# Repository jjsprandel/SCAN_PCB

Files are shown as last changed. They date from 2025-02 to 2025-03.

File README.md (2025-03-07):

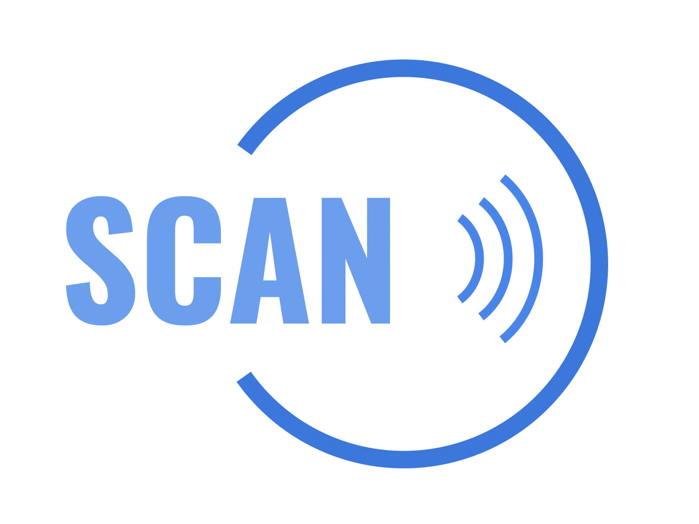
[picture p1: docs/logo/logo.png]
Project Logo
# 

Welcome to the **SCAN** repository! Below, you will find all the necessary information, from hardware design to software documentation.

---

## GitHub Workflows Status 🔧

Here are the current statuses of our GitHub workflows:

| Workflow Name | Status |
| --- | --- |
| **CI - Build** |  |
| **Docker - Test Build** |  |

- **CI - Build**: Ensures the project builds successfully.
- **CI - Tests**: Runs all unit and integration tests to ensure everything is working as expected.
- **Docker - Test Build**: Attempts Docker Build upon changes to the Dockerfile.

---

## Table of Contents 📚
- [💡 Overview](#overview)
- [🔧 Hardware Design](#hardware-design)
- [💻 Software](#software)
- [🔨 Build Instructions](#build-instructions)
- [📑 Documentation](#documentation)
- [⚙️ License](#license)

---

## 💡 Overview
 **SCAN** is a low-cost, IoT-driven kiosk system designed to provide real-time analytics based on check-in and check-out information. By integrating NFC-based authentication, real-time data processing, and a user-friendly interface, SCAN provides users with a near-effortless check-in experience and provides facilities with actionable insights for improving operations. SCAN is able to track attendance and provide detailed analytics on occupancy trends, peak usage hours, and visit durations. These insights are accessible to administrator and facility managers via SCAN’s web application, which can provide them with the necessary statistics to allocate resources efficiently, optimize staffing, and improve user experiences.

---

## 🔧 Hardware Design
<details>
  <summary><strong>📡 Schematic</strong></summary>

  Below is the schematic of the hardware design:

  Schematic
  
  **Key Features**:
  - Feature 1
  - Feature 2
  - Feature 3

  Additional hardware files can be found in the [hardware directory](hardware_design).

</details>

<details>
  <summary><strong>🔌 PCB Design</strong></summary>

  Here's the PCB design layout:

  PCB

  **Important Notes**:
  - Note about the PCB.
  - Power considerations.
  - Any important design choices.

</details>

---

## 💻 Software
<details>
  <summary><strong>💾 Firmware Overview</strong></summary>

  The firmware is designed to work with the hardware for controlling the device. You can find the code [here](path/to/firmware).

  **Key Libraries Used**:
  - Library 1
  - Library 2

</details>

<details>
  <summary><strong>📦 Installation Guide</strong></summary>

  Follow these steps to install the firmware:
  
  1. Step 1
  2. Step 2
  3. Step 3

  Detailed instructions are available in the [installation guide](link_to_guide).

</details>

---

## 🔨 Build Instructions

<details>
  <summary><strong>🛠️ Build Setup</strong></summary>

  To build the project, follow these steps:

  1. Clone the repository:
     ```bash
     git clone https://github.com/jjsprandel/SCAN.git
     ```
  2. Connect your ESP32 to your computer using USB-C. The Docker container is designed to automatically recognize the device and use port 4000 to communicate to the ESP32 for flashing.
  3. Reopen Visual Studio Code in Container. This step requires having the Docker VS Code extension installed on your host machine. 
  4. Within the container, on first run, configure the ESP-IDF extension from the list of commands that come with the ESP-IDF extension.
     4a. Select "Use existing setup."
     4b. The extension should automatically find the right tool paths and folders. Select the configuration option with the auto-filled paths.
  5. Compile the firmware:
     ```bash
     idf.py build
     ```  
      5a. Alternatively, click the wrench button at the bottom of VS Code to build.
  6. Flash the firmware:
     ```bash
     idf.py --port 'rfc2217://host.docker.internal:4000?ign_set_control' flash
     ```
      6a. Alternatively, click the lightning button at the bottom of VS Code to flash.

  **Tips**:
  - Ensure your system meets the requirements listed in the [build prerequisites](link_to_prerequisites).
  - If you encounter issues, check the [troubleshooting guide](link_to_troubleshooting).

</details>

---

## 📑 Documentation
<details>
  <summary><strong>📝 API Documentation</strong></summary>

  - **[API Reference](link_to_api_reference)**: Detailed API usage and function descriptions.
  - **[Hardware Docs](link_to_hardware_docs)**: Documentation on hardware design.

</details>

<details>
  <summary><strong>📚 Additional Resources</strong></summary>

  - **[Project Wiki](link_to_wiki)**: Explore the project wiki for more in-depth articles.
  - **[User Manual](link_to_user_manual)**: Comprehensive user guide for operation.

</details>

---

## 🔌 Dependencies

This project has the following dependencies that need to be installed:

### **Hardware Dependencies:**
- **KiCad Version**: 8.0.6 (required for schematic and PCB design)
  - Download from [KiCad official website](https://kicad.org/download/).
  
### **Software Dependencies:**
- **USB Drivers**: For proper communication with the hardware, ensure that the appropriate USB drivers are installed.
  - For Windows, you can download and install the **[CP210x USB to UART Bridge VCP drivers](https://www.silabs.com/developer-tools/usb-to-uart-bridge-vcp-drivers?tab=downloads)**.
  - For Linux, you should have the necessary drivers already built into the kernel, but check the [driver documentation](https://www.silabs.com/community/interface/usb-bridges) for troubleshooting.

- **Docker Desktop**: Required to run the ESP-IDF containerized environment.
  - Download from **[Docker Desktop website](https://www.docker.com/products/docker-desktop)**.
  - Follow the installation instructions for your operating system.
  
### **Development Tools:**
- **[Visual Studio Code](https://code.visualstudio.com/)**: Recommended IDE for editing the firmware code.

- **[Git](https://git-scm.com/)**: Version control system.

---

## ⚙️ License
SCAN © 2025 is licensed under Creative Commons Attribution-NonCommercial-NoDerivatives 4.0 International. To view a copy of this license, visit https://creativecommons.org/licenses/by-nc-nd/4.0/ or see the [LICENSE](LICENSE) file.

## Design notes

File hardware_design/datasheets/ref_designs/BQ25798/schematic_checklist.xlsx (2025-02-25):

 | BQ25790/2/8 and BQ25672 Schematic Review
 |  |  |  |  |  |  |  |  |  | BQ25792/BQ25798/BQ25672
 |  |  |  |  |  |  |  |  |  | BQ25790
 |  |  |  |  |  |  |  |  | NOTE: BQ25672 requires only 3x10uF
NOTE: All capacitors are assumed to be ceramic with voltage voltage rating = at least 2 x the pin's max expected voltage
Pin | QFN | WCSP | Opt/Rec/Req | Component | Min | Typ | Max | EXPLANATION | COMMENTS | LAYOUT GUIDANCE
VAC1 | 9 | H1 | Optional | CVAC1 |  | 100n F |  | VAC1 sense line filter capcacitor | Connect to VBUS if ACDRV1 not used.
VAC2 | 8 | G1 | Optional | CVAC2 |  | 100 nF |  | VAC2 sense line filter capcacitor | Connect to VBUS if ACDRV2 not used.
ACDRV1 | 11 | H2 | Optional | QACDRV1 |  | 30 V Nch |  | NFETs for input source MUX | Connect to ground if ACDRV1 not used.
 |  |  |  | DACDRV1 |  | 12V |  | Zener clamp to protect FET gate
 |  |  |  | RACDRV1 |  | 294 Ω |  | Softstart resistor
 |  |  |  | CACDRV1 |  | 1 nF |  | Softstart capacitor
ACDRV2 | 10 | G2 | Optional | QACDRV2 |  | 30 V Nch |  | NFETs for input source MUX | Connect to ground if ACDRV2 not used.
 |  |  |  | DACDRV2 |  | 12V |  | Zener clamp to protect FET gate
 |  |  |  | RACDRV2 |  | 294 Ω |  | Softstart resistor
 |  |  |  | CACDRV2 |  | 1 nF |  | Softstart capacitor
VBUS | 2,3 | A1,B1, C1 | Required | CVBUS-BYP |  | 0.1 uF |  | VBUS high frequency noise bypass capacitor
 |  |  | Required | CVBUS-BULK |  | 2 x 10uF |  | VBUS bulk capacitors
REGN | 5 | E1 | Required | CREGN | 4.7 uF |  |  | REGN linear regulation output capacitor |  | Place close to REGN pin and PGND, priority 2.
PMID | 29 | A2,B2,C2,D2,E2 | Required | CPMID-BYP |  | 0.1 uF |  | PMID high frequency noise bypass capacitor | Critical for device operation and minimizing EMI. | Place as close as possible to PMID and GND pins using as few vias as possible, priority 1
 |  |  | Required | CPMID-BULK |  | 3 x 10uF* |  | PMID bulk capacitors | Input capacitance for the converter *BQ25796 requires 2 additional, parallel 33 uF low ESR polarized capacitors | Place as close as possible to PMID and GND pins using as few vias as possible, priority 1
SYS | 25 | A6,B6,C6,D6,E6 | Required | CSYS-BYP |  | 0.1 uF |  | SYS high frequency noise bypass capacitor | Critical for device operation and minimizing EMI | Place as close as possible to SYS and GND pins using as few vias as possible, priority 1
 |  |  | Required | CSYS-BULK |  | 5 x 10uF -79x 3 x 10uF -672 |  | SYS bulk capacitors | Output capacitance for the converter | Place as close as possible to SYS and GND pins using as few vias as possible, priority 1
BAT | 22,23 | A7,B7,C7,D7,E7 | Required | CBAT |  | 2 x 10uF |  | BAT bulk capacitors |  | Place close to BAT pin and PGND, priority 2.
BATP | 18 | G7 | Required | RBATP |  | 100 Ω |  | BAT+ remote sense isolation resistor | Can short to IC BAT pin if remote sense not needed.
SW1 | 28 | A3,B3,C3,D3,E3 | Required | L1 | 1 uH |  | 2.2 uH | Inductor buck side connection | 1 uH for fSW = 1.5 MHz and 2.2 uH for fSW = 750 kHz | Required to route SWx traces under the IC and then uses vias to connect to inductor if on top layer.
 |  |  | Optional | RSNUB1, CSNUB1 |  | not shown |  | RC snubber to reduce EMI | 603 footprint components, sized on working PCB using empirical measurements. Decreases efficiency by ~0.5% when properly sized | Place close to SWx and PGND, priority 1. If placed on bottom layer, use multiple vias back to top.
BTST1 | 4 | D1 | Required | CBTST1 |  | 0.047 uF |  | Bootstrap capacitor for buck side FET gate drive
SW2 | 26 | A5,B5,C5,D5,E5 | Required | L1 | 1 uH |  | 2.2 uH | Inductor boost side connection | 1 uH for fSW = 1.5 MHz and 2.2 uH for fSW = 750 kHz | Required to route SWx traces under the IC and then uses vias to connect to inductor if on top layer.
 |  |  | Optional | RSNUB2, CSNUB2 |  | not shown |  | RC snubber to reduce EMI | 603 footprint components, sized on working PCB using empirical measurements. Decreases efficiency by ~0.5% when properly sized | Place close to SWx and PGND, priority 1. If placed on bottom layer, use multiple vias back to top.
BTST2 | 19 | F7 | Required | CBTST2 |  | 0.047 uF |  | Bootstrap capacitor for boost side FET gate drive
PROG | 20 | F5 | Required | RPROG |  | *Ω |  | Sets default converter switching frequency and either 1S, 2S, 3S or 4S charging | See datasheet section titled PROG Pin Configuration for resistor sizes
ILIM_HIZ | 17 | F4 | Required | RLIM |  | *Ω |  | Program ILIM_HIZ voltage to set desired IINDPM by connecting a resistor divider from pull up rail to ILIM_HIZ pin then 100 kW resistor to ground. When the pin voltage is below 0.75V, the buck-boost converter enters non-switching mode with REGN on. | VILIM_HIZ = 1V + 800 mW x IINDPMmax IINDPM I2C register can be written to lower value. ILIM_HIZ can be disabled in I2C. ILIM_HIZ can be pulled directly to REGN to set max I2C register value (3.3A).
TS | 16 | H7 | Required (if not disabled in I2C register) | RTS-TOP |  | *Ω |  | Resistor divider to set window for thermistor temperature-based battery charging profile | If TS feature not used, use equations to set V(TS) to ~60% of VREF to hardware disable or I2C bit to software disable.
 |  |  | Required (if not disabled in I2C register) | RTS-BOT |  | *Ω |  |  |  | Connect RTS_BOT to AGND. Kelvin connect resistor divider midpoint to pin routed away from traces/pours/planes with switching noise.
STAT | 1 | F1 | Recommended | RSTAT |  | 2.2 kΩ |  | LED pull up resistor for open drain STAT pin.
 |  |  | Optional | DSTAT |  | green or red |  | Charging status indicating LED
SDRV | 24 | F6 | Optional | QSDRV |  | 30 V Nch |  | The driver pin of the external ship FET. The ship FET is always turned on when ship mode is disabled, and it keeps off when the charger is in ship mode or shutdown mode. | Connect a 0402 / 50V / 1nF ceramic capacitor from SDRV to BAT or GND when the ship FET is not used.
/CE | 13 | G4 | Required | RPULLUP | 2.2 kW |  | 10 kW | Active low, open drain charge enable | Can be tied to GND but recommended to be tied to host GPIO with pull up resistor. Cannot be left floating.
/INT | 21 | G5 | Optional | RPULLUP | 2.2 kW |  | 10 kW | Active low, open drain INT pulse | Can be left floating but recommend to to tied to host GPIO with pull up resistor.
/QON | 12 | G3 | Optional |  |  |  |  | A logic low on this pin with tSM_EXIT duration turns on ship FET to force the device to exit the ship mode. A logic low on this pin with tRST duration resets system power by turning off the ship FET for tRST_SFET (also setting the charger in HIZ mode when VBUS is high) and then turning on ship FET (also disabling the charger HIZ mode) to provide full system power reset | The pin has an internal pull up so it not used it should be left floating. Can be tied to a mechanical push button or host GPIO.
SDA | 15 | H5 | Required | RPULLUP | 2.2 kW |  | 10 kW | I2C data line | Needs pull up resistor to 1.8 V to 3.3 V
SCL | 14 | H4 | Required | RPULLUP | 2.2 kW |  | 10 kW | I2C clock like | Needs pull up resistor to 1.8 V to 3.3 V
D+ | 6 | F2 | Optional |  |  |  |  | USB BC 1.2 communication lines | Connect to USB port in order to set charger input current (IINDPM) register to port capability per USB BC 1.2 spec. Host is expected to perform enumeration. If not used, leave floating for unkown adapter and IINDPM=3A. ILIM_HIZ resistor clamps maximum input current.
D- | 7 | F3 | Optional
BATN (790 only) | na | G6 | Required | RBATN |  | 100 Ω |  | BAT- remote sense isolation resistor | Can short to IC GND pin if remote sense not needed.
/PG (790 only) | na | H3 | Optional | RPULLUP | 2.2 kW |  | 10 kW | Active low, open drain input power good indicator | Can be left floating but recommend to to tied to host GPIO with pull up resistor.
IBAT (790 only) | na | H6 | Optional | RIBATP |  | 10 kW |  | Current source output proivding 25 uA per 1A charge current. | Parallel 100 pF capacitor is recommended to minimize ripple.
GND | 27 | A4,B4,C4,D4,E4 | Required |  |  |  |  | IC GND return | Separate PGND and AGND, connected only at GND pins is recommended by not required as long as power path (VBUS, PMID, SYS, BAT) grounds are routed away from AGND. REGN is technically PGND but difficult to route. | Required to route to internal/bottom layer under the IC but also provide GND trace on top layer for connecting PMID and SYS capacitor grounds

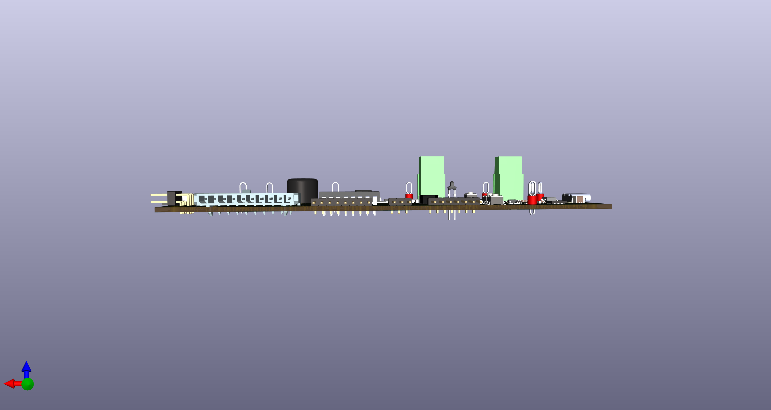
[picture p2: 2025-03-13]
hardware_design/exports/3d_models/side_3.png

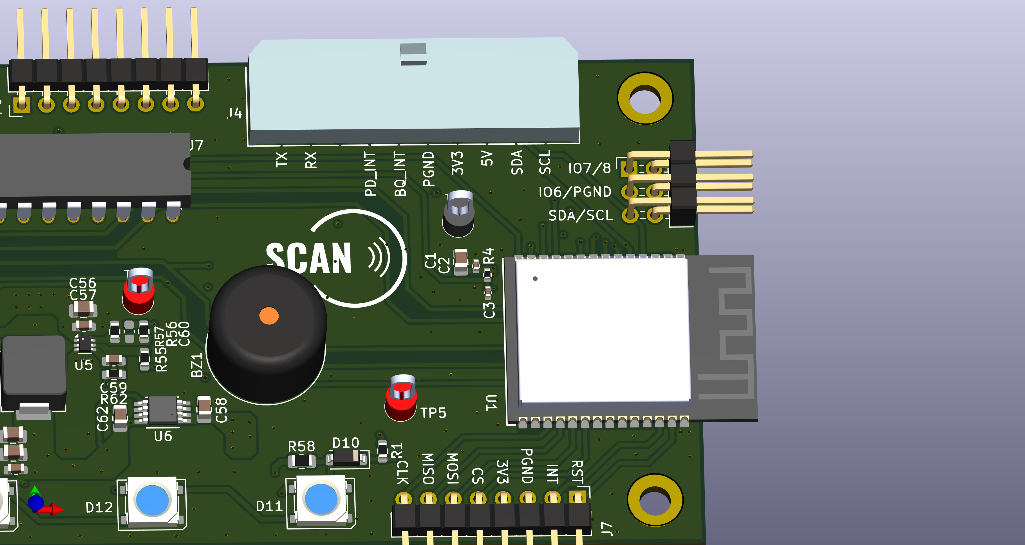
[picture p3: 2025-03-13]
hardware_design/exports/3d_models/esp32.png

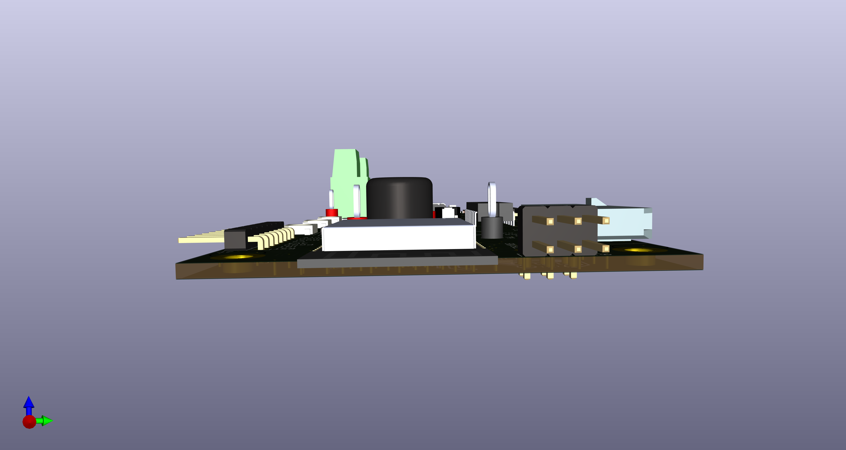
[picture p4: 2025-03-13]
hardware_design/exports/3d_models/side_4.png

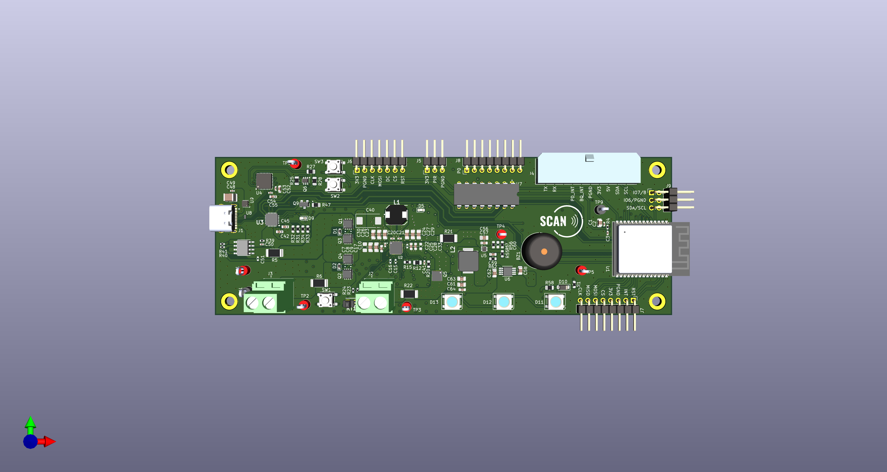
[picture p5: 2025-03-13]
hardware_design/exports/3d_models/full_front.png

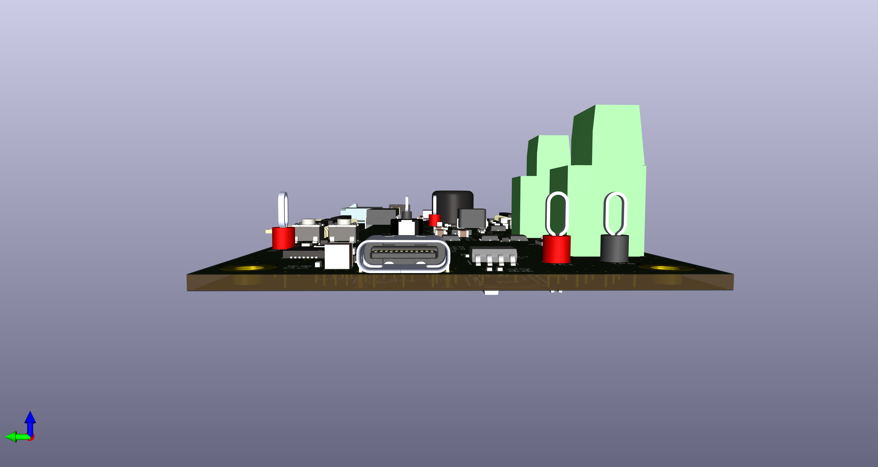
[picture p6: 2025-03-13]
hardware_design/exports/3d_models/side_2.png

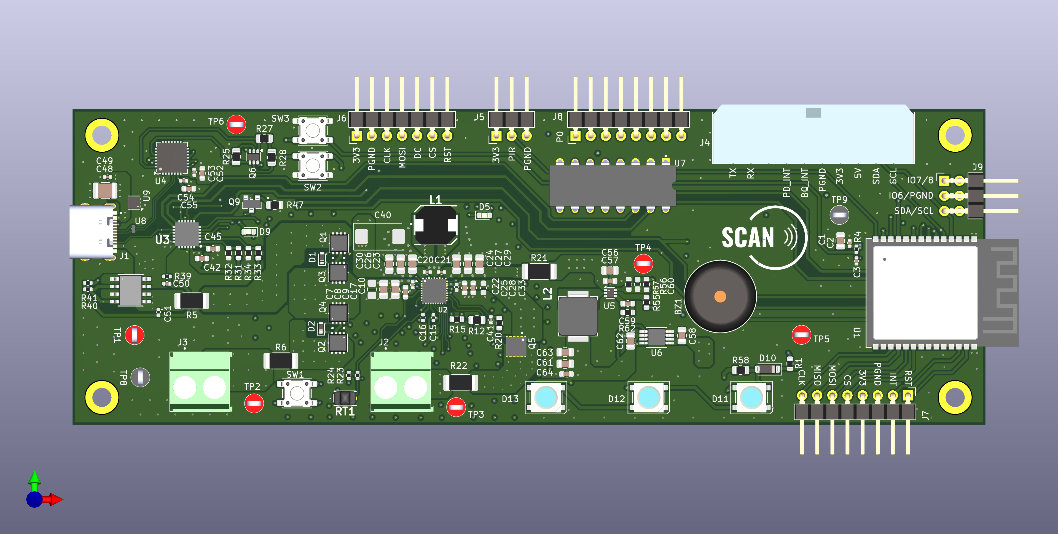
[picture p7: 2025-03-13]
hardware_design/exports/3d_models/full_front_zoomed.png

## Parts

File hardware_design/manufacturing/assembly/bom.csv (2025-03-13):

Reference | Value | Footprint | DNP | Manufacturer_Name | Manufacturer Part Number | JLCPCB Part Number | DigiKey Part Number
BZ1 | Buzzer | Buzzer_Beeper:Buzzer_12x9.5RM7.6
C1 | 10u | Capacitor_SMD:C_0805_2012Metric |  | Murata Electronics | GRM21BZ71E106KE15L | C237493
C2 | 0.1u | Capacitor_SMD:C_0402_1005Metric |  | YAGEO | CC0402KRX7R9BB104 | C131394
C3 | 1u | Capacitor_SMD:C_0402_1005Metric |  | Murata Electronics | GRM155R61E105KA12D | C77009
C4 | 1u | Capacitor_SMD:C_0805_2012Metric | DNP | Murata Electronics | GRM219R71E105KA88D | C86035
C5 | 1u | Capacitor_SMD:C_0805_2012Metric | DNP | Murata Electronics | GRM219R71E105KA88D | C86035
C6 | 10u | Capacitor_SMD:C_0805_2012Metric | DNP | Murata Electronics | GRM21BR61E106KA73L | C84416
C7 | 10u | Capacitor_SMD:C_0805_2012Metric_Pad1.18x1.45mm_HandSolder | DNP | Murata Electronics | GRM21BR61E106KA73L | C84416
C8 | 10u | Capacitor_SMD:C_0805_2012Metric_Pad1.18x1.45mm_HandSolder |  | Murata Electronics | GRM21BR61E106KA73L | C84416
C9 | 10u | Capacitor_SMD:C_0805_2012Metric_Pad1.18x1.45mm_HandSolder |  | Murata Electronics | GRM21BR61E106KA73L | C84416
C10 | 0.1u | Capacitor_SMD:C_0402_1005Metric |  | Murata Electronics | GRM155R71H104KE14D | C77020
C11 | 0.1u | Capacitor_SMD:C_0402_1005Metric |  | Murata Electronics | GRM155R71H104KE14D | C77020
C12 | 1n | Capacitor_SMD:C_0402_1005Metric |  | Murata Electronics | GRM1555C1H102FA01D | C161523
C13 | 1n | Capacitor_SMD:C_0402_1005Metric |  | Murata Electronics | GRM1555C1H102FA01D | C161523
C14 | 0.1u | Capacitor_SMD:C_0402_1005Metric |  | Murata Electronics | GRM155R71H104KE14D | C77020
C15 | 0.01u | Capacitor_SMD:C_0402_1005Metric | DNP | KEMET | C0402C103J5RACTU | C2167955
C16 | 0.01u | Capacitor_SMD:C_0402_1005Metric | DNP | KEMET | C0402C103J5RACTU | C2167955
C17 | 4.7u | Capacitor_SMD:C_0603_1608Metric |  | Murata Electronics | GRM188R61C475KAAJD | C86016
C18 | 47n | Capacitor_SMD:C_0402_1005Metric |  | Murata Electronics | GRM155R71E473KA88D | C77017
C19 | 47n | Capacitor_SMD:C_0402_1005Metric |  | Murata Electronics | GRM155R71E473KA88D | C77017
C20 | 0.1u | Capacitor_SMD:C_0402_1005Metric |  | Murata Electronics | GRM155R71H104KE14D | C77020
C21 | 0.1u | Capacitor_SMD:C_0402_1005Metric |  | Murata Electronics | GRM155R71H104KE14D | C77020
C22 | 0.1u | Capacitor_SMD:C_0402_1005Metric | DNP | Murata Electronics | GRM155R71H104KE14D | C77020
C23 | 10u | Capacitor_SMD:C_0805_2012Metric_Pad1.18x1.45mm_HandSolder |  | Murata Electronics | GRM21BR61E106KA73L | C84416
C24 | 10u | Capacitor_SMD:C_0805_2012Metric_Pad1.18x1.45mm_HandSolder |  | Murata Electronics | GRM21BR61E106KA73L | C84416
C25 | 10u | Capacitor_SMD:C_0603_1608Metric |  | Murata Electronics | GRT188R61E106ME13D | C697423
C26 | 10u | Capacitor_SMD:C_0805_2012Metric_Pad1.18x1.45mm_HandSolder |  | Murata Electronics | GRM21BR61E106KA73L | C84416
C27 | 10u | Capacitor_SMD:C_0805_2012Metric_Pad1.18x1.45mm_HandSolder |  | Murata Electronics | GRM21BR61E106KA73L | C84416
C28 | 10u | Capacitor_SMD:C_0603_1608Metric |  | Murata Electronics | GRT188R61E106ME13D | C697423
C29 | 10u | Capacitor_SMD:C_0805_2012Metric_Pad1.18x1.45mm_HandSolder |  | Murata Electronics | GRM21BR61E106KA73L | C84416
C30 | 10u | Capacitor_SMD:C_0805_2012Metric_Pad1.18x1.45mm_HandSolder |  | Murata Electronics | GRM21BR61E106KA73L | C84416
C31 | 1n | Capacitor_SMD:C_0402_1005Metric | DNP | Murata Electronics | GRM1555C1H102FA01D | C161523
C32 | 10u | Capacitor_SMD:C_0805_2012Metric_Pad1.18x1.45mm_HandSolder |  | Murata Electronics | GRM21BR61E106KA73L | C84416
C33 | 10u | Capacitor_SMD:C_0603_1608Metric | DNP | Murata Electronics | GRT188R61E106ME13D | C697423
C34 | 10u | Capacitor_SMD:C_0805_2012Metric_Pad1.18x1.45mm_HandSolder | DNP | Murata Electronics | GRM21BR61E106KA73L | C84416
C35 | 10u | Capacitor_SMD:C_0805_2012Metric_Pad1.18x1.45mm_HandSolder |  | Murata Electronics | GRM21BR61E106KA73L | C84416
C36 | 10u | Capacitor_SMD:C_0805_2012Metric_Pad1.18x1.45mm_HandSolder | DNP | Murata Electronics | GRM21BR61E106KA73L | C84416
C37 | 10u | Capacitor_SMD:C_0805_2012Metric_Pad1.18x1.45mm_HandSolder | DNP | Murata Electronics | GRM21BR61E106KA73L | C84416
C38 | 33u | Capacitor_Tantalum_SMD:CP_EIA-7343-31_Kemet-D | DNP | Murata Electronics | ECASD41E336M040KA0 | C2161642
C39 | 33u | Capacitor_Tantalum_SMD:CP_EIA-7343-31_Kemet-D | DNP | KEMET | T521D336M035ATE065 | C696815
C40 | 33u | Capacitor_Tantalum_SMD:CP_EIA-7343-31_Kemet-D | DNP | Murata Electronics | ECASD41E336M040KA0 | C2161642
C41 | 47n | Capacitor_SMD:C_0402_1005Metric |  | Murata Electronics | GRM155R71E473KA88D | C77017
C42 | 1u | Capacitor_SMD:C_0603_1608Metric |  | Murata Electronics | GCM188R71C105KA64D | C161212
C43 | 0.1u | Capacitor_SMD:C_0402_1005Metric |  | Murata Electronics | GRM155R71A104KA01D | C71687
C44 | 0.1u | Capacitor_SMD:C_0402_1005Metric |  | Murata Electronics | GRM155R71A104KA01D | C71687
C45 | 1u | Capacitor_SMD:C_0603_1608Metric |  | Murata Electronics | GCM188R71C105KA64D | C161212
C46 | 390p | Capacitor_SMD:C_0603_1608Metric |  | YAGEO | CC0603JRX7R9BB391 | C519518
C47 | 390p | Capacitor_SMD:C_0603_1608Metric |  | YAGEO | CC0603JRX7R9BB391 | C519518
C48 | 3.3u | Capacitor_SMD:C_1210_3225Metric |  | Murata Electronics | GRM32DR71H335KA88L | C397310
C49 | 100n | Capacitor_SMD:C_0402_1005Metric |  | Taiyo Yuden | GMK105BJ104KV-F | C187828
C50 | 1u | Capacitor_SMD:C_0402_1005Metric |  | Samsung Electro-Mechanics | CL05A105KL5NRNC | C307413
C51 | 1u | Capacitor_SMD:C_0402_1005Metric | DNP | TDK Corporation | C1005X5R1V105K050BC |  | 445-9073-1-ND
C52 | 4.7u | Capacitor_SMD:C_0603_1608Metric |  | Murata Electronics | GRM188R61C475KAAJD | C86016
C53 | 0.1u | Capacitor_SMD:C_0402_1005Metric |  | Murata Electronics | GRM155R71A104KA01D | C71687
C54 | 0.1u | Capacitor_SMD:C_0402_1005Metric |  | Murata Electronics | GRM155R71A104KA01D | C71687
C55 | 4.7u | Capacitor_SMD:C_0603_1608Metric |  | Murata Electronics | GRM188R61C475KAAJD | C86016
C56 | 10u | Capacitor_SMD:C_0805_2012Metric |  | Murata Electronics | GRM21BR61E106MA73L | C391262
C57 | 0.1u | Capacitor_SMD:C_0603_1608Metric |  | YAGEO | CC0603KRX7R9BB104 | C14663
C58 | 2.2u | Capacitor_SMD:C_0805_2012Metric |  | YAGEO | CC0805KKX7R9BB225 | C125847
C59 | 0.1u | Capacitor_SMD:C_0603_1608Metric |  | YAGEO | CC0603KRX7R9BB104 | C14663
C60 | 18p | Capacitor_SMD:C_0603_1608Metric | DNP
C61 | 22u | Capacitor_SMD:C_0805_2012Metric |  | Murata Electronics | GRM21BR61A226ME44L | C441864
C62 | 1u | Capacitor_SMD:C_0805_2012Metric |  | YAGEO | CC0805KKX7R9BB105 | C91185
C63 | 22u | Capacitor_SMD:C_0805_2012Metric |  | Murata Electronics | GRM21BR61A226ME44L | C441864
C64 | 0.1u | Capacitor_SMD:C_0603_1608Metric |  | YAGEO | CC0603KRX7R9BB104 | C14663
D1 | 12V | Diode_SMD:D_SOD-523 |  | Diodes Incorporated | BZT52C12T-7 | C507911
D2 | 12V | Diode_SMD:D_SOD-523 |  | Diodes Incorporated | BZT52C12T-7 | C507911
D3 | 40V | Diode_SMD:D_SOD-523 | DNP | Diodes Incorporated | ZLLS350TA | C139441
D4 | 40V | Diode_SMD:D_SOD-523 | DNP | Diodes Incorporated | ZLLS350TA | C139441
D5 | GREEN | LED_SMD:LED_0603_1608Metric |  | Lite-On Inc. | LTST-C190KGKT | C125094
D6 | 40V | Diode_SMD:D_SOD-523 | DNP | Diodes Incorporated | ZLLS350TA | C139441
D7 | 12V | Diode_SMD:D_SOD-523 | DNP | Diodes Incorporated | BZT52C12T-7 | C507911
D8 | NZH10C-115 | SCAN_footprints:SODFL3516X120N |  | Nexperia USA Inc. | NZH10C,115 | C551630
D9 | RED | LED_SMD:LED_0603_1608Metric |  | Lite-On Inc. | LTST-C190EKT | C364560
D10 | 1N4148W | Diode_SMD:D_SOD-123 |  | Jiangsu Changjing Electronics Technology Co., Ltd. | 1N4448W | C8601
D11 | WS2812B | LED_SMD:LED_WS2812B_PLCC4_5.0x5.0mm_P3.2mm |  | SparkFun Electronics | COM-16347 |  | 1568-COM-16347CT-ND
D12 | WS2812B | LED_SMD:LED_WS2812B_PLCC4_5.0x5.0mm_P3.2mm |  | SparkFun Electronics | COM-16347 |  | 1568-COM-16347CT-ND
D13 | WS2812B | LED_SMD:LED_WS2812B_PLCC4_5.0x5.0mm_P3.2mm |  | SparkFun Electronics | COM-16347 |  | 1568-COM-16347CT-ND
J1 | USB_C_16P_Connector | SCAN_footprints:HRO_TYPE-C-31-M-12 |  | Korean Hroparts Elec | TYPE-C-31-M-12 | C165948
J2 | Batt_Connector | SCAN_footprints:TE_282856-2 |  | TE Connectivity AMP Connectors | 282856-2 |  | A98355-ND
J3 | PV_Panel_Connector | SCAN_footprints:TE_282856-2 |  | TE Connectivity AMP Connectors | 282856-2 |  | A98355-ND
J4 | Conn_01x10 | SCAN_footprints:CONN_SD-43650-001_10_MOL |  | Molex | 0436501000 |  | 23-0436501000-ND
J5 | PIR_CONNECTOR | Connector_PinHeader_2.54mm:PinHeader_1x03_P2.54mm_Horizontal
J6 | TFT_CONN | Connector_PinHeader_2.54mm:PinHeader_1x07_P2.54mm_Horizontal
J7 | PN532_CONN | Connector_PinHeader_2.54mm:PinHeader_1x08_P2.54mm_Horizontal
J8 | Keypad | Connector_PinHeader_2.54mm:PinHeader_1x08_P2.54mm_Horizontal
J9 | GPIO_BREAKOUT | Connector_PinHeader_2.54mm:PinHeader_2x03_P2.54mm_Horizontal
L1 | 1.0u | SCAN_footprints:SPM6530 |  | TDK Corporation | SPM6530T-1R0M120 | C87572
L2 | 4.7u | SCAN_footprints:WE-LHMI_7030_705048 |  | Wurth Elektronik | 74437349047 |  | 732-3354-1-ND
Q1 | CSD17581Q3A | SCAN_footprints:TRANS_CSD17581Q3A |  | Texas Instruments | CSD17581Q3AT | C2866708
Q2 | CSD17581Q3A | SCAN_footprints:TRANS_CSD17581Q3A |  | Texas Instruments | CSD17581Q3AT | C2866708
Q3 | CSD17581Q3A | SCAN_footprints:TRANS_CSD17581Q3A |  | Texas Instruments | CSD17581Q3AT | C2866708
Q4 | CSD17581Q3A | SCAN_footprints:TRANS_CSD17581Q3A |  | Texas Instruments | CSD17581Q3AT | C2866708
Q5 | CSD17575Q3 | SCAN_footprints:TRANS_CSD17575Q3 |  | Texas Instruments | CSD17575Q3T | C2865030
Q6 | BC847BDW1 | Package_TO_SOT_SMD:SOT-363_SC-70-6 |  | onsemi | BC847BDW1T1G | C82368
Q7 | IRF9358TRPBF | SCAN_footprints:SO8_IRF9358TRPBF_INF |  | Infineon Technologies | IRF9358TRPBF | C537847
Q8 | BSL308PE | SCAN_footprints:PG-TSOP6-6-4_INF |  | Infineon Technologies | BSL308PEH6327XTSA1 |  | BSL308PEH6327XTSA1CT-ND
Q9 | NTR4503NT1G | SCAN_footprints:SOT23_318-08_ONS |  | onsemi | NTR4503NT1G | C94763
R1 | 3.3k | Resistor_SMD:R_0603_1608Metric |  | YAGEO | RC0603FR-073K3L | C108078
R2 | 2.2k | Resistor_SMD:R_0805_2012Metric |  | YAGEO | RC0805FR-072K2L | C114561
R3 | 2.2k | Resistor_SMD:R_0805_2012Metric |  | YAGEO | RC0805FR-072K2L | C114561
R4 | 10k | Resistor_SMD:R_0402_1005Metric |  | YAGEO | RC0402FR-7W10KL | C851848
R5 | 0.01 | Resistor_SMD:R_2010_5025Metric |  | Vishay Dale | WSL2010R0100FEA18 | C844898
R6 | 0.01 | Resistor_SMD:R_2010_5025Metric |  | Vishay Dale | WSL2010R0100FEA18 | C844898
R7 | 10k | Resistor_SMD:R_0805_2012Metric |  | Vishay Dale | CRCW080510K0FKEAC | C844814
R8 | 100k | Resistor_SMD:R_0402_1005Metric | DNP | YAGEO | RC0402FR-07100KL | C60491
R9 | 100k | Resistor_SMD:R_0402_1005Metric | DNP | YAGEO | RC0402FR-07100KL | C60491
R10 | 0 | Resistor_SMD:R_0805_2012Metric | DNP | Keystone Electronics | 5106 | C2073530 | 36-5106CT-ND
R11 | 0 | Resistor_SMD:R_0805_2012Metric | DNP | Keystone Electronics | 5106 | C2073530 | 36-5106CT-ND
R12 | 0 | Resistor_SMD:R_0805_2012Metric |  | YAGEO | RC0805JR-070RL | C96345
R13 | 294 | Resistor_SMD:R_0603_1608Metric |  | YAGEO | RC0603FR-07294RL | C185345
R14 | 294 | Resistor_SMD:R_0603_1608Metric |  | YAGEO | RC0603FR-07294RL | C185345
R15 | 18k | Resistor_SMD:R_0603_1608Metric |  | YAGEO | AC0603FR-0718KL | C144693
R16 | 2.2k | Resistor_SMD:R_0402_1005Metric |  | YAGEO | RC0402FR-072K21L | C138019
R17 | 0 | Resistor_SMD:R_0603_1608Metric |  | Vishay Dale | CRCW06030000Z0EA | C844915
R18 | 100k | Resistor_SMD:R_0402_1005Metric | DNP | YAGEO | RC0402FR-07100KL | C60491
R19 | 0 | Resistor_SMD:R_0805_2012Metric | DNP | Keystone Electronics | 5106 | C2073530 | 36-5106CT-ND
R20 | 100 | Resistor_SMD:R_0603_1608Metric |  | YAGEO | RC0603FR-07100RL | C105588
R21 | 0.01 | Resistor_SMD:R_2010_5025Metric |  | Vishay Dale | WSL2010R0100FEA18 | C844898
R22 | 0.01 | Resistor_SMD:R_2010_5025Metric |  | Vishay Dale | WSL2010R0100FEA18 | C844898
R23 | 5.23k | Resistor_SMD:R_0402_1005Metric |  | Vishay Dale | CRCW04025K23FKED | C2076550
R24 | 30.1k | Resistor_SMD:R_0402_1005Metric |  | YAGEO | RC0402FR-0730K1L | C138009
R25 | 10k | Resistor_SMD:R_0805_2012Metric |  | Vishay Dale | CRCW080510K0FKEAC | C844814
R26 | 0 | Resistor_SMD:R_0805_2012Metric |  | YAGEO | RC0805JR-070RL | C96345
R27 | 10k | Resistor_SMD:R_0805_2012Metric |  | Vishay Dale | CRCW080510K0FKEAC | C844814
R28 | 0 | Resistor_SMD:R_0805_2012Metric |  | YAGEO | RC0805JR-070RL | C96345
R29 | 0 | Resistor_SMD:R_0805_2012Metric |  | YAGEO | RC0805JR-070RL | C96345
R30 | 49.9k | Resistor_SMD:R_0402_1005Metric |  | KOA Speer Electronics, Inc. | RK73H1ETTP4992F | C173335
R31 | 5k | Resistor_SMD:R_0603_1608Metric |  | Vishay Dale | CRCW06034K99FKEA | C844793
R32 | 1k | Resistor_SMD:R_0603_1608Metric |  | Vishay Dale | CRCW06031K00FKEA | C844920
R33 | 5k | Resistor_SMD:R_0603_1608Metric |  | Vishay Dale | CRCW06034K99FKEA | C844793
R34 | 2.4k | Resistor_SMD:R_0603_1608Metric |  | Panasonic Electronic Components | ERJ-3GEYJ242V | C403460
R35 | 5k | Resistor_SMD:R_0603_1608Metric |  | Vishay Dale | CRCW06034K99FKEA | C844793
R36 | 5k | Resistor_SMD:R_0603_1608Metric |  | Vishay Dale | CRCW06034K99FKEA | C844793
R37 | 5k | Resistor_SMD:R_0603_1608Metric | DNP | Vishay Dale | CRCW06034K99FKEA | C844793
R38 | 1k | Resistor_SMD:R_0603_1608Metric |  | Vishay Dale | CRCW06031K00FKEA | C844920
R39 | 10k | Resistor_SMD:R_0402_1005Metric |  | YAGEO | RC0402JR-0710KL | C60489
R40 | 0 | Resistor_SMD:R_0402_1005Metric |  | YAGEO | RC0402FR-070RL | C106231
R41 | 1k | Resistor_SMD:R_0402_1005Metric |  | YAGEO | RC0402JR-071KL | C105637
R42 | 49.9k | Resistor_SMD:R_0402_1005Metric |  | KOA Speer Electronics, Inc. | RK73H1ETTP4992F | C173335
R43 | 1k | Resistor_SMD:R_0402_1005Metric |  | YAGEO | RC0402JR-071KL | C105637
R44 | 2k | Resistor_SMD:R_0805_2012Metric |  | YAGEO | RC0805JR-072KL | C114748
R45 | 2k | Resistor_SMD:R_0805_2012Metric |  | YAGEO | RC0805JR-072KL | C114748
R46 | 0.01 | Resistor_SMD:R_2010_5025Metric |  | Vishay Dale | WSL2010R0100FEA18 | C844898
R47 | 100k | Resistor_SMD:R_0805_2012Metric |  | Panasonic Electronic Components | ERJ-P06F1003V | C441992
R48 | 1k | Resistor_SMD:R_0603_1608Metric |  | Vishay Dale | CRCW06031K00FKEA | C844920
R49 | 47.5k | Resistor_SMD:R_0402_1005Metric |  | YAGEO | RC0402FR-0747K5L | C137974
R50 | 22.1k | Resistor_SMD:R_0402_1005Metric |  | YAGEO | RC0402FR-0722K1L | C163478
R51 | 1k | Resistor_SMD:R_0402_1005Metric |  | YAGEO | RC0402JR-071KL | C105637
R52 | 0 | Resistor_SMD:R_0805_2012Metric |  | YAGEO | RC0805JR-070RL | C96345
R53 | 0 | Resistor_SMD:R_0805_2012Metric |  | YAGEO | RC0805JR-070RL | C96345
R54 | 10k | Resistor_SMD:R_0805_2012Metric | DNP | Vishay Dale | CRCW080510K0FKEAC | C844814
R55 | 100k | Resistor_SMD:R_0603_1608Metric |  | Vishay Dale | CRCW0603100KJNEA | C844723
R56 | 220k | Resistor_SMD:R_0603_1608Metric |  | YAGEO | RC0603FR-07220KL | C123420
R57 | 30k | Resistor_SMD:R_0603_1608Metric |  | YAGEO | RC0603FR-0730KL | C100001
R58 | 10k | Resistor_SMD:R_0805_2012Metric |  | Vishay Dale | CRCW080510K0FKEAC | C844814
R59 | 10k | Resistor_SMD:R_0805_2012Metric |  | Vishay Dale | CRCW080510K0FKEAC | C844814
R60 | 10k | Resistor_SMD:R_0805_2012Metric |  | Vishay Dale | CRCW080510K0FKEAC | C844814
R61 | 10k | Resistor_SMD:R_0805_2012Metric |  | Vishay Dale | CRCW080510K0FKEAC | C844814
R62 | 0 | Resistor_SMD:R_0603_1608Metric |  | Vishay Dale | CRCW06030000Z0EA | C844915
RT1 | 10k | SCAN_footprints:103AT2 |  | Vishay Beyschlag/Draloric/BC Components | NTCLE100E3103JB0 | C141588
SW1 | QON | SCAN_footprints:SW_SPST_PTS647_Sx38 |  | C&K | PTS647SM38SMTR2 LFS |  | PTS647SM38SMTR2LFSCT-ND
SW2 | BOOT | SCAN_footprints:SW_SPST_PTS647_Sx38 |  | C&K | PTS647SM38SMTR2 LFS |  | PTS647SM38SMTR2LFSCT-ND
SW3 | RST | SCAN_footprints:SW_SPST_PTS647_Sx38 |  | C&K | PTS647SM38SMTR2 LFS |  | PTS647SM38SMTR2LFSCT-ND
TP1 | RED | SCAN_footprints:TP_5010 |  | Keystone Electronics | 5010 | C2906765
TP2 | RED | SCAN_footprints:TP_5010 |  | Keystone Electronics | 5010 | C2906765
TP3 | RED | SCAN_footprints:TP_5010 |  | Keystone Electronics | 5010 | C2906765
TP4 | RED | SCAN_footprints:TP_5010 |  | Keystone Electronics | 5010 | C2906765
TP5 | RED | SCAN_footprints:TP_5010 |  | Keystone Electronics | 5010 | C2906765
TP6 | RED | SCAN_footprints:TP_5010 |  | Keystone Electronics | 5010 | C2906765
TP8 | BLACK | SCAN_footprints:TP_5011 |  | Keystone Electronics | 5011 | C238127
TP9 | BLACK | SCAN_footprints:TP_5011 |  | Keystone Electronics | 5011 | C238127
U1 | ESP32-C6-WROOM-1-N8 | SCAN_footprints:ESP32-C6-WROOM-1-N8 |  | Espressif Systems | ESP32-C6-WROOM-1-N8 | C5366877
U2 | BQ25798RQMR | SCAN_footprints:IC_BQ25798RQMR |  | Texas Instruments | BQ25798RQMR | C2876593
U3 | CYPD3177-24LQXQT | SCAN_footprints:QFN50P400X400X60-25N-D |  | Infineon Technologies | CYPD3177-24LQXQT | C2952489
U4 | CP2102N-A02-xQFN28 | Package_DFN_QFN:QFN-28-1EP_5x5mm_P0.5mm_EP3.35x3.35mm |  | Silicon Labs | CP2102N-A02-GQFN28 | C1550553
U5 | TPS563203 | Package_TO_SOT_SMD:SOT-563 |  | Texas Instruments | TPS563203DRLR | C22445512
U6 | TLV76733DGNR | SCAN_footprints:VSSOP8_DGN_TEX |  | Texas Instruments | TLV76733DGNR | C2873382
U7 | PCF8574 | SCAN_footprints:DIP794W45P254L1969H508Q16 |  | Texas Instruments | PCF8574N | C2879047
U8 | ESD122 | SCAN_footprints:DMY0003A |  | Texas Instruments | ESD122DMYR | C1975871
U9 | TVS2200DRV | Package_SON:WSON-6-1EP_2x2mm_P0.65mm_EP1x1.6mm |  | Texas Instruments | TVS2200DRVR | C523793

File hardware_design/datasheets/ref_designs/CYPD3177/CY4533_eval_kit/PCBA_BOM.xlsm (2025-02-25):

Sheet: Revision History
CYPRESS SEMICONDUCTOR © 2017
Revision | Date | Description | Prepared By | Approved By
1 | 2018-09-17 | First version of CY4533 BOM | KUMR | PDS
 |  |  |  |  | a

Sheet: PCBA BOM
 |  |  |  |  | CYPRESS SEMICONDUCTOR © 2018-2019
 |  |  |  |  | TITLE | CY4533 BCR Evaluation Kit
 |  |  |  |  | PCA Number & Revision | 121-60538-01 | Rev 02
 |  |  |  |  | Schematics Number & Revision | 630-60538-01 | Rev 02
 |  |  |  |  | DATE | 2019-03-27
 |  |  |  |  | BOM REVISION | Rev 03
 |  |  |  |  | ROHS Compliance | Required
 |  |  |  |  | UL Compliance | Required
# | Cypress Part # | Qty | Reference | Value | Description | Manufacturer | Mfr Part # | Alternate Manufacturer | Alternate Mfr Part #
1 |  | 2 | C1,C4 | 1uF | CAP CER 1UF 16V X7R 0603 | KEMET | C0603C105K4RACTU
2 |  | 2 | C2,C3 | 0.1uF | CAP CER 0.1UF 10V X7R 0402 | AVX Corporation | 0402ZC104KAT2A
3 |  | 2 | C5,C6 | 390pF | CAP CER 390PF 50V 5% X7R 0603 | Kemet | C0603C391J5RACTU
4 |  | 1 | C7 | 3.3uF | CAP CER 3.3UF 50V X7R 1210 | KEMET | C1210C335K5RACAUTO
5 |  | 1 | C8 | 1uF | CAP CER 1UF 35V X5R 0402 | Samsung Electro-Mechanics | CL05A105KL5NRNC
6 |  | 1 | D1 | RED | LED RED CLEAR 0603 SMD | Lite-On Inc. | LTST-C190EKT
7 |  | 1 | D2 | GREEN | LED GREENCLEAR 0603 SMD | Lite-On Inc. | LTST-C190GKT
8 |  | 1 | D3 | NZH10C-115 | DIODE ZENER 10V 500MW SOD123F | Nexperia USA Inc. | NZH10C,115
9 |  | 1 | J1 | 8x1 RECP | CONN HEADER .100 SINGL STR 8POS | Sullins Connector Solutions | S9691E-08
10 |  | 1 | J2 | USB-PD_TYPE-C | CU18 USB Type-C Receptacle Connector | CviLux Corporation | CU1816SAH1BA0R001-LF-CUS
11 |  | 1 | J3 | TERMINAL_BLOCK | TERMINAL BLOCK 5MM VERT 2POS PCB | On Shore | OSTTC020162
12 |  | 1 | Q1 | IRF9358TRPBF | MOSFET 2P-CH 30V 9.2A 8SOIC | Infineon Technologies | IRF9358TRPBF
13 |  | 1 | Q3 | BSL308PE | MOSFET 2P-CH 30V 2A 6TSOP | Infineon Technologies | BSL308PEH6327XTSA1
14 |  | 1 | Q4 | NTR4503N | MOSFET N-CH 30V 1.5A SOT-23 | ON Semiconductor | NTR4503NT1G
15 |  | 2 | R1,R8 | 1K | RES SMD 1K OHM 5% 1/10W 0603 | Yageo | RC0603JR-071KL
16 |  | 3 | R3,R6,R13 | 5K | RES SMD 5K OHM 5% 1/10W 0603 | Yageo | RC0603FR-074K99P
17 |  | 1 | R7 | 2.4K | RES SMD 2.4K OHM 5% 1/10W 0603 | Panasonic Electronic Components | ERJ-3GEYJ242V
18 |  | 2 | R12,R14 | 10K | RES SMD 10K OHM 1% 1/10W 0603 | Panasonic Electronic Components | ERJ-3EKF1002V
19 |  | 1 | R15 | 0OHM | RES SMD 0 OHM JUMPER 1/16W 0402 | Yageo | RC0402FR-070RL
20 |  | 2 | R16,R22 | 1K | RES 1K OHM 5% 1/16W 0402 | Samsung Electro-Mechanics America, Inc | RCS1005J102CS
21 |  | 1 | R17 | 2.2K | RES SMD 2.2K OHM 5% 1/2W 0805 | Panasonic Electronic Components | ERJ-P6WJ222V
22 |  | 2 | R19,R24 | 49.9K | RES SMD 49.9K OHM 1% 1/10W 0402 | Panasonic Electronic Components | ERJ-2RKF4992X
23 |  | 1 | R20 | 100K | RES SMD 100K OHM 5% 1/2W 0805 | Panasonic Electronic Components | ERJ-P6WJ104V
24 |  | 1 | R21 | 10K | RES SMD 10K OHM 5% 1/16W 0402 | Yageo | RC0402JR-0710KL
25 |  | 4 | R25,R26,R27,R28 | 2K | RES SMD 2K OHM 5% 1/16W 0402 | Yageo | RC0402JR-072KL
26 |  | 1 | SW1 | SW_SL_SP5T | SWITCH ROTARY DIP SP5T 100MA 5V | Nidec Copal Electronics | SS-10-15SPE
27 |  | 5 | TP3,TP6,TP7,TP8,TP9 | TP | SMD TEST POINT |  | TEST PAD
28 |  | 2 | TP4,TP13 | TP | SMD TEST POINT
29 |  | 1 | TP10 | BLACK | TEST POINT PC MINI .040"D BLACK | Keystone Electronics | 5001
30 |  | 2 | TP11,TP12 | RED | TEST POINT PC MINI .040"D RED | Keystone Electronics | 5000
31 |  | 1 | U1 | CYPD3177-24LQXQ | USB Type-C Port Controller | Cypress Semiconductor | CYPD3177-24LQXQ
NO LOAD
32 |  | 1 | C9 | 1uF_NL | CAP CER 1UF 35V X5R 0402 | TDK Corporation | C1005X5R1V105K050BC
33 |  | 2 | R4,R5 | 10K_NL | RES SMD 10K OHM 1% 1/10W 0603 | Yageo | RC0603FR-0710KL
34 |  | 2 | R10,R11 | 5K_NL | RES SMD 5K OHM 5% 1/10W 0603 | Yageo | RC0603FR-074K99P
ACCESSORIES
35 |  | 2 | ACC8,ACC9 | BS25BL07X30RP | BUMPER HEMI .25" DIA X .08" BLK | Bumper Specialties Inc. | BS25BL07X30RP
 |  |  |  |  |  |  |  |  |  | NO LOAD
 |  |  |  |  |  |  |  |  |  | NO LOAD
 |  |  |  |  |  |  |  |  |  | NO LOAD

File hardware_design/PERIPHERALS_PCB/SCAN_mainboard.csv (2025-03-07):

Reference | Value | Datasheet | Footprint | Qty | DNP
BZ1 | Buzzer | ~ | Connector_PinHeader_2.54mm:PinHeader_1x02_P2.54mm_Vertical | 1
C1,C9,C10,C24,C25,C26,C27,C28,C29,C30,C31,C32,C35,C53,C54,C55,C63,C65 | 10u | ~ | -- mixed values -- | 18
C2,C11,C12,C15,C21,C22,C44,C45,C59 | 0.1u | ~ | -- mixed values -- | 9
C3,C43,C46,C50,C51,C52,C58 | 1u | ~ | -- mixed values -- | 7
C4 | 0.1uF | ~ |  | 1
C5,C6 | 1u | ~ | Capacitor_SMD:C_0805_2012Metric | 2 | DNP
C8,C33,C34,C36,C37 | 10u | ~ | -- mixed values -- | 5 | DNP
C13,C14 | 1nF | ~ | Capacitor_SMD:C_0402_1005Metric | 2
C16,C17 | 0.01u | ~ | Capacitor_SMD:C_0402_1005Metric | 2 | DNP
C18 | 4.7u | ~ | Capacitor_SMD:C_0603_1608Metric | 1
C19 | 47n | ~ | Capacitor_SMD:C_0402_1005Metric | 1
C20,C41 | 47nF | ~ | Capacitor_SMD:C_0402_1005Metric | 2
C23 | 0.1u | ~ | Capacitor_SMD:C_0402_1005Metric | 1 | DNP
C38,C40 | 33u | ~ | Capacitor_Tantalum_SMD:CP_EIA-7343-31_Kemet-D | 2
C39 | 33u | ~ | Capacitor_Tantalum_SMD:CP_EIA-7343-31_Kemet-D | 1 | DNP
C42 | ~ | ~ |  | 1 | DNP
C47,C48 | 390p | ~ | Capacitor_SMD:C_0603_1608Metric | 2
C49 | 3.3u | ~ | Capacitor_SMD:C_1210_3225Metric | 1
C56,C57,C60,C61 | 0.47u | ~ | Capacitor_SMD:C_0603_1608Metric | 4
C62,C64,C66 | 47u | ~ | Capacitor_SMD:C_1210_3225Metric | 3
C67 | 10p | ~ | Capacitor_SMD:C_0603_1608Metric | 1
C68 | 100n | ~ | Capacitor_SMD:C_0402_1005Metric | 1
D1,D2,D3,D4 | ESD441 |  | SCAN_footprints:X2SON2_DPL_TEX | 4
D5,D6,D7 | WS2812B | https://cdn-shop.adafruit.com/datasheets/WS2812B.pdf | LED_SMD:LED_WS2812B_PLCC4_5.0x5.0mm_P3.2mm | 3
D8,D14 | 1N4148W | https://www.vishay.com/docs/85748/1n4148w.pdf | Diode_SMD:D_SOD-123 | 2
D11,D12 | 12V | ~ | Diode_SMD:D_SOD-523 | 2
D13 | LED | ~ | LED_SMD:LED_0805_2012Metric | 1
D15 | NZH10C-115 | https://assets.nexperia.com/documents/data-sheet/NZH_SER.pdf | SCAN_footprints:SODFL3516X120N | 1
D16 | RED | ~ | LED_SMD:LED_0603_1608Metric | 1
J1 | USB_C_16P_Connector | https://www.usb.org/sites/default/files/documents/usb_type-c.zip | SCAN_footprints:USB4110-GF-A_GCT | 1
J2 | Batt_Connector | ~ | SCAN_footprints:TE_282856-2 | 1
J3 | PV_Panel_Connector | ~ | SCAN_footprints:TE_282856-2 | 1
J4 | PIR_CONNECTOR | ~ | Connector_PinHeader_2.54mm:PinHeader_1x03_P2.54mm_Vertical | 1
J5 | Debug_Breakout | ~ |  | 1
J6 | Power_Breakout | ~ |  | 1
J7 | Conn_01x08 | ~ | Connector_PinHeader_2.54mm:PinHeader_1x08_P2.54mm_Vertical | 1
J8 | Conn_01x12 | ~ | SCAN_footprints:12-pin-0.7mm-FPC-Pad | 1
J9 | Keypad | ~ |  | 1
L1 | 1.0u | ~ | SCAN_footprints:SPM6530 | 1
L2 | 2.2u | ~ | SCAN_footprints:IND_IHLP-3232DZ_VIS | 1
Q2,Q3,Q4,Q5 | CSD17581Q3A | https://www.ti.com/lit/ds/symlink/csd17581q3a.pdf | Package_SON:VSON-8_3.3x3.3mm_P0.65mm_NexFET | 4
Q6 | CSD17575Q3 | https://www.ti.com/lit/ds/symlink/csd17577q3a.pdf | Package_SON:VSON-8_3.3x3.3mm_P0.65mm_NexFET | 1
Q7 | BC847BDW1 | http://www.onsemi.com/pub_link/Collateral/BC846BDW1T1-D.PDF | Package_TO_SOT_SMD:SOT-363_SC-70-6 | 1
Q8 | IRF9358TRPBF | https://www.diodes.com//assets/Datasheets/ds31420.pdf | SCAN_footprints:SO8_IRF9358TRPBF_INF | 1
Q9 | BSL308PE | BSL308PEH6327XTSA1 | SCAN_footprints:PG-TSOP6-6-4_INF | 1
Q10 | NTR4503NT1G |  | SCAN_footprints:SOT23_318-08_ONS | 1
R1,R2,R27 | 2.2k | ~ | -- mixed values -- | 3
R3,R4,R5,R10,R14,R17,R34,R37,R49 | 10k | ~ | -- mixed values -- | 9
R15,R16,R29,R30,R31,R67 | 0.01 | ~ | Resistor_SMD:R_2010_5025Metric | 6
R18,R19 | 100k | ~ | Resistor_SMD:R_0402_1005Metric | 2 | DNP
R20,R21,R56 | 0 | ~ | Resistor_SMD:R_0805_2012Metric | 3 | DNP
R22 | 127k | ~ | Resistor_SMD:R_0603_1608Metric | 1
R23,R57,R63,R64 | 100k | ~ | -- mixed values -- | 4
R24,R25 | 294 | ~ | Resistor_SMD:R_0603_1608Metric | 2
R26 | 6.04k | ~ | Resistor_SMD:R_0603_1608Metric | 1
R28 | 100 | ~ | Resistor_SMD:R_0603_1608Metric | 1
R32 | 5.24k | ~ | Resistor_SMD:R_0402_1005Metric | 1
R33 | 30.1k | ~ | Resistor_SMD:R_0402_1005Metric | 1
R35 | 3.3k | ~ |  | 1
R36,R38,R39,R61,R62 | 0Ω | ~ | -- mixed values -- | 5
R40,R52 | 49.9k | ~ | Resistor_SMD:R_0402_1005Metric | 2
R41,R43,R47 | DNP | ~ | Resistor_SMD:R_0603_1608Metric | 3 | DNP
R42,R44,R48,R51,R53,R58,R59 | 1k | ~ | -- mixed values -- | 7
R45,R46 | 5.1k | ~ | Resistor_SMD:R_0603_1608Metric | 2
R50 | 0 | ~ | Resistor_SMD:R_0402_1005Metric | 1
R54,R55 | 2k | ~ | Resistor_SMD:R_0402_1005Metric | 2
R60 | 0Ω | ~ | Resistor_SMD:R_0805_2012Metric | 1 | DNP
R65 | 43.2k | ~ | Resistor_SMD:R_0603_1608Metric | 1
R66 | 4.99k | ~ | Resistor_SMD:R_0603_1608Metric | 1
TH1 | Thermistor_NTC | ~ | Resistor_THT:R_Radial_Power_L11.0mm_W7.0mm_P5.00mm | 1
TP1,TP2,TP3,TP4,TP6,TP7,TP8,TP9,TP10,TP11,TP12,TP13,TP14,TP15,TP16,TP18,TP19,TP20 | TestPoint | ~ | TestPoint:TestPoint_Pad_2.0x2.0mm | 18
U1 | ESP32-C6-WROOM-1-N8 | https://www.espressif.com/sites/default/files/documentation/esp32-c6-wroom-1_wroom-1u_datasheet_en.pdf | SCAN_footprints:ESP32-C6-WROOM-1-N8 | 1
U2 | PCF8574 | http://www.nxp.com/docs/en/data-sheet/PCF8574_PCF8574A.pdf |  | 1
U4 | BQ25798RQMR | BQ25798RQMR | SCAN_footprints:IC_BQ25798RQMR | 1
U5 | TVS2200DRV | http://www.ti.com/lit/ds/symlink/tvs2200.pdf | Package_SON:WSON-6-1EP_2x2mm_P0.65mm_EP1x1.6mm | 1
U6 | CYPD3177-24LQXQ | https://au.mouser.com/datasheet/2/196/CYPR_S_A0012903526_1-3004964.pdf | SCAN_footprints:QFN50P400X400X60-25N-D | 1
U7 | ESD122 | ESD122DMYR | SCAN_footprints:DMY0003A | 1
U8 | CP2102N-A02-xQFN28 | https://www.silabs.com/documents/public/data-sheets/cp2102n-datasheet.pdf | Package_DFN_QFN:QFN-28-1EP_5x5mm_P0.5mm_EP3.35x3.35mm | 1
U9 | LM62460Q3RPHRQ1 |  | SCAN_footprints:16-VQFN-HR | 1

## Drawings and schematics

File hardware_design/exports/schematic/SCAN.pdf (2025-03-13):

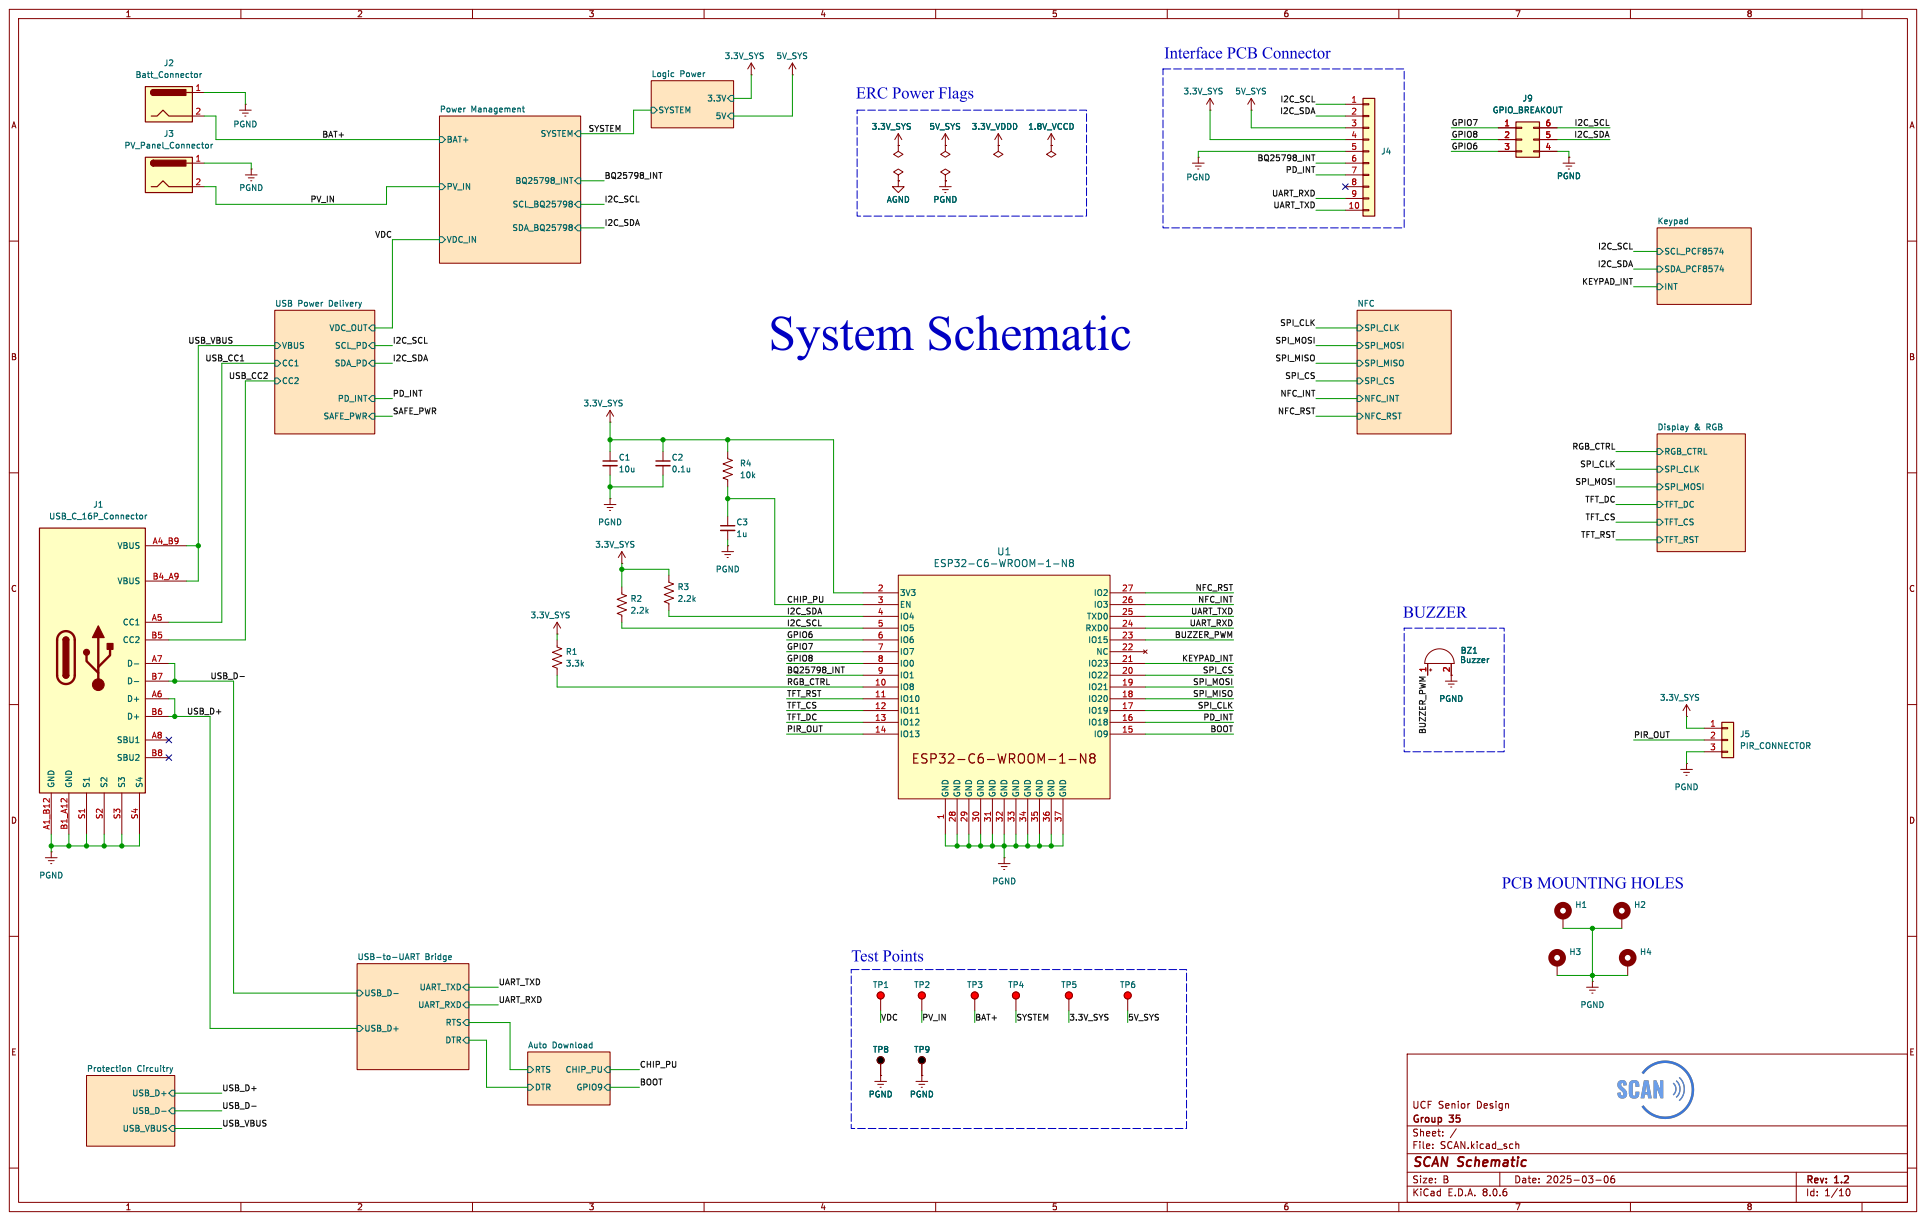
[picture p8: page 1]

SYSTEM BAT+ Power Management PD_INT CC1 CC2 VBUS

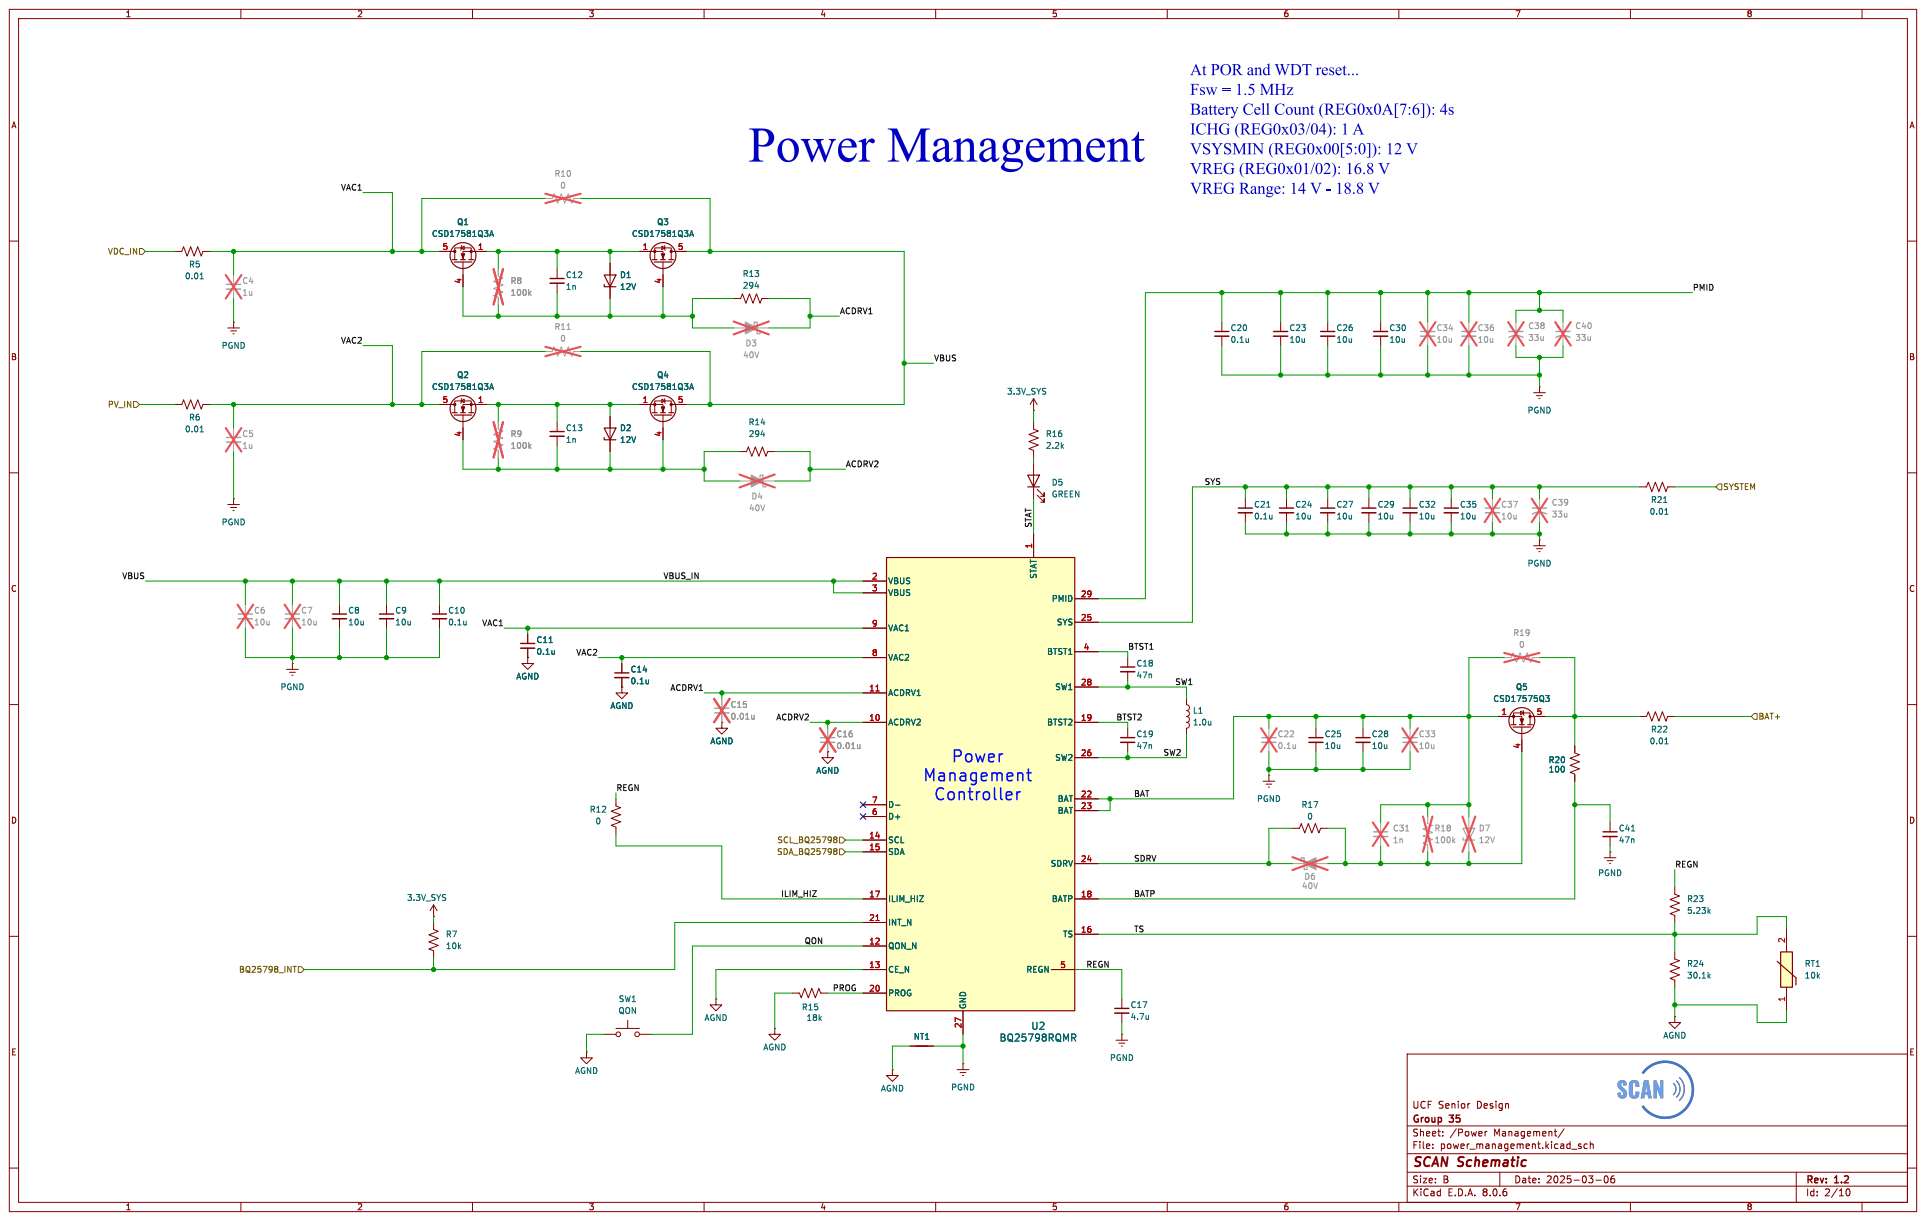
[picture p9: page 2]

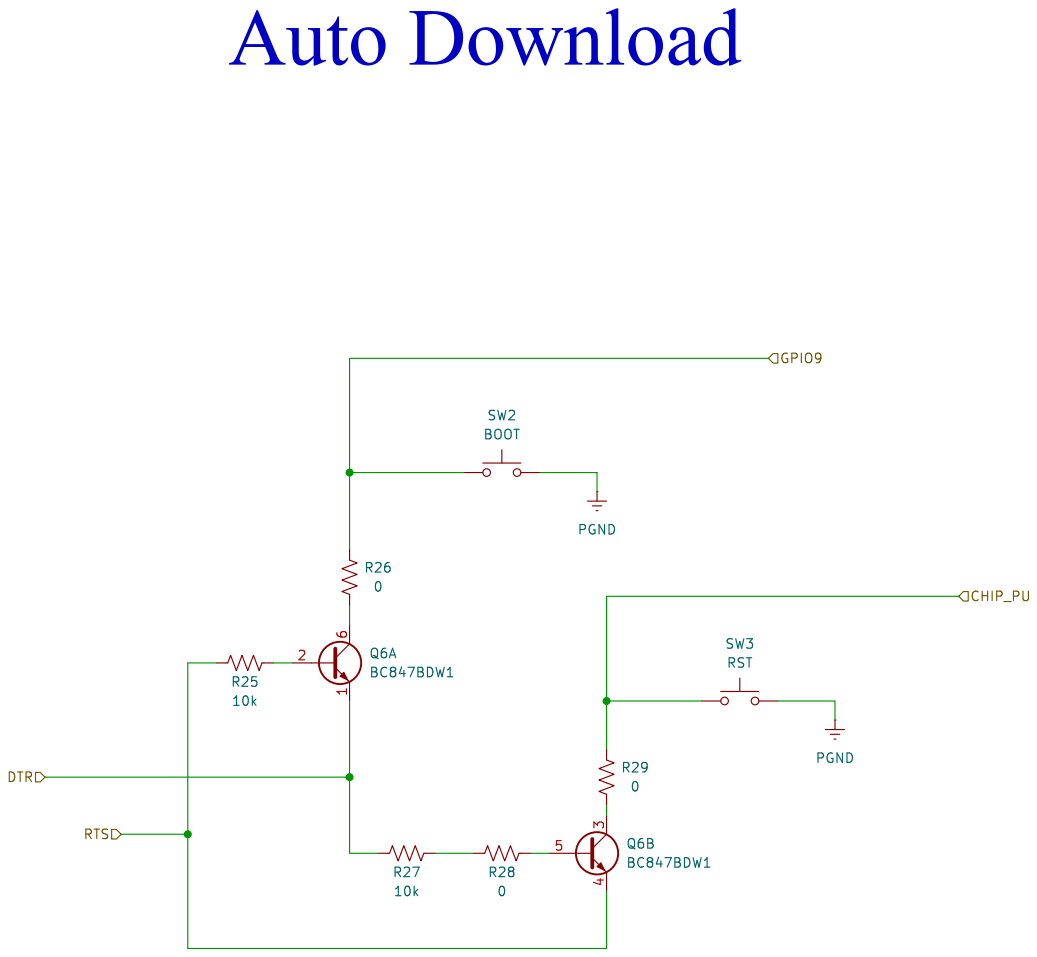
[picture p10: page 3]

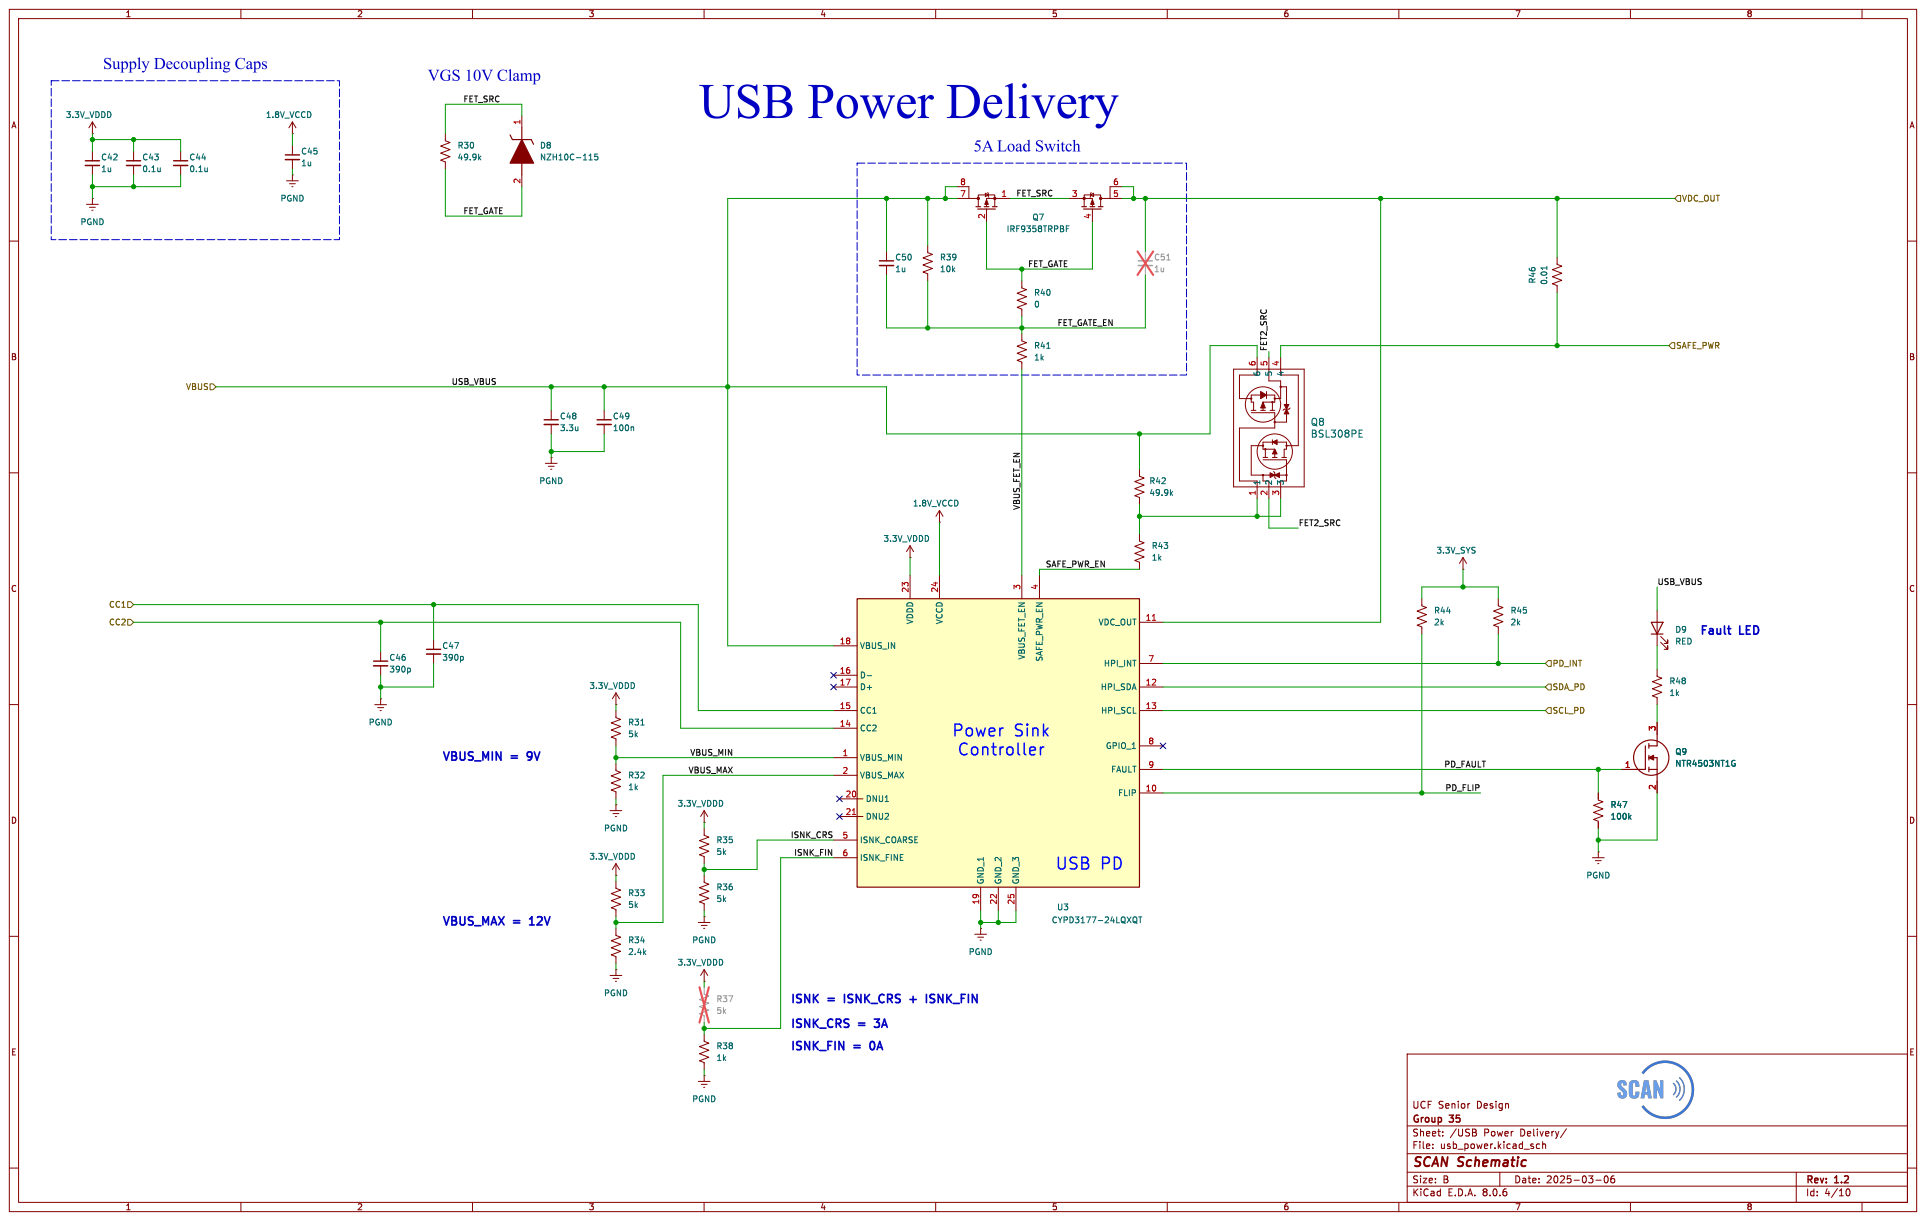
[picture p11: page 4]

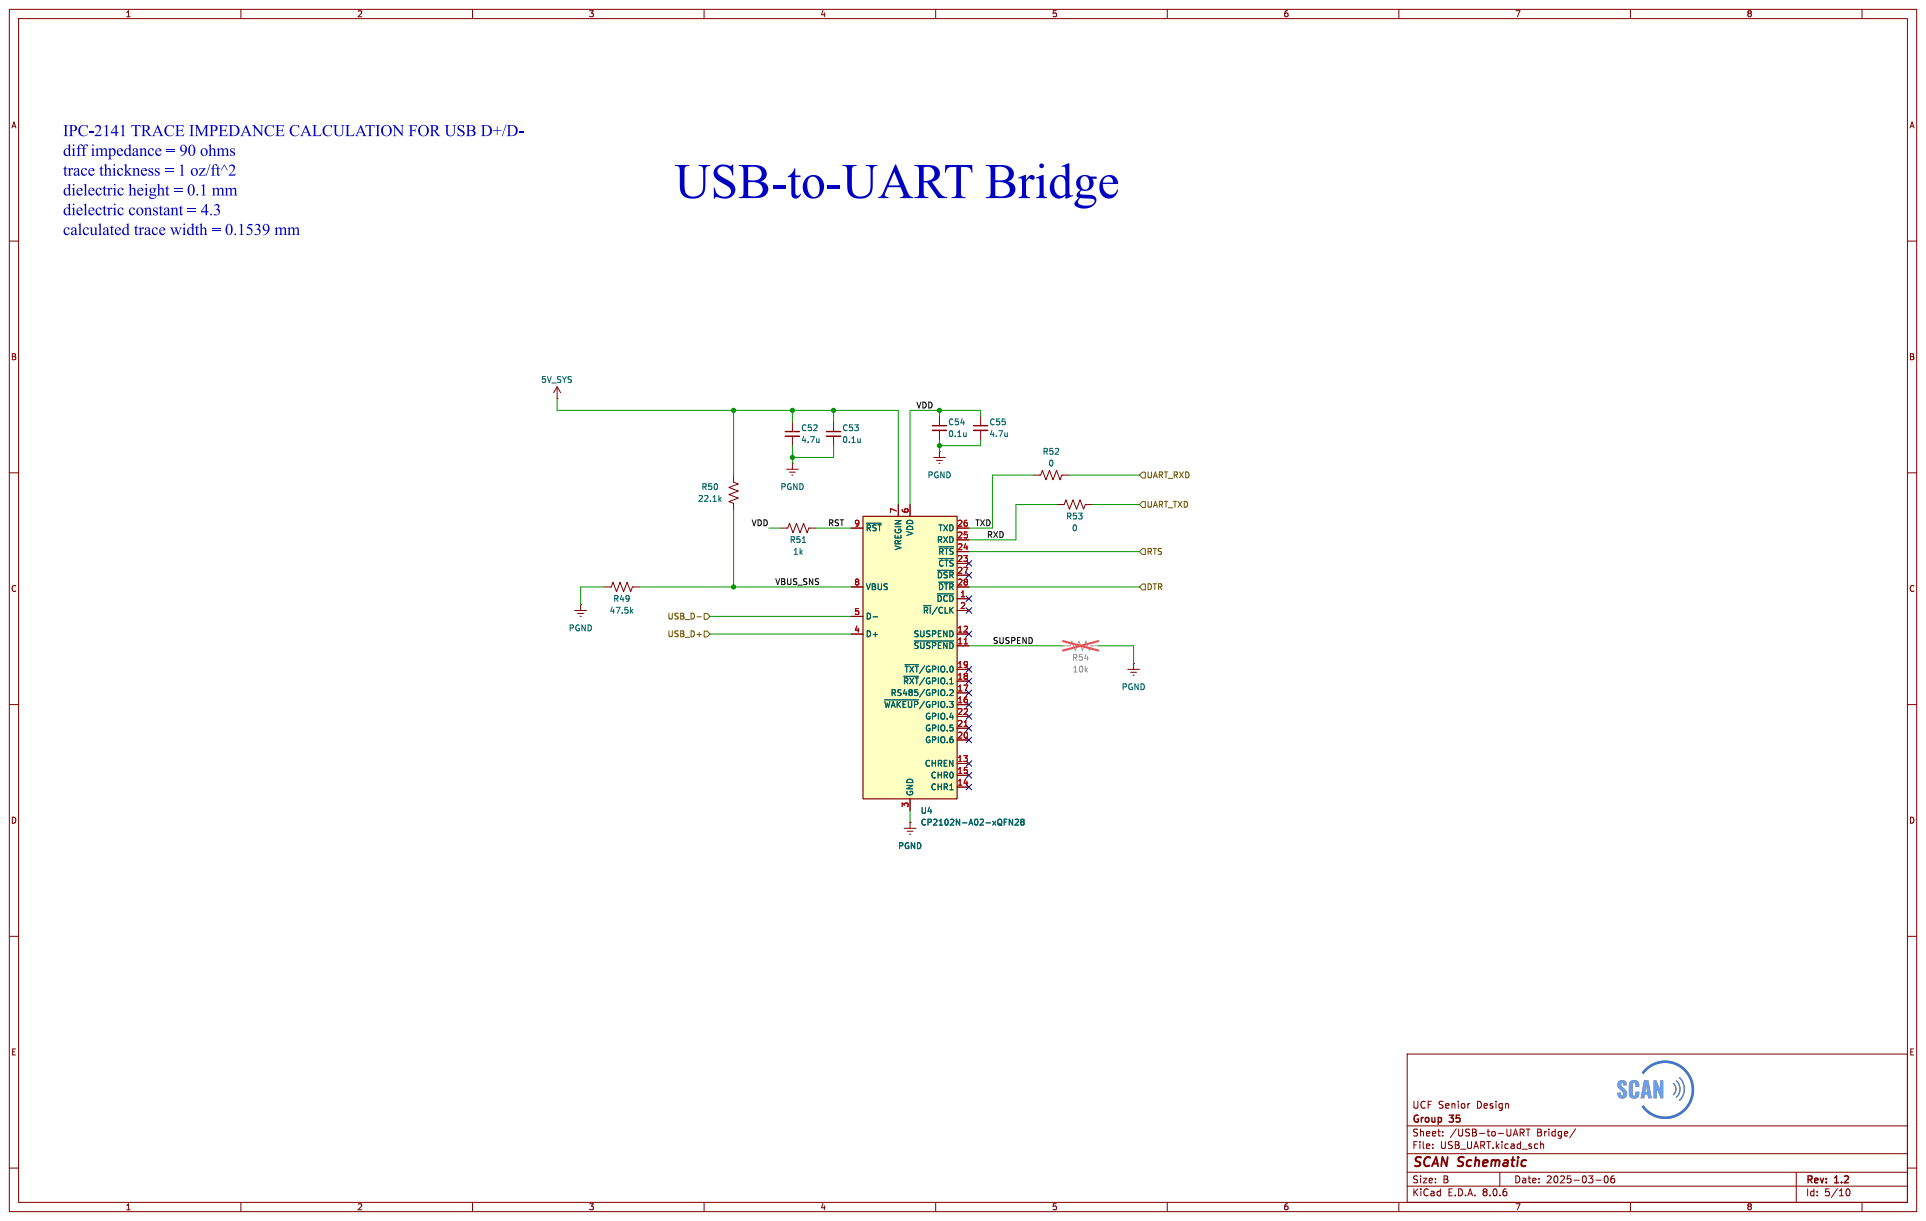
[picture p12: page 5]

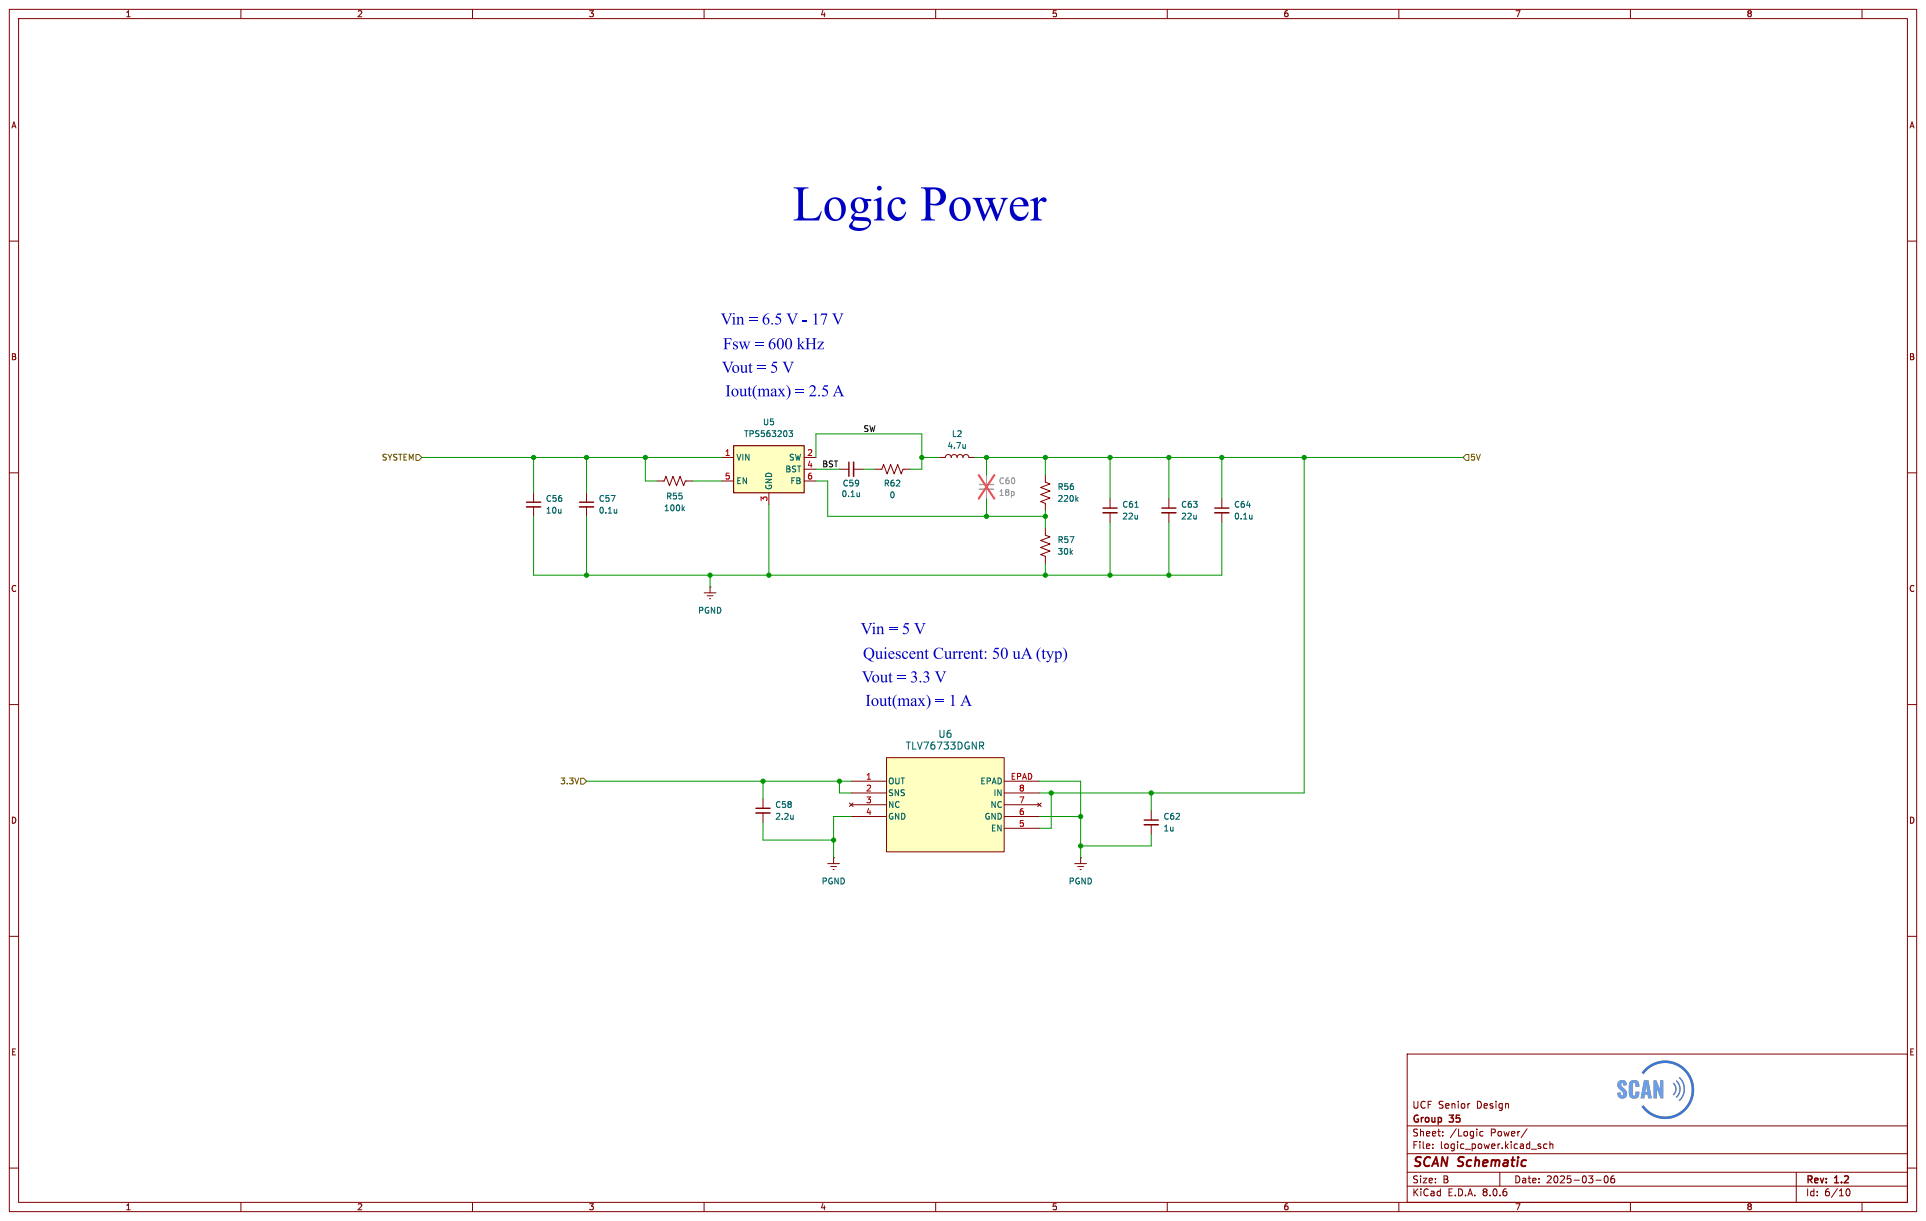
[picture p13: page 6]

3 BST 4 EN 5 FB 6 U5 TPS563203 PGND

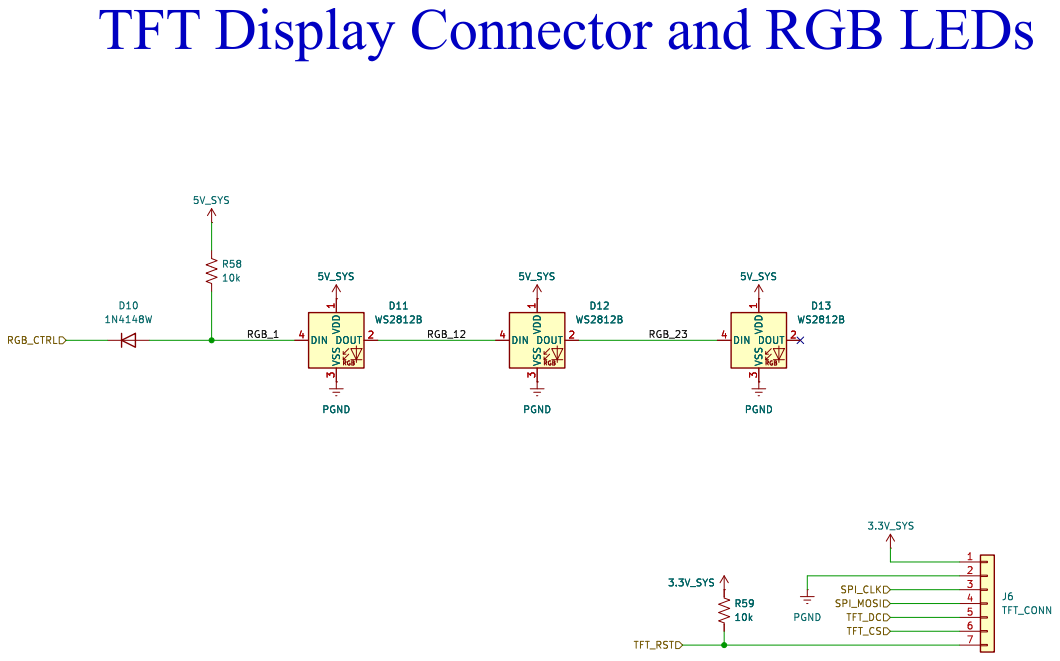
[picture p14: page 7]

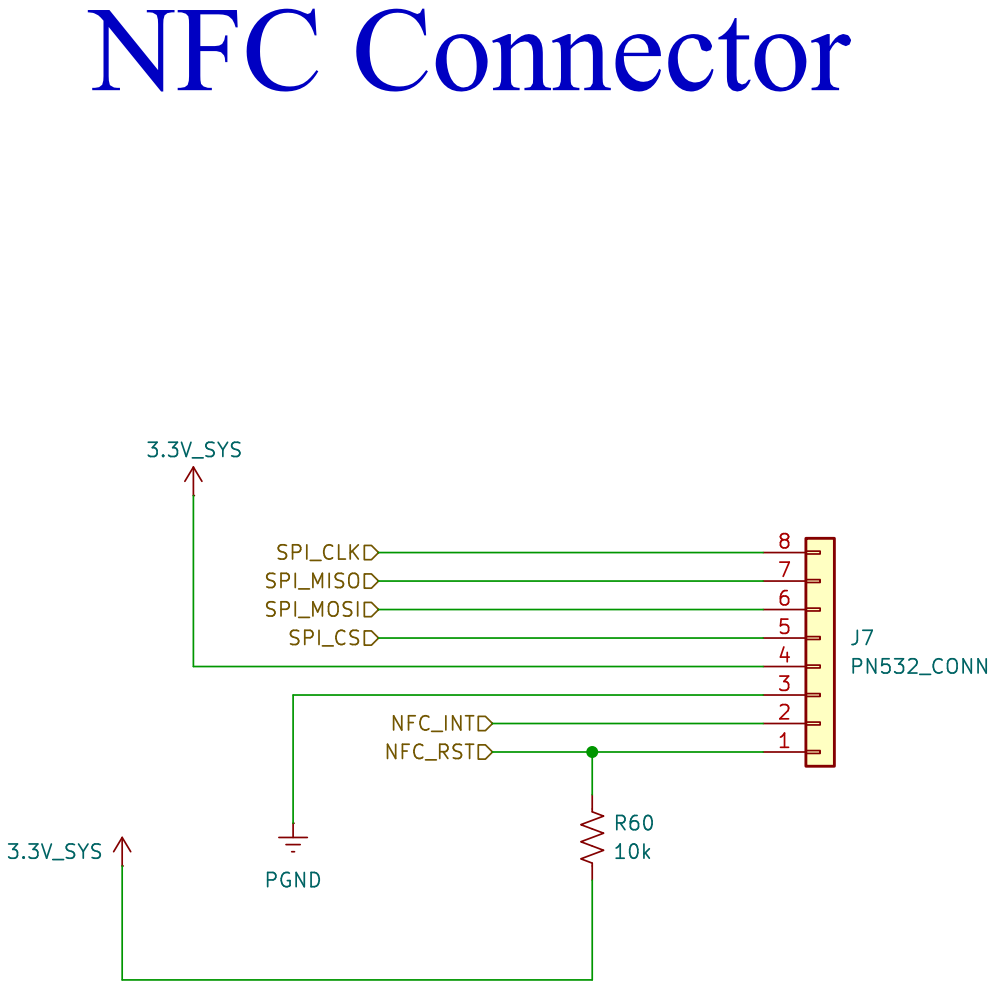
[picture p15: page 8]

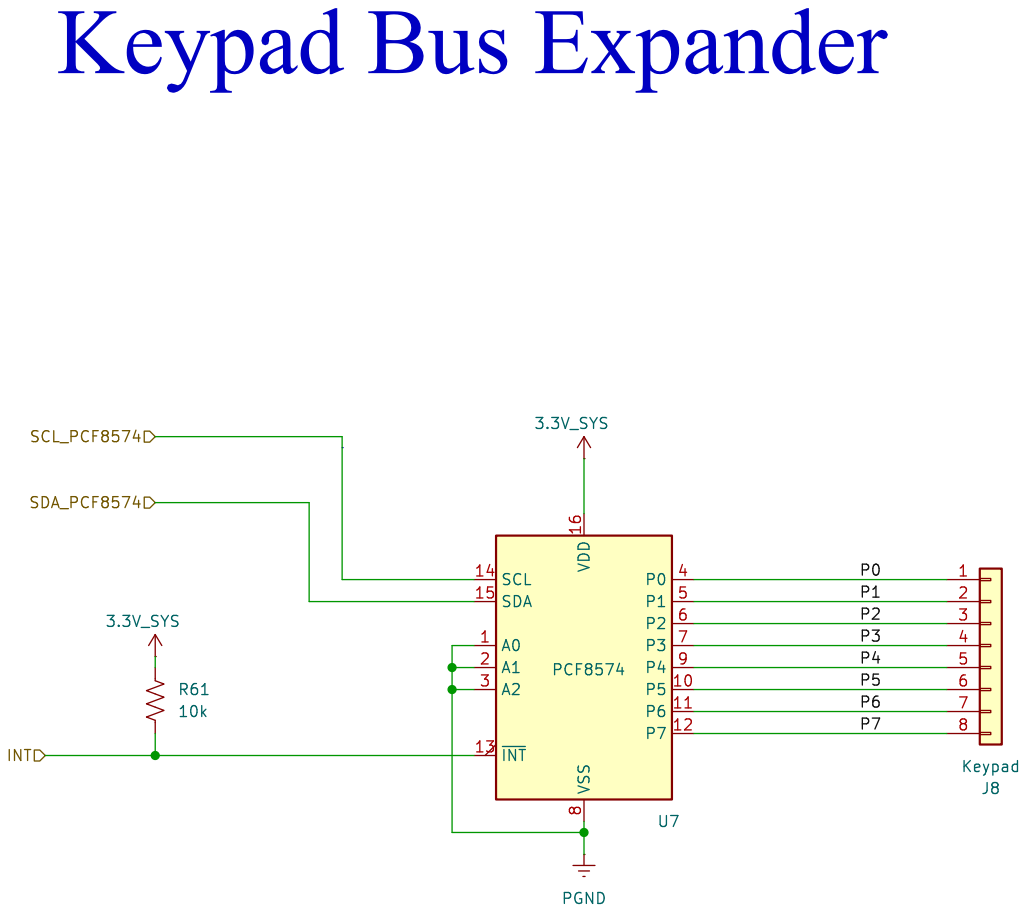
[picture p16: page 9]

File: keypad.kicad_sch Sheet: /Keypad/
Id: 9/10 SCAN Schematic

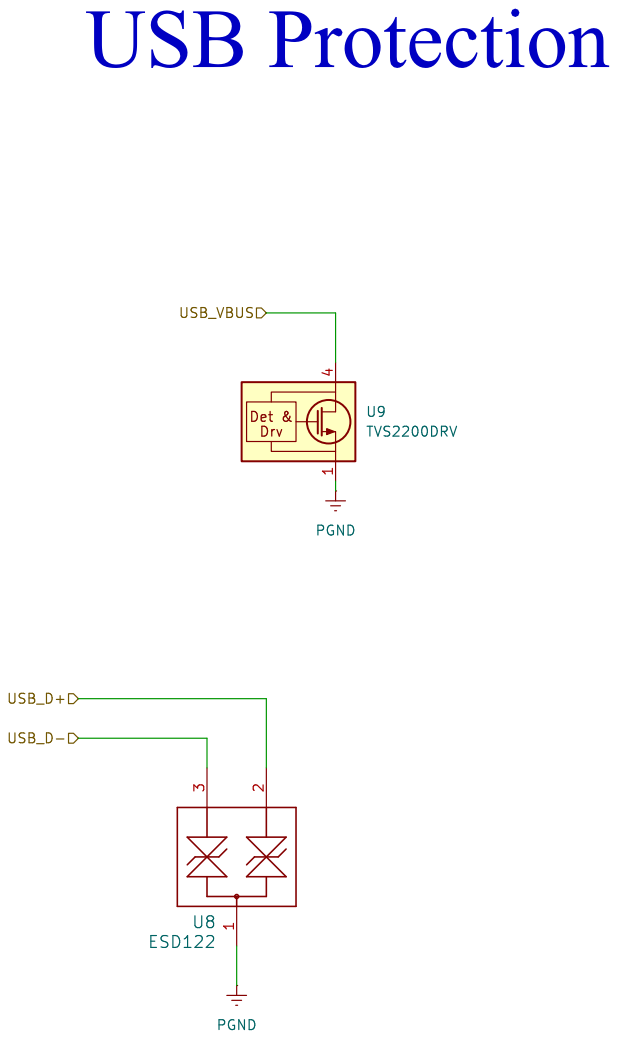
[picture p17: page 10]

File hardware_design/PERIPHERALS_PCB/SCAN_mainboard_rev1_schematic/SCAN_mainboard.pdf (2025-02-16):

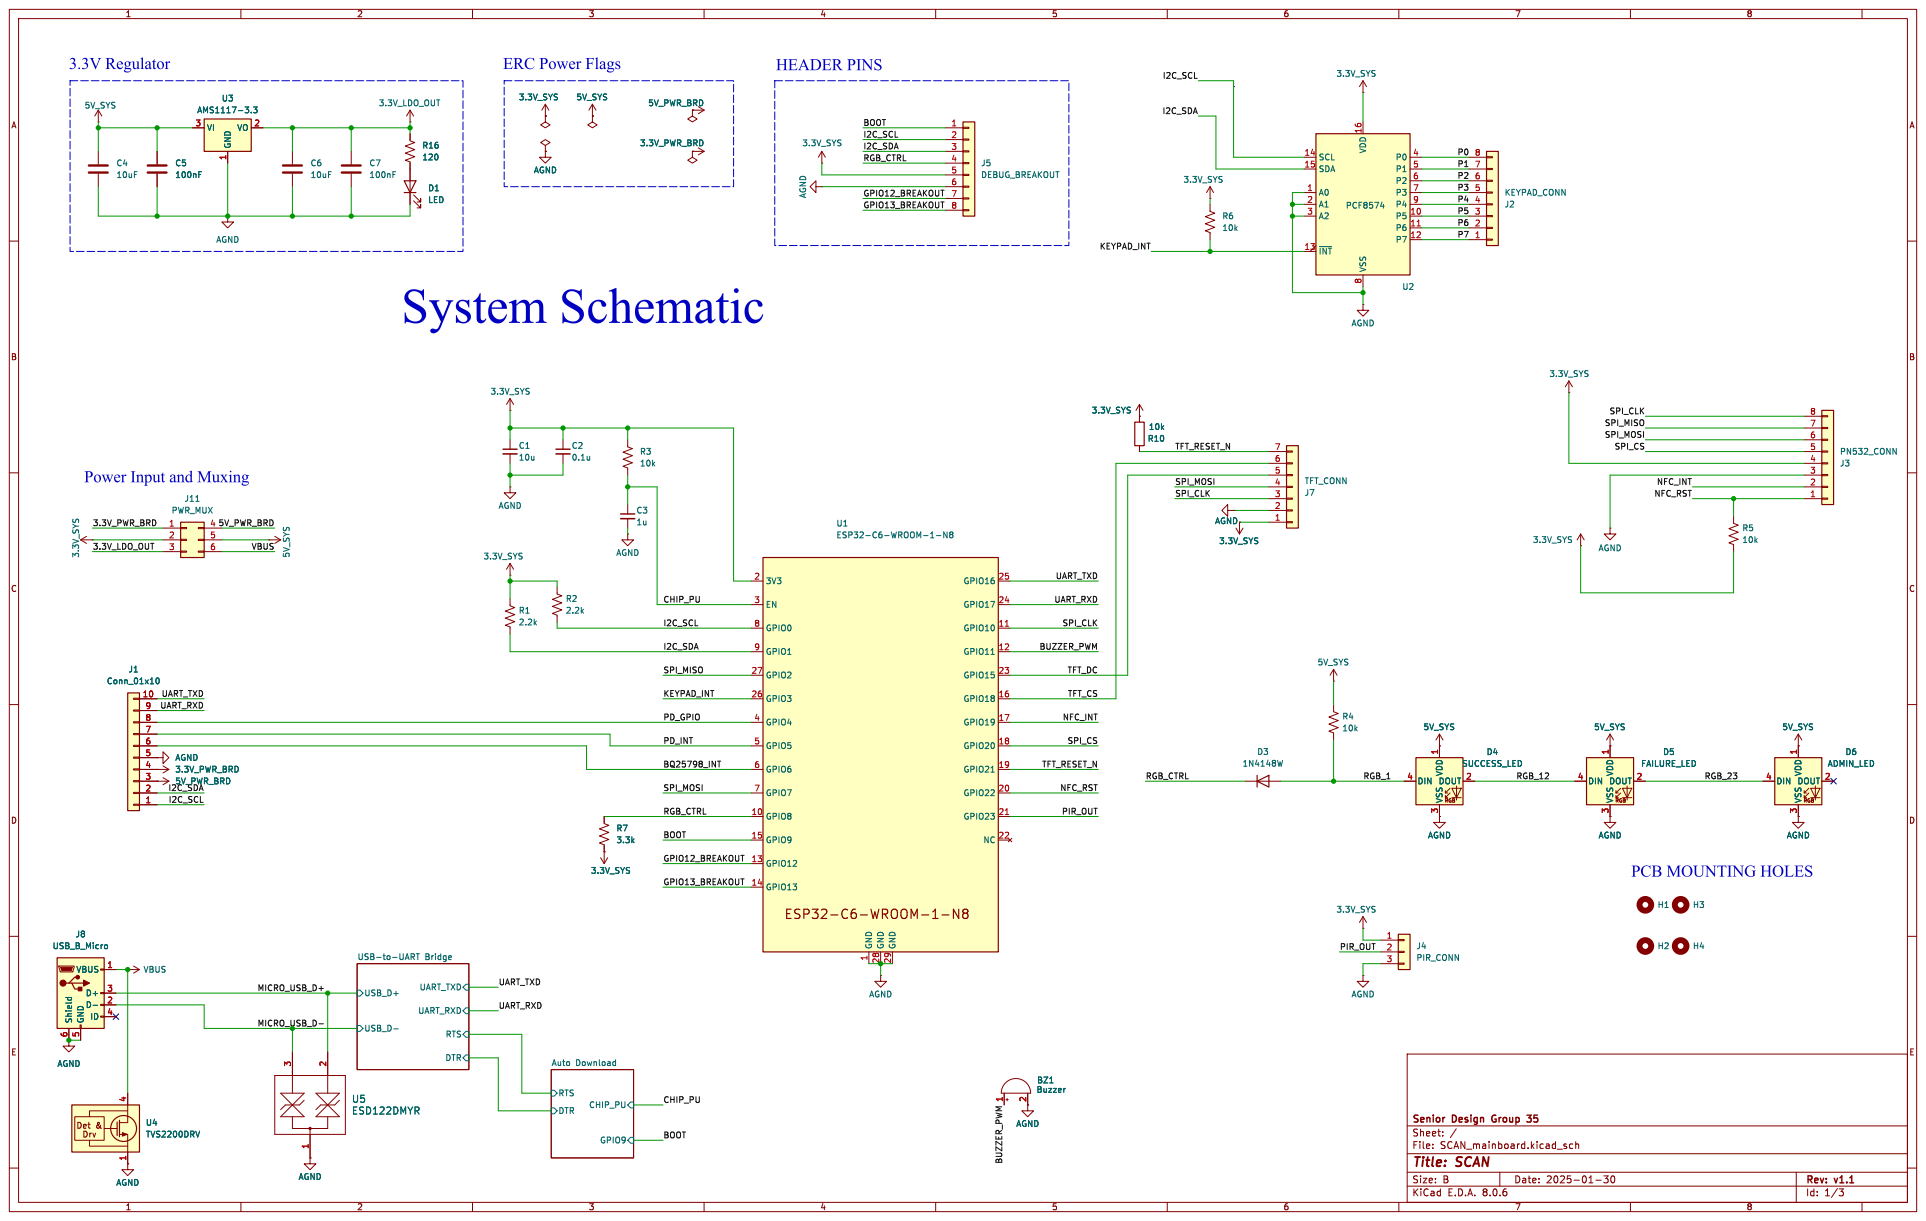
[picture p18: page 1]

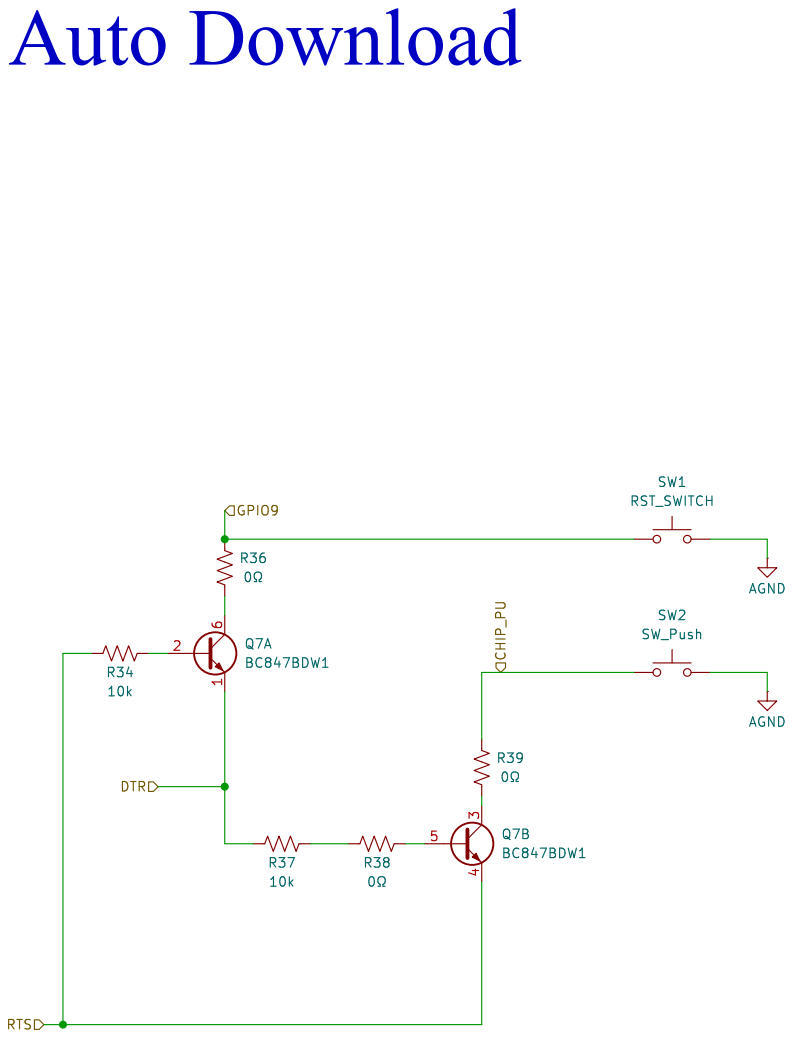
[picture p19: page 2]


SUSPEND USB-to-UARTBridge










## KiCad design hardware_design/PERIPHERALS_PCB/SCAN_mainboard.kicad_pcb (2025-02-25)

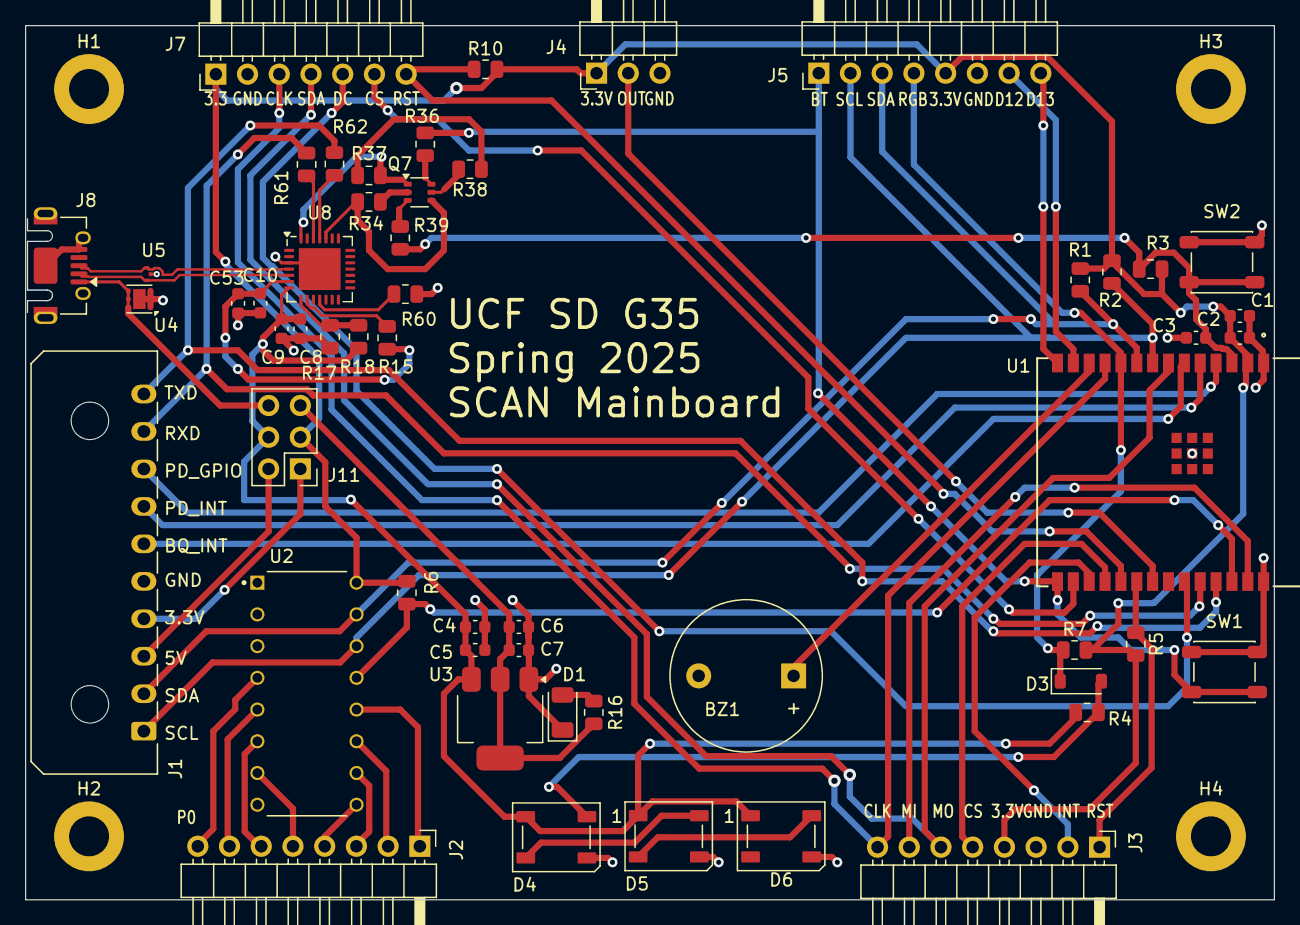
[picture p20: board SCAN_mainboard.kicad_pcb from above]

Board: 2 copper layers, 100.0 x 70.0 mm, 58 parts (0 on the bottom side), 58 nets.

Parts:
BZ1: Buzzer; Buzzer_12x9.5RM7.6
C1: 10u; C_0603_1608Metric
C2: 0.1u; C_0603_1608Metric
C3: 1u; C_0603_1608Metric
C4, C6: 10uF; C_0603_1608Metric
C5, C7: 100nF; C_0603_1608Metric
C8, C53: .1u; C_0603_1608Metric
C9, C10: 4.7u; C_0603_1608Metric
D1: LED; LED_1206_3216Metric
D3: 1N4148W; D_SOD-123
D4: SUCCESS_LED; LED_WS2812B_PLCC4_5.0x5.0mm_P3.2mm
D5: FAILURE_LED; LED_WS2812B_PLCC4_5.0x5.0mm_P3.2mm
D6: ADMIN_LED; LED_WS2812B_PLCC4_5.0x5.0mm_P3.2mm
H1, H2, H3, H4: MountingHole_Pad; MountingHole_3.2mm_M3_DIN965_Pad
J1: Conn_01x10; Molex_Micro-Fit_3.0_43650-1000_1x10_P3.00mm_Horizontal
J2: KEYPAD_CONN; PinHeader_1x08_P2.54mm_Horizontal
J3: PN532_CONN; PinHeader_1x08_P2.54mm_Horizontal
J4: PIR_CONN; PinHeader_1x03_P2.54mm_Horizontal
J5: DEBUG_BREAKOUT; PinHeader_1x08_P2.54mm_Horizontal
J7: TFT_CONN; PinHeader_1x07_P2.54mm_Horizontal
J8: USB_B_Micro; USB_Micro-AB_Molex_47590-0001
J11: PWR_MUX; PinHeader_2x03_P2.54mm_Vertical
Q7: BC847BDW1; SOT-363_SC-70-6
R1, R2: 2.2k; R_0805_2012Metric
R3, R4, R5, R6, R10, R34, R37: 10k; R_0805_2012Metric
R7: 3.3k; R_0805_2012Metric
R15: 1k; R_0805_2012Metric
R16: 120; R_0805_2012Metric
R17: 47.5k; R_0805_2012Metric
R18: 22.1k; R_0805_2012Metric
R36, R38, R39, R60, R61, R62: 0Ω; R_0805_2012Metric
SW1: RST_SWITCH; SW_SPST_PTS647_Sx38
SW2: SW_Push; SW_SPST_PTS647_Sx38
U1: ESP32-C6-WROOM-1-N8
U2: PCF8574; DIP794W45P254L1969H508Q16
U3: AMS1117-3.3; SOT-223-3_TabPin2
U4: TVS2200DRV; WSON-6-1EP_2x2mm_P0.65mm_EP1x1.6mm
U5: ESD122DMYR; DMY0003A
U8: CP2102N-A02-xQFN28; QFN-28-1EP_5x5mm_P0.5mm_EP3.35x3.35mm

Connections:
3.3V_LDO_OUT: C6.1, C7.1, J11.3, R16.1, U3.2 (VO)
3.3V_PWR_BRD: J1.4, J11.1
3.3V_SYS: C1.1, C2.1, J3.4, J4.1, J5.5, J7.1, J11.2, R1.1, R2.1, R3.1, R5.2, R6.1, R7.2, R10.2, U1.2 (3V3), U2.16 (VDD)
5V_PWR_BRD: J1.3, J11.4
5V_SYS: C4.1, C5.1, C8.1, C9.1, D4.1 (VDD), D5.1 (VDD), D6.1 (VDD), J11.5, R4.1, R18.2, U3.3 (VI), U8.7 (VREGIN)
/Auto Download/DTR: Q7.1 (E1), R37.1, U8.28 (~DTR)
/Auto Download/RTS: Q7.4 (E2), R34.1, U8.24 (~RTS)
/BOOT: J5.1, R36.2, SW1.2, U1.15 (GPIO9)
/BQ25798_INT: J1.6, U1.6 (GPIO6)
/BUZZER_PWM: BZ1.1 (+), U1.12 (GPIO11)
/CHIP_PU: C3.1, R3.2, R39.2, SW2.2, U1.3 (EN)
/GPIO12_BREAKOUT: J5.7, U1.13 (GPIO12)
/GPIO13_BREAKOUT: J5.8, U1.14 (GPIO13)
/I2C_SCL: J1.1, J5.2, R2.2, U1.8 (GPIO0), U2.14 (SCL)
/I2C_SDA: J1.2, J5.3, R1.2, U1.9 (GPIO1), U2.15 (SDA)
/KEYPAD_INT: R6.2, U1.26 (GPIO3), U2.13 (~INT)
/MICRO_USB_D+: J8.3 (D+), U5.2, U8.4 (D+)
/MICRO_USB_D-: J8.2 (D-), U5.3, U8.5 (D-)
/NFC_INT: J3.2, U1.17 (GPIO19)
/NFC_RST: J3.1, R5.1, U1.20 (GPIO22)
/P0: J2.8, U2.4 (P0)
/P1: J2.7, U2.5 (P1)
/P2: J2.6, U2.6 (P2)
/P3: J2.5, U2.7 (P3)
/P4: J2.4, U2.9 (P4)
/P5: J2.3, U2.10 (P5)
/P6: J2.2, U2.11 (P6)
/P7: J2.1, U2.12 (P7)
/PD_GPIO: J1.8, U1.4 (GPIO4)
/PD_INT: J1.7, U1.5 (GPIO5)
/PIR_OUT: J4.2, U1.21 (GPIO23)
/RGB_1: D3.2 (A), D4.4 (DIN), R4.2
/RGB_12: D4.2 (DOUT), D5.4 (DIN)
/RGB_23: D5.2 (DOUT), D6.4 (DIN)
/RGB_CTRL: D3.1 (K), J5.4, R7.1, U1.10 (GPIO8)
/SPI_CLK: J3.8, J7.3, U1.11 (GPIO10)
/SPI_CS: J3.5, U1.18 (GPIO20)
/SPI_MISO: J3.7, U1.27 (GPIO2)
/SPI_MOSI: J3.6, J7.4, U1.7 (GPIO7)
/TFT_CS: J7.6, U1.16 (GPIO18)
/TFT_DC: J7.5, U1.23 (GPIO15)
/TFT_RESET_N: J7.7, R10.1, U1.19 (GPIO21)
/UART_RXD: J1.9, R61.2, U1.24 (GPIO17)
/UART_TXD: J1.10, R62.2, U1.25 (GPIO16)
/USB-to-UART Bridge/RST: R15.2, U8.9 (~RST)
/USB-to-UART Bridge/RXD: R62.1, U8.25 (RXD)
/USB-to-UART Bridge/SUSPEND: R60.1, U8.11 (~SUSPEND)
/USB-to-UART Bridge/TXD: R61.1, U8.26 (TXD)
/USB-to-UART Bridge/VBUS_SNS: R17.2, R18.1, U8.8 (VBUS)
/USB-to-UART Bridge/VDD: C10.1, C53.1, R15.1, U8.6 (VDD)
AGND: BZ1.2 (-), C1.2, C2.2, C3.2, C4.2, C5.2, C6.2, C7.2, C8.2, C9.2, C10.2, C53.2, D1.1 (K), D4.3 (VSS), D5.3 (VSS), D6.3 (VSS), H1.1, H2.1, H3.1, H4.1, J1.5, J3.3, J4.3, J5.6, J7.2, J8.5 (GND), J8.6 (Shield), R17.1, R60.2, SW1.1, SW2.1, U1.1 (GND), U1.28 (GND), U1.29 (GND), U2.1 (A0), U2.2 (A1), U2.3 (A2), U2.8 (VSS), U3.1 (GND), U4.1 (GND), U4.2 (GND), U4.3 (GND), U4.7 (GND), U5.1, U8.3 (GND), U8.29 (GND)
unnamed: D1.2 (A), R16.2
unnamed: Q7.2 (B1), R34.2
unnamed: Q7.6 (C1), R36.1
unnamed: Q7.5 (B2), R38.2
unnamed: Q7.3 (C2), R39.1
unnamed: R37.2, R38.1
VBUS: J8.1 (VBUS), J11.6, U4.4 (IN), U4.5 (IN), U4.6 (IN)

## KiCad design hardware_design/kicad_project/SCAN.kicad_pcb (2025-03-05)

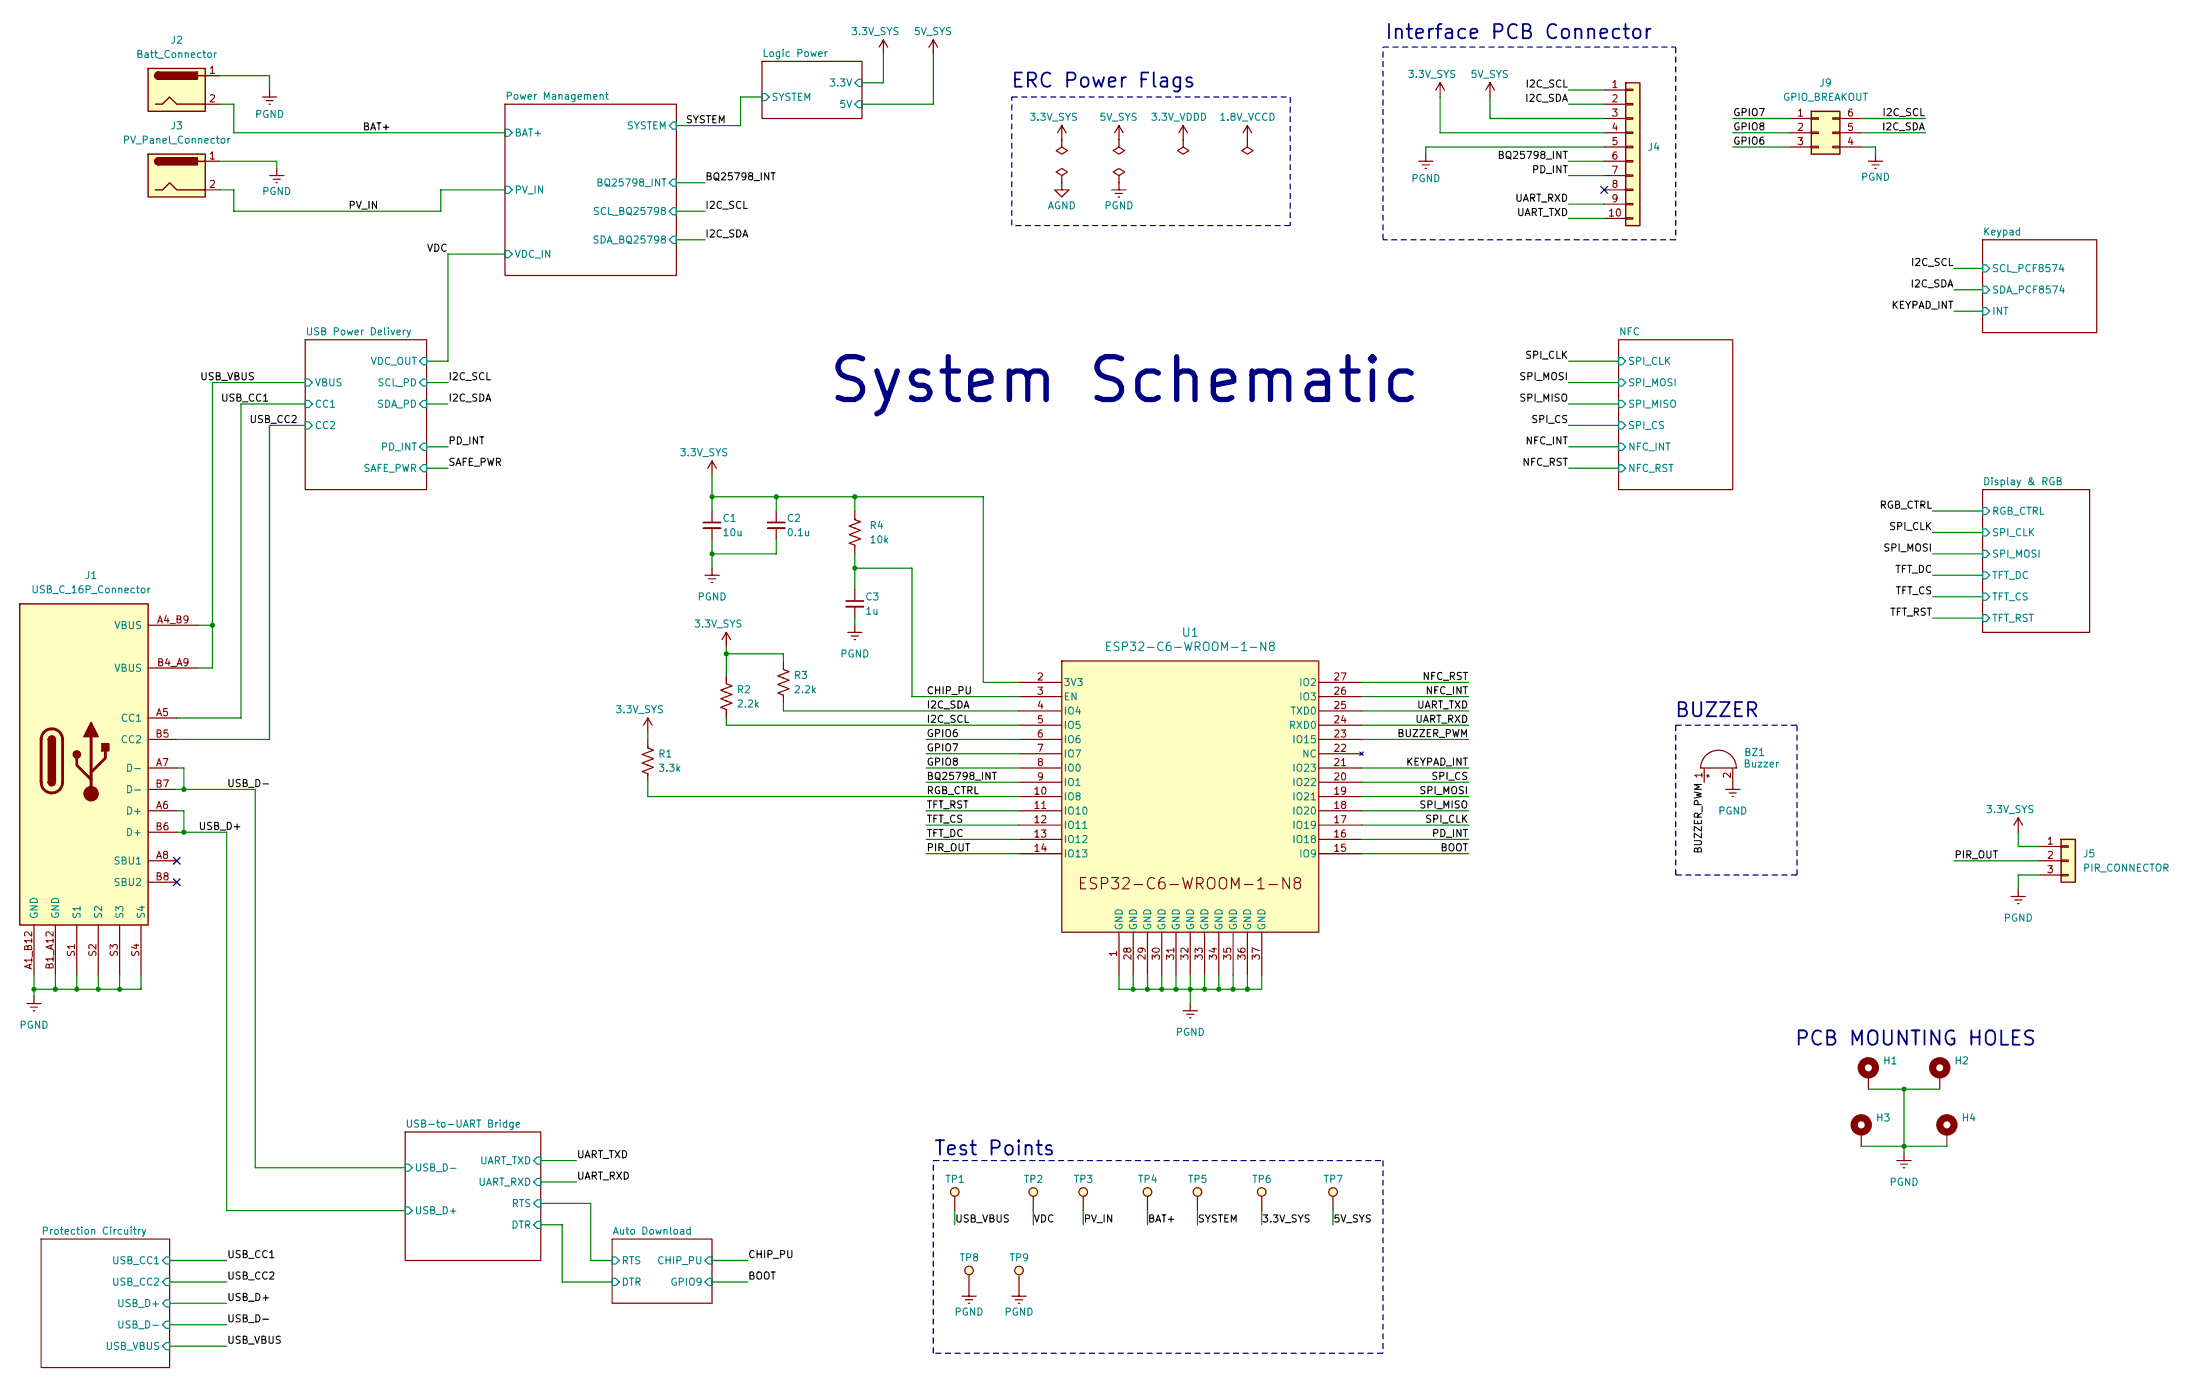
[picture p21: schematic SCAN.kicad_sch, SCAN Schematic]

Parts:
BZ1: Buzzer; Buzzer_12x9.5RM7.6
C1: 10u; C_0805_2012Metric; MFR_PN GRM21BZ71E106KE15L; JLCPCB Part Number C237493
C2: 0.1u; C_0402_1005Metric; MFR_PN CC0402KRX7R9BB104; JLCPCB Part Number C131394
C3: 1u; C_0402_1005Metric; MFR_PN GRM155R61E105KA12D; JLCPCB Part Number C77009
H1, H2, H3, H4: MountingHole_Pad; MountingHole_3.2mm_M3_ISO7380_Pad
J1: USB_C_16P_Connector; HRO_TYPE-C-31-M-12; MFR_PN TYPE-C-31-M-12; JLCPCB Part Number C165948
J2: Batt_Connector; TE_282856-2; MFR_PN WJ128V-5.0-2P; JLCPCB Part Number C8269
J3: PV_Panel_Connector; TE_282856-2; MFR_PN WJ128V-5.0-2P; JLCPCB Part Number C8269
J4: Conn_01x10; CONN_SD-43650-001_10_MOL; MFR_PN 0436501000; DigiKey Part Number 23-0436501000-ND
J5: PIR_CONNECTOR; PinHeader_1x03_P2.54mm_Horizontal; MFR_PN A2541WR-3P; JLCPCB Part Number C225489
J9: GPIO_BREAKOUT; PinHeader_2x03_P2.54mm_Horizontal
R1: 3.3k; R_0603_1608Metric; MFR_PN RC0603FR-073K3L; JLCPCB Part Number C108078
R2, R3: 2.2k; R_0805_2012Metric; MFR_PN RC0805FR-072K2L; JLCPCB Part Number C114561
R4: 10k; R_0402_1005Metric; MFR_PN RC0402FR-7W10KL; JLCPCB Part Number C851848
TP1, TP2, TP3, TP4, TP5, TP6, TP7: RED; TP_5010; MFR_PN 5010; JLCPCB Part Number C2906765
TP8, TP9: BLACK; TP_5011; MFR_PN 5011; JLCPCB Part Number C238127
U1: ESP32-C6-WROOM-1-N8; MFR_PN ESP32-C6-WROOM-1-N8; JLCPCB Part Number C5366877

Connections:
3.3V_SYS: C1.1, C2.1, J4.4, J5.1, R1.1, R2.1, R3.1, R4.1, TP6.1, U1.2 (3V3); also elsewhere on the board
5V_SYS: J4.3, TP7.1; also elsewhere on the board
/BAT+: J2.2, TP4.1; also elsewhere on the board
/BOOT: U1.15 (IO9); also elsewhere on the board
/BQ25798_INT: J4.6, U1.9 (IO1); also elsewhere on the board
/BUZZER_PWM: BZ1.1 (-), U1.23 (IO15)
/CHIP_PU: C3.1, R4.2, U1.3 (EN); also elsewhere on the board
/GPIO6: J9.3, U1.6 (IO6)
/GPIO7: J9.1, U1.7 (IO7)
/GPIO8: J9.2, U1.8 (IO0)
/I2C_SCL: J4.1, J9.6, R2.2, U1.5 (IO5); also elsewhere on the board
/I2C_SDA: J4.2, J9.5, R3.2, U1.4 (IO4); also elsewhere on the board
/KEYPAD_INT: U1.21 (IO23); also elsewhere on the board
/NFC_INT: U1.26 (IO3); also elsewhere on the board
/NFC_RST: U1.27 (IO2); also elsewhere on the board
/PD_INT: J4.7, U1.16 (IO18); also elsewhere on the board
/PIR_OUT: J5.2, U1.14 (IO13)
/PV_IN: J3.2, TP3.1; also elsewhere on the board
/RGB_CTRL: R1.2, U1.10 (IO8); also elsewhere on the board
/SPI_CLK: U1.17 (IO19); also elsewhere on the board
/SPI_CS: U1.20 (IO22); also elsewhere on the board
/SPI_MISO: U1.18 (IO20); also elsewhere on the board
/SPI_MOSI: U1.19 (IO21); also elsewhere on the board
/SYSTEM: TP5.1; also elsewhere on the board
/TFT_CS: U1.12 (IO11); also elsewhere on the board
/TFT_DC: U1.13 (IO12); also elsewhere on the board
/TFT_RST: U1.11 (IO10); also elsewhere on the board
/UART_RXD: J4.9, U1.24 (RXD0); also elsewhere on the board
/UART_TXD: J4.10, U1.25 (TXD0); also elsewhere on the board
/USB_CC1: J1.A5 (CC1); also elsewhere on the board
/USB_CC2: J1.B5 (CC2); also elsewhere on the board
/USB_D+: J1.A6 (D+), J1.B6 (D+); also elsewhere on the board
/USB_D-: J1.A7 (D-), J1.B7 (D-); also elsewhere on the board
/USB_VBUS: J1.A4_B9 (VBUS), J1.B4_A9 (VBUS), TP1.1; also elsewhere on the board
/VDC: TP2.1; also elsewhere on the board
PGND: BZ1.2 (+), C1.2, C2.2, C3.2, H1.1, H2.1, H3.1, H4.1, J1.A1_B12 (GND), J1.B1_A12 (GND), J1.S1, J1.S2, J1.S3, J1.S4, J2.1, J3.1, J4.5, J5.3, J9.4, TP8.1, TP9.1, U1.1 (GND), U1.28 (GND), U1.29 (GND), U1.30 (GND), U1.31 (GND), U1.32 (GND), U1.33 (GND), U1.34 (GND), U1.35 (GND), U1.36 (GND), U1.37 (GND); also elsewhere on the board

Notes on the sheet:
Interface PCB Connector
System Schematic
BUZZER
ERC Power Flags
PCB MOUNTING HOLES
Test Points

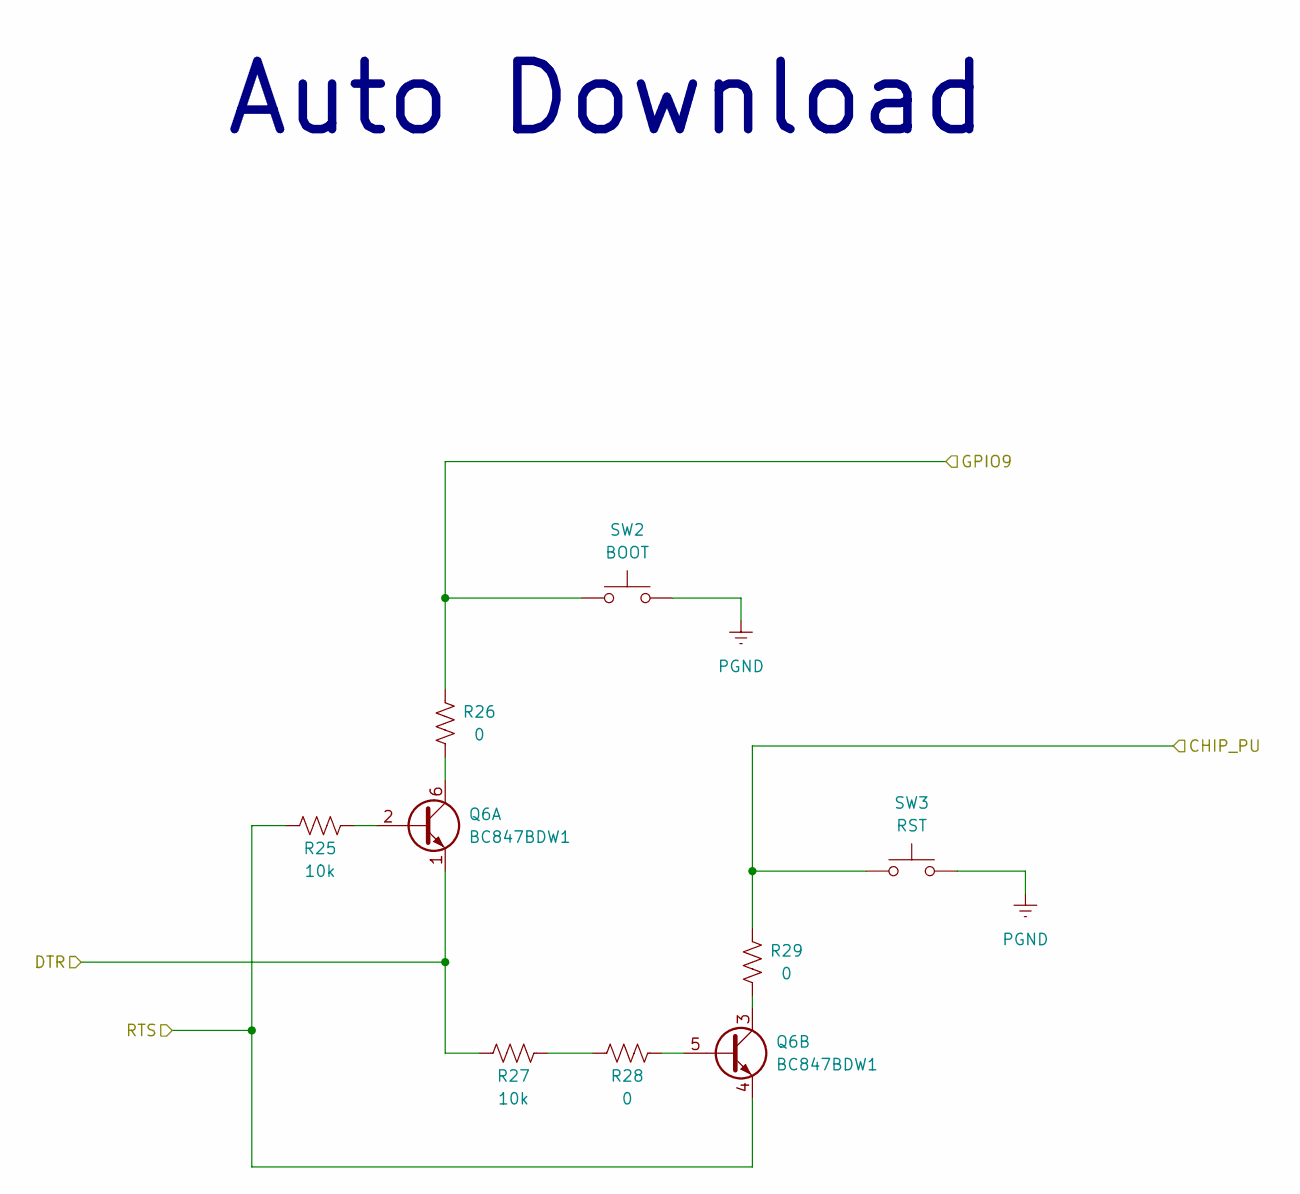
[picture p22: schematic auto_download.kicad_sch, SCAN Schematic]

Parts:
Q6: BC847BDW1; SOT-363_SC-70-6; MFR_PN BC847BDW1T1G; JLCPCB Part Number C82368
R25, R27: 10k; R_0805_2012Metric; MFR_PN CRCW080510K0FKEAC; JLCPCB Part Number C844814
R26, R28, R29: 0; R_0805_2012Metric; MFR_PN RC0805JR-070RL; JLCPCB Part Number C96345
SW2: BOOT; SW_SPST_PTS647_Sx38; MFR_PN PTS647SM38SMTR2 LFS; DigiKey Part Number PTS647SM38SMTR2LFSCT-ND
SW3: RST; SW_SPST_PTS647_Sx38; MFR_PN PTS647SM38SMTR2 LFS; DigiKey Part Number PTS647SM38SMTR2LFSCT-ND

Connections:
/Auto Download/DTR: Q6.1 (E1), R27.1; also elsewhere on the board
/Auto Download/RTS: Q6.4 (E2), R25.1; also elsewhere on the board
/BOOT: R26.2, SW2.2; also elsewhere on the board
/CHIP_PU: R29.2, SW3.2; also elsewhere on the board
unnamed: Q6.2 (B1), R25.2
unnamed: Q6.6 (C1), R26.1
unnamed: Q6.5 (B2), R28.2
unnamed: Q6.3 (C2), R29.1
unnamed: R27.2, R28.1
PGND: SW2.1, SW3.1; also elsewhere on the board

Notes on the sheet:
Auto Download

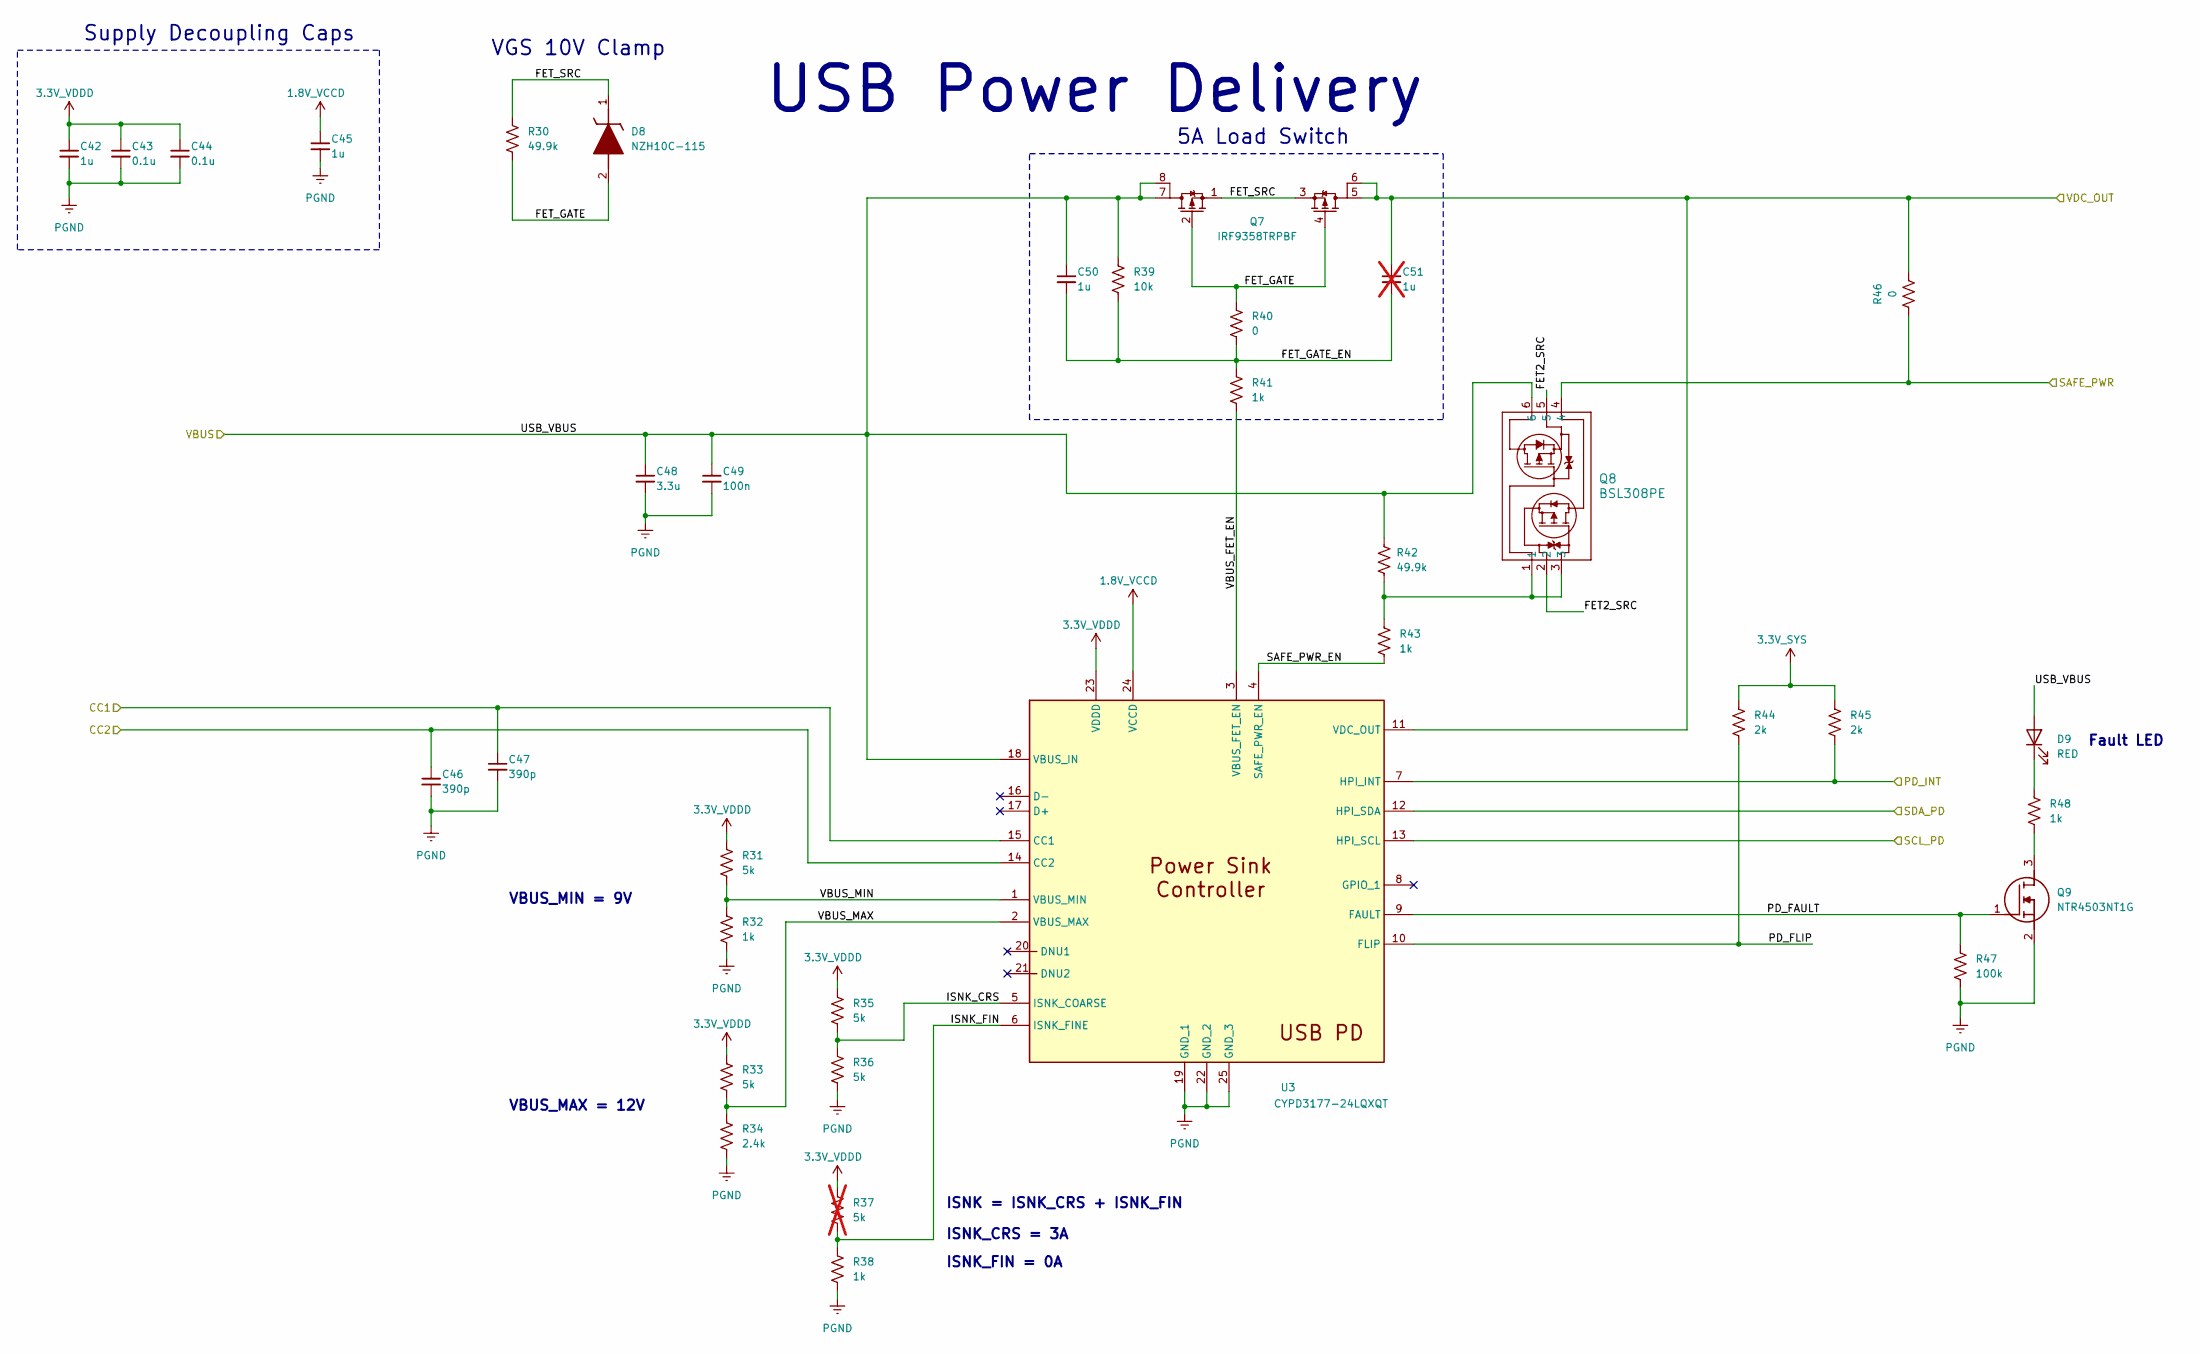
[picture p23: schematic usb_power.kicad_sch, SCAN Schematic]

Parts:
C42, C45: 1u; C_0603_1608Metric; MFR_PN GCM188R71C105KA64D; JLCPCB Part Number C161212
C43, C44: 0.1u; C_0402_1005Metric; MFR_PN GRM155R71A104KA01D; JLCPCB Part Number C71687
C46, C47: 390p; C_0603_1608Metric; MFR_PN CC0603JRX7R9BB391; JLCPCB Part Number C519518
C48: 3.3u; C_1210_3225Metric; MFR_PN GRM32DR71H335KA88L; JLCPCB Part Number C397310
C49: 100n; C_0402_1005Metric; MFR_PN GMK105BJ104KV-F; JLCPCB Part Number C187828
C50: 1u; C_0402_1005Metric; MFR_PN CL05A105KL5NRNC; JLCPCB Part Number C307413
C51: 1u; C_0402_1005Metric; MFR_PN C1005X5R1V105K050BC; DigiKey Part Number 445-9073-1-ND; not fitted
D8: NZH10C-115; SODFL3516X120N; Manufacturer_Part_Number NZH10C,115; JLCPCB Part Number C551630
D9: RED; LED_0603_1608Metric; MFR_PN LTST-C190EKT; JLCPCB Part Number C364560
Q7: IRF9358TRPBF; SO8_IRF9358TRPBF_INF; Manufacturer_Part_Number DMP3056LSD-13; JLCPCB Part Number C537847
Q8: BSL308PE; PG-TSOP6-6-4_INF; MFR_PN BSL308PEH6327XTSA1; DigiKey Part Number BSL308PEH6327XTSA1CT-ND
Q9: NTR4503NT1G; SOT23_318-08_ONS; MFR_PN NTR4503NT1G; JLCPCB Part Number C94763
R30, R42: 49.9k; R_0402_1005Metric; MFR_PN RK73H1ETTP4992F; JLCPCB Part Number C173335
R31, R33, R35, R36: 5k; R_0603_1608Metric; MFR_PN CRCW06034K99FKEA; JLCPCB Part Number C844793
R32, R38, R48: 1k; R_0603_1608Metric; MFR_PN CRCW06031K00FKEA; JLCPCB Part Number C844920
R34: 2.4k; R_0603_1608Metric; MFR_PN ERJ-3GEYJ242V; JLCPCB Part Number C403460
R37: 5k; R_0603_1608Metric; MFR_PN CRCW06034K99FKEA; JLCPCB Part Number C844793; not fitted
R39: 10k; R_0402_1005Metric; MFR_PN RC0402JR-0710KL; JLCPCB Part Number C60489
R40: 0; R_0402_1005Metric; MFR_PN RC0402FR-070RL; JLCPCB Part Number C106231
R41, R43: 1k; R_0402_1005Metric; MFR_PN RC0402JR-071KL; JLCPCB Part Number C105637
R44, R45: 2k; R_0805_2012Metric; MFR_PN RC0805JR-072KL; JLCPCB Part Number C114748
R46: 0; R_0805_2012Metric; MFR_PN PA0805JR-470RL; JLCPCB Part Number C858567
R47: 100k; R_0805_2012Metric; MFR_PN ERJ-P06F1003V; JLCPCB Part Number C441992
U3: CYPD3177-24LQXQT; QFN50P400X400X60-25N-D; Manufacturer_Part_Number CYPD3177-24LQXQ; JLCPCB Part Number C2952489

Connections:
1.8V_VCCD: C45.1, U3.24 (VCCD)
3.3V_SYS: R44.1, R45.1; also elsewhere on the board
3.3V_VDDD: C42.1, C43.1, C44.1, R31.1, R33.1, R35.1, R37.1, U3.23 (VDDD)
/I2C_SCL: U3.13 (HPI_SCL); also elsewhere on the board
/I2C_SDA: U3.12 (HPI_SDA); also elsewhere on the board
/PD_INT: R45.2, U3.7 (HPI_INT); also elsewhere on the board
/SAFE_PWR: Q8.4, R46.1
/USB Power Delivery/FET2_SRC: Q8.2, Q8.5
/USB Power Delivery/FET_GATE: D8.2 (A), Q7.2 (G1), Q7.4 (G2), R30.2, R40.1
/USB Power Delivery/FET_GATE_EN: C50.2, C51.2, R39.2, R40.2, R41.1
/USB Power Delivery/FET_SRC: D8.1 (K), Q7.1 (S1), Q7.3 (S2), R30.1
/USB Power Delivery/ISNK_CRS: R35.2, R36.1, U3.5 (ISNK_COARSE)
/USB Power Delivery/ISNK_FIN: R37.2, R38.1, U3.6 (ISNK_FINE)
/USB Power Delivery/PD_FAULT: Q9.1 (G), R47.1, U3.9 (FAULT)
/USB Power Delivery/PD_FLIP: R44.2, U3.10 (FLIP)
/USB Power Delivery/SAFE_PWR_EN: R43.2, U3.4 (SAFE_PWR_EN)
/USB Power Delivery/VBUS_FET_EN: R41.2, U3.3 (VBUS_FET_EN)
/USB Power Delivery/VBUS_MAX: R33.2, R34.1, U3.2 (VBUS_MAX)
/USB Power Delivery/VBUS_MIN: R31.2, R32.1, U3.1 (VBUS_MIN)
/USB_CC1: C47.1, U3.15 (CC1); also elsewhere on the board
/USB_CC2: C46.1, U3.14 (CC2); also elsewhere on the board
/USB_VBUS: C48.1, C49.1, C50.1, D9.2 (A), Q7.7 (D1_1), Q7.8 (D1_2), Q8.6, R39.1, R42.1, U3.18 (VBUS_IN); also elsewhere on the board
/VDC: C51.1, Q7.5 (D2_1), Q7.6 (D2_2), R46.2, U3.11 (VDC_OUT); also elsewhere on the board
unnamed: D9.1 (K), R48.1
unnamed: Q8.1, Q8.3, R42.2, R43.1
unnamed: Q9.3 (D), R48.2
PGND: C42.2, C43.2, C44.2, C45.2, C46.2, C47.2, C48.2, C49.2, Q9.2 (S), R32.2, R34.2, R36.2, R38.2, R47.2, U3.19 (GND_1), U3.22 (GND_2), U3.25 (GND_3); also elsewhere on the board

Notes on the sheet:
ISNK_CRS = 3A
VGS 10V Clamp
5A Load Switch
USB Power Delivery
Fault LED
ISNK = ISNK_CRS + ISNK_FIN
VBUS_MAX = 12V
Supply Decoupling Caps
VBUS_MIN = 9V
ISNK_FIN = 0A

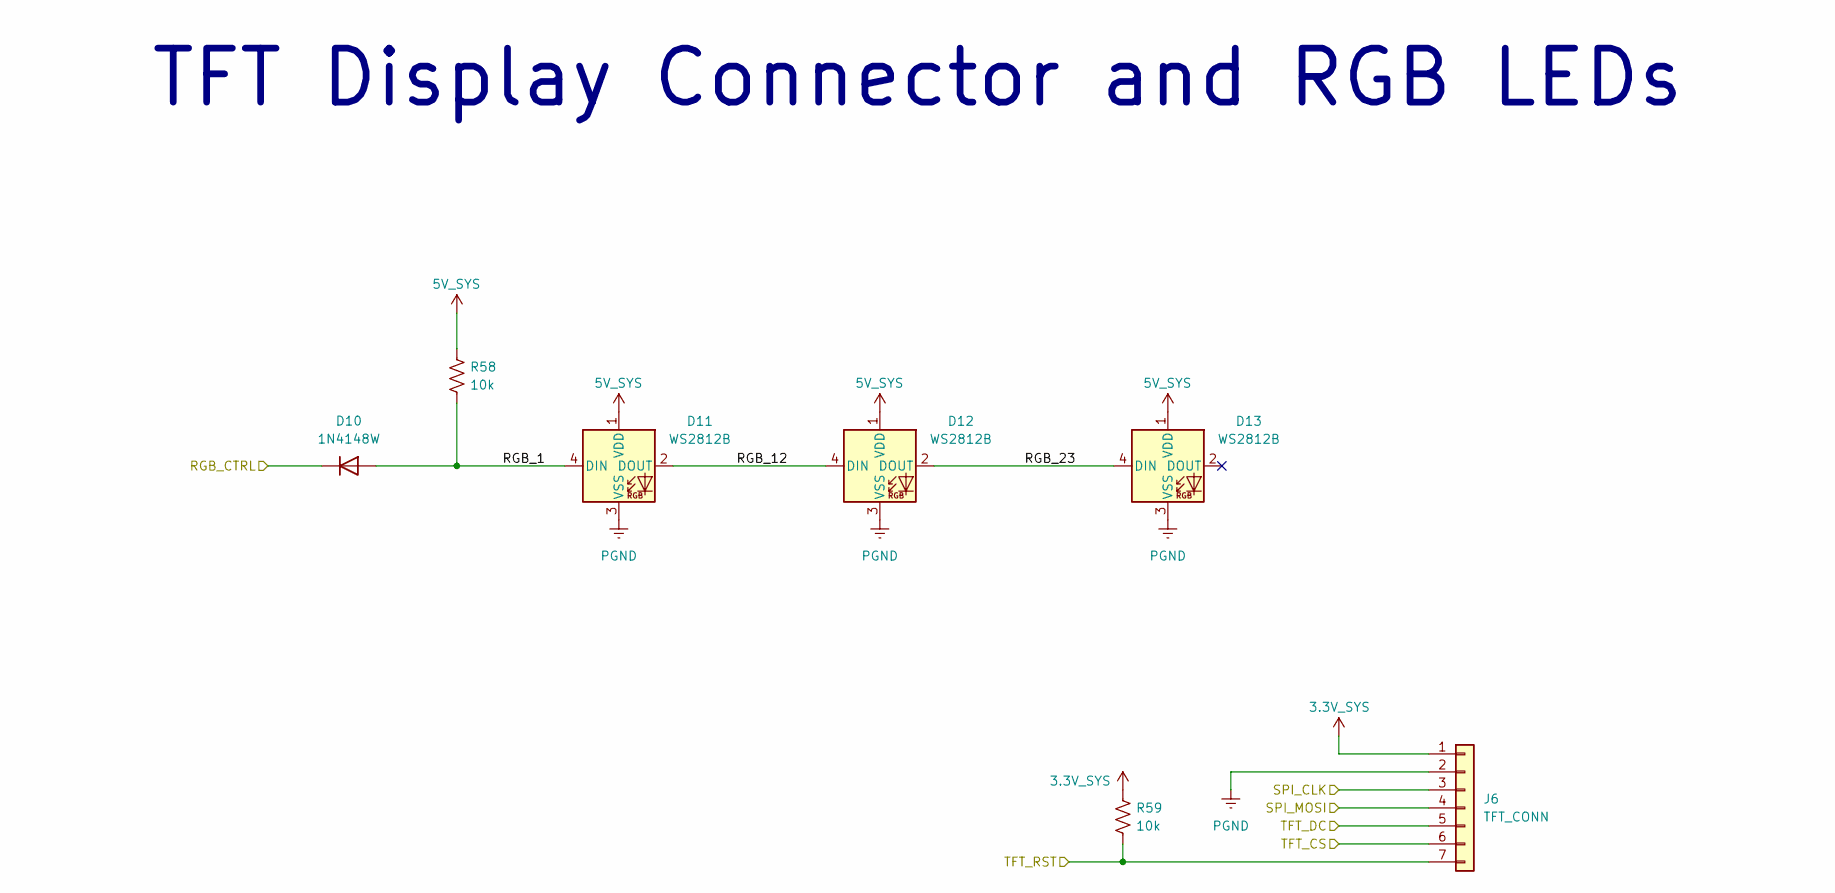
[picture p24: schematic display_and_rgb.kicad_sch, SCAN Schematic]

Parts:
D10: 1N4148W; D_SOD-123; MFR_PN 1N4448W; JLCPCB Part Number C8601
D11, D12, D13: WS2812B; LED_WS2812B_PLCC4_5.0x5.0mm_P3.2mm; MFR_PN COM-16347; JLCPCB Part Number C7433145
J6: TFT_CONN; PinHeader_1x07_P2.54mm_Horizontal
R58, R59: 10k; R_0805_2012Metric; MFR_PN CRCW080510K0FKEAC; JLCPCB Part Number C844814

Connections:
3.3V_SYS: J6.1, R59.1; also elsewhere on the board
5V_SYS: D11.1 (VDD), D12.1 (VDD), D13.1 (VDD), R58.1; also elsewhere on the board
/Display & RGB/RGB_1: D10.2 (A), D11.4 (DIN), R58.2
/Display & RGB/RGB_12: D11.2 (DOUT), D12.4 (DIN)
/Display & RGB/RGB_23: D12.2 (DOUT), D13.4 (DIN)
/RGB_CTRL: D10.1 (K); also elsewhere on the board
/SPI_CLK: J6.3; also elsewhere on the board
/SPI_MOSI: J6.4; also elsewhere on the board
/TFT_CS: J6.6; also elsewhere on the board
/TFT_DC: J6.5; also elsewhere on the board
/TFT_RST: J6.7, R59.2; also elsewhere on the board
PGND: D11.3 (VSS), D12.3 (VSS), D13.3 (VSS), J6.2; also elsewhere on the board

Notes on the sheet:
TFT Display Connector and RGB LEDs

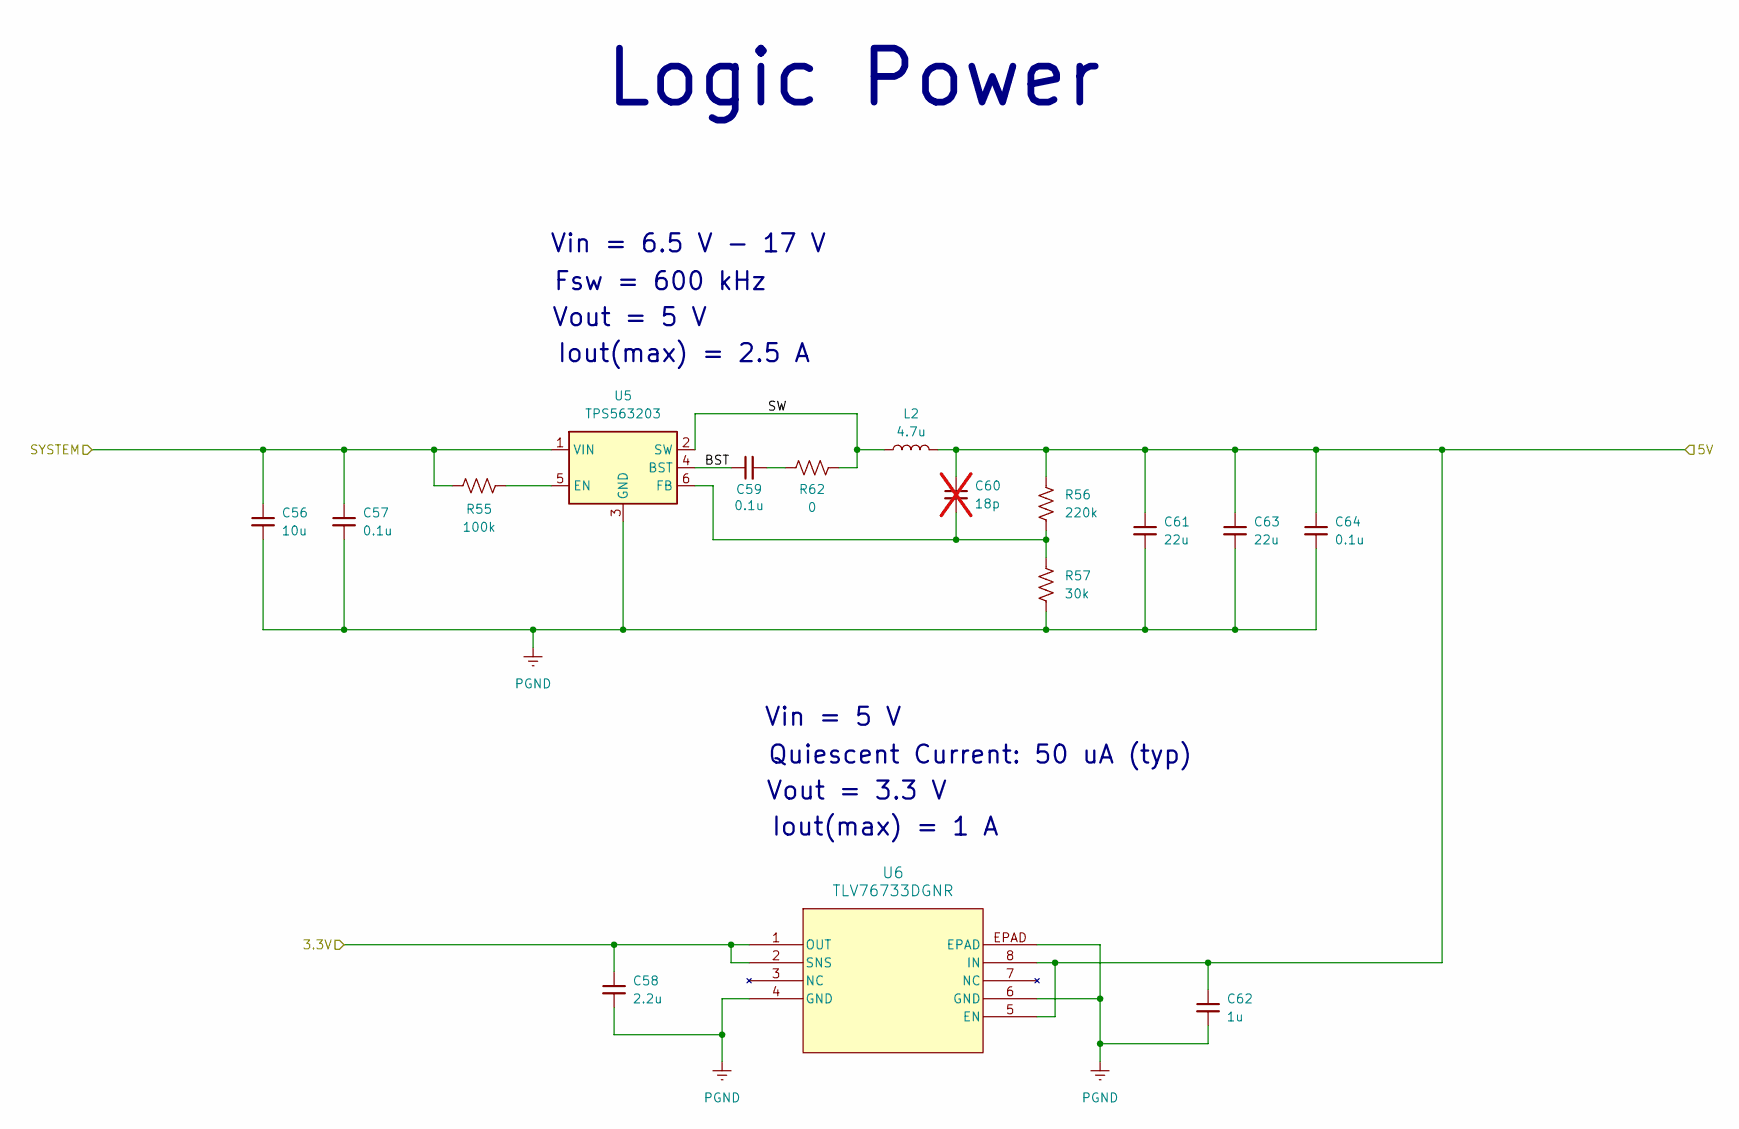
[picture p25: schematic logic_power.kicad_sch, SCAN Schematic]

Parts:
C56: 10u; C_0805_2012Metric; MFR_PN GRM21BR61E106MA73L; JLCPCB Part Number C391262
C57, C59, C64: 0.1u; C_0603_1608Metric; MFR_PN CC0603KRX7R9BB104; JLCPCB Part Number C14663
C58: 2.2u; C_0805_2012Metric; MFR_PN CC0805KKX7R9BB225; JLCPCB Part Number C125847
C60: 18p; C_0603_1608Metric; not fitted
C61, C63: 22u; C_0805_2012Metric; MFR_PN GRM21BR61A226ME44L; JLCPCB Part Number C441864
C62: 1u; C_0805_2012Metric; MFR_PN CC0805KKX7R9BB105; JLCPCB Part Number C91185
L2: 4.7u; WE-LHMI_7030_705048; MFR_PN 74437349047; JLCPCB Part Number C6404631
R55: 100k; R_0603_1608Metric; MFR_PN CRCW0603100KJNEA; JLCPCB Part Number C844723
R56: 220k; R_0603_1608Metric; MFR_PN RC0603FR-07220KL; JLCPCB Part Number C123420
R57: 30k; R_0603_1608Metric; MFR_PN RC0603FR-0730KL; JLCPCB Part Number C100001
R62: 0; R_0603_1608Metric; MFR_PN CRCW06030000Z0EA; JLCPCB Part Number C844915
U5: TPS563203; SOT-563; MFR_PN TPS563203DRLR; JLCPCB Part Number C22445512
U6: TLV76733DGNR; VSSOP8_DGN_TEX; MFR_PN TLV76733DGNR; JLCPCB Part Number C2873382

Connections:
3.3V_SYS: C58.1, U6.1 (OUT), U6.2 (SNS); also elsewhere on the board
5V_SYS: C60.1, C61.1, C62.1, C63.1, C64.1, L2.2, R56.1, U6.5 (EN), U6.8 (IN); also elsewhere on the board
/Logic Power/BST: C59.1, U5.4 (BST)
/Logic Power/SW: L2.1, R62.2, U5.2 (SW)
/SYSTEM: C56.1, C57.1, R55.1, U5.1 (VIN); also elsewhere on the board
unnamed: C59.2, R62.1
unnamed: R55.2, U5.5 (EN)
unnamed: C60.2, R56.2, R57.1, U5.6 (FB)
PGND: C56.2, C57.2, C58.2, C61.2, C62.2, C63.2, C64.2, R57.2, U5.3 (GND), U6.4 (GND), U6.6 (GND), U6.EPAD; also elsewhere on the board

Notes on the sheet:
Iout(max) = 2.5 A
Vin = 5 V
Vout = 3.3 V
Quiescent Current: 50 uA (typ)
Vin = 6.5 V - 17 V
Logic Power
Fsw = 600 kHz
Vout = 5 V
Iout(max) = 1 A

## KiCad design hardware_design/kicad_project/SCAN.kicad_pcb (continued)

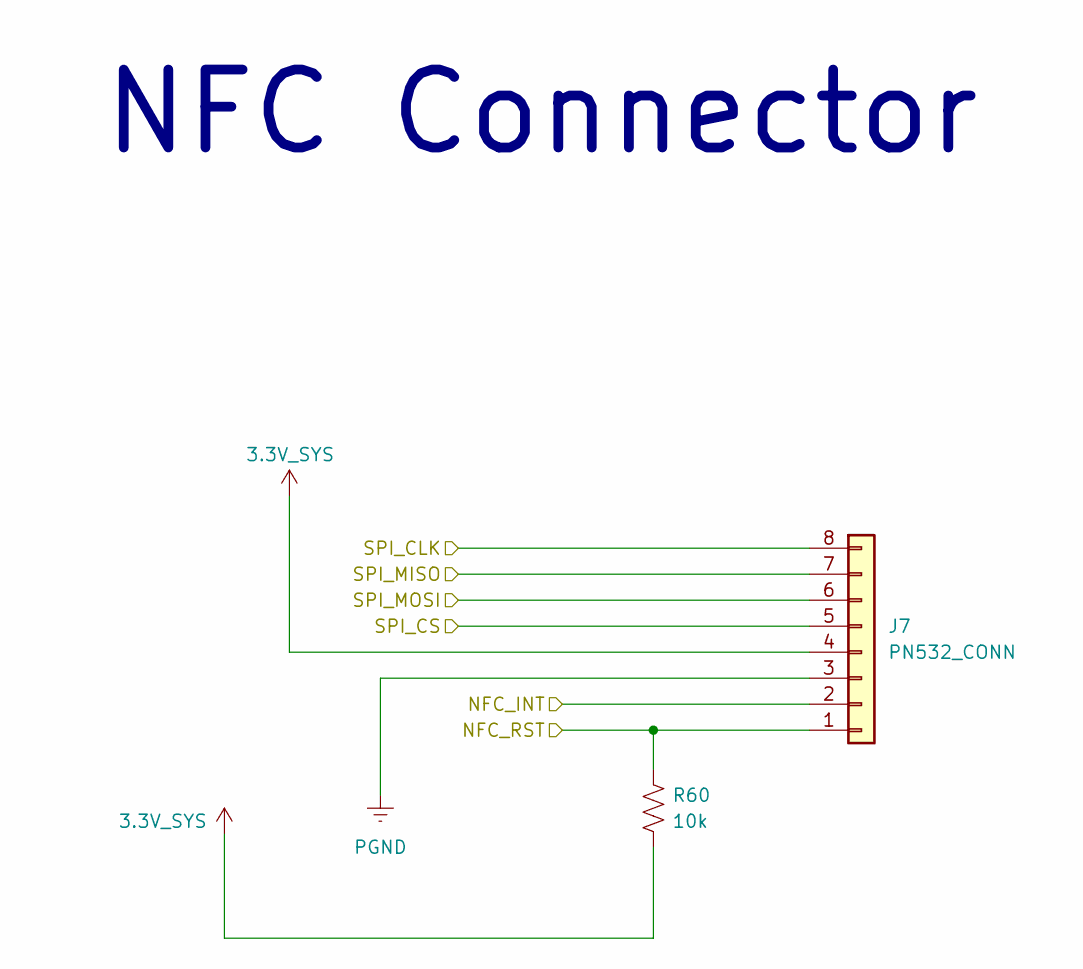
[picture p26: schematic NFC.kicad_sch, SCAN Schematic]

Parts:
J7: PN532_CONN; PinHeader_1x08_P2.54mm_Horizontal
R60: 10k; R_0805_2012Metric; MFR_PN CRCW080510K0FKEAC; JLCPCB Part Number C844814

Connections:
3.3V_SYS: J7.4 (Pin_5), R60.2; also elsewhere on the board
/NFC_INT: J7.2 (Pin_7); also elsewhere on the board
/NFC_RST: J7.1 (Pin_8), R60.1; also elsewhere on the board
/SPI_CLK: J7.8 (Pin_1); also elsewhere on the board
/SPI_CS: J7.5 (Pin_4); also elsewhere on the board
/SPI_MISO: J7.7 (Pin_2); also elsewhere on the board
/SPI_MOSI: J7.6 (Pin_3); also elsewhere on the board
PGND: J7.3 (Pin_6); also elsewhere on the board

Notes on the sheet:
NFC Connector

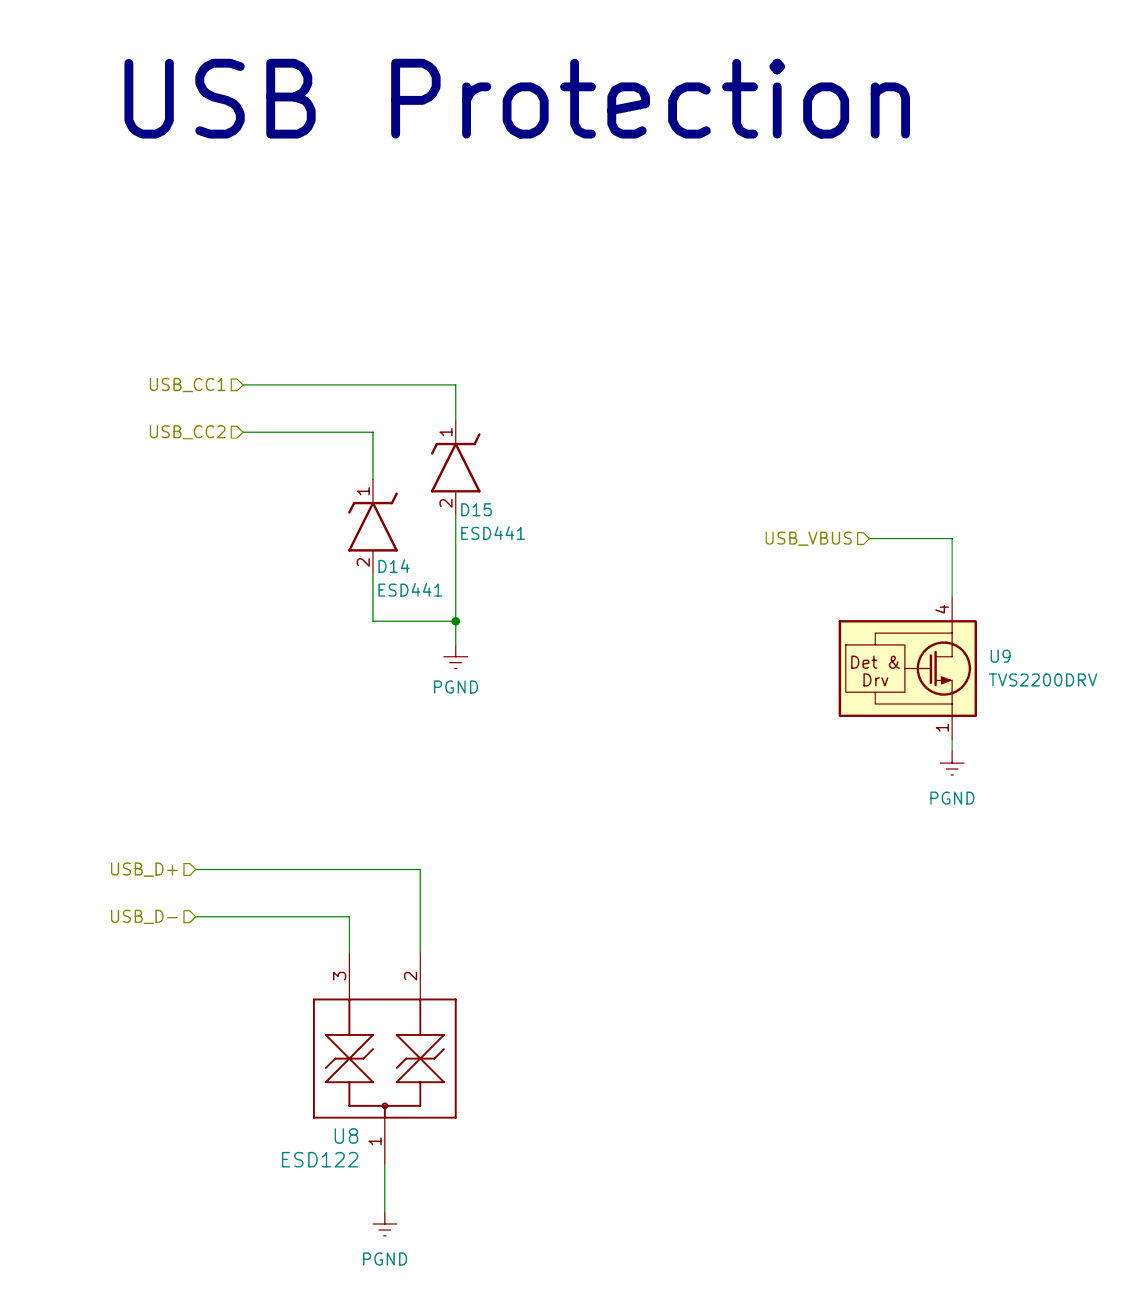
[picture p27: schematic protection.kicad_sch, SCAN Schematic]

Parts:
D14, D15: ESD441; X2SON2_DPL_TEX; Manufacturer_Part_Number ESD441DPLR; JLCPCB Part Number C22427765
U8: ESD122; DMY0003A; MFR_PN ESD122DMYR; JLCPCB Part Number C1975871
U9: TVS2200DRV; WSON-6-1EP_2x2mm_P0.65mm_EP1x1.6mm; MFR_PN TVS2200DRVR; JLCPCB Part Number C523793

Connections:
/USB_CC1: D15.1; also elsewhere on the board
/USB_CC2: D14.1; also elsewhere on the board
/USB_D+: U8.2; also elsewhere on the board
/USB_D-: U8.3; also elsewhere on the board
/USB_VBUS: U9.4 (IN), U9.5 (IN), U9.6 (IN); also elsewhere on the board
PGND: D14.2, D15.2, U8.1, U9.1 (GND), U9.2 (GND), U9.3 (GND), U9.7 (GND); also elsewhere on the board

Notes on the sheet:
USB Protection

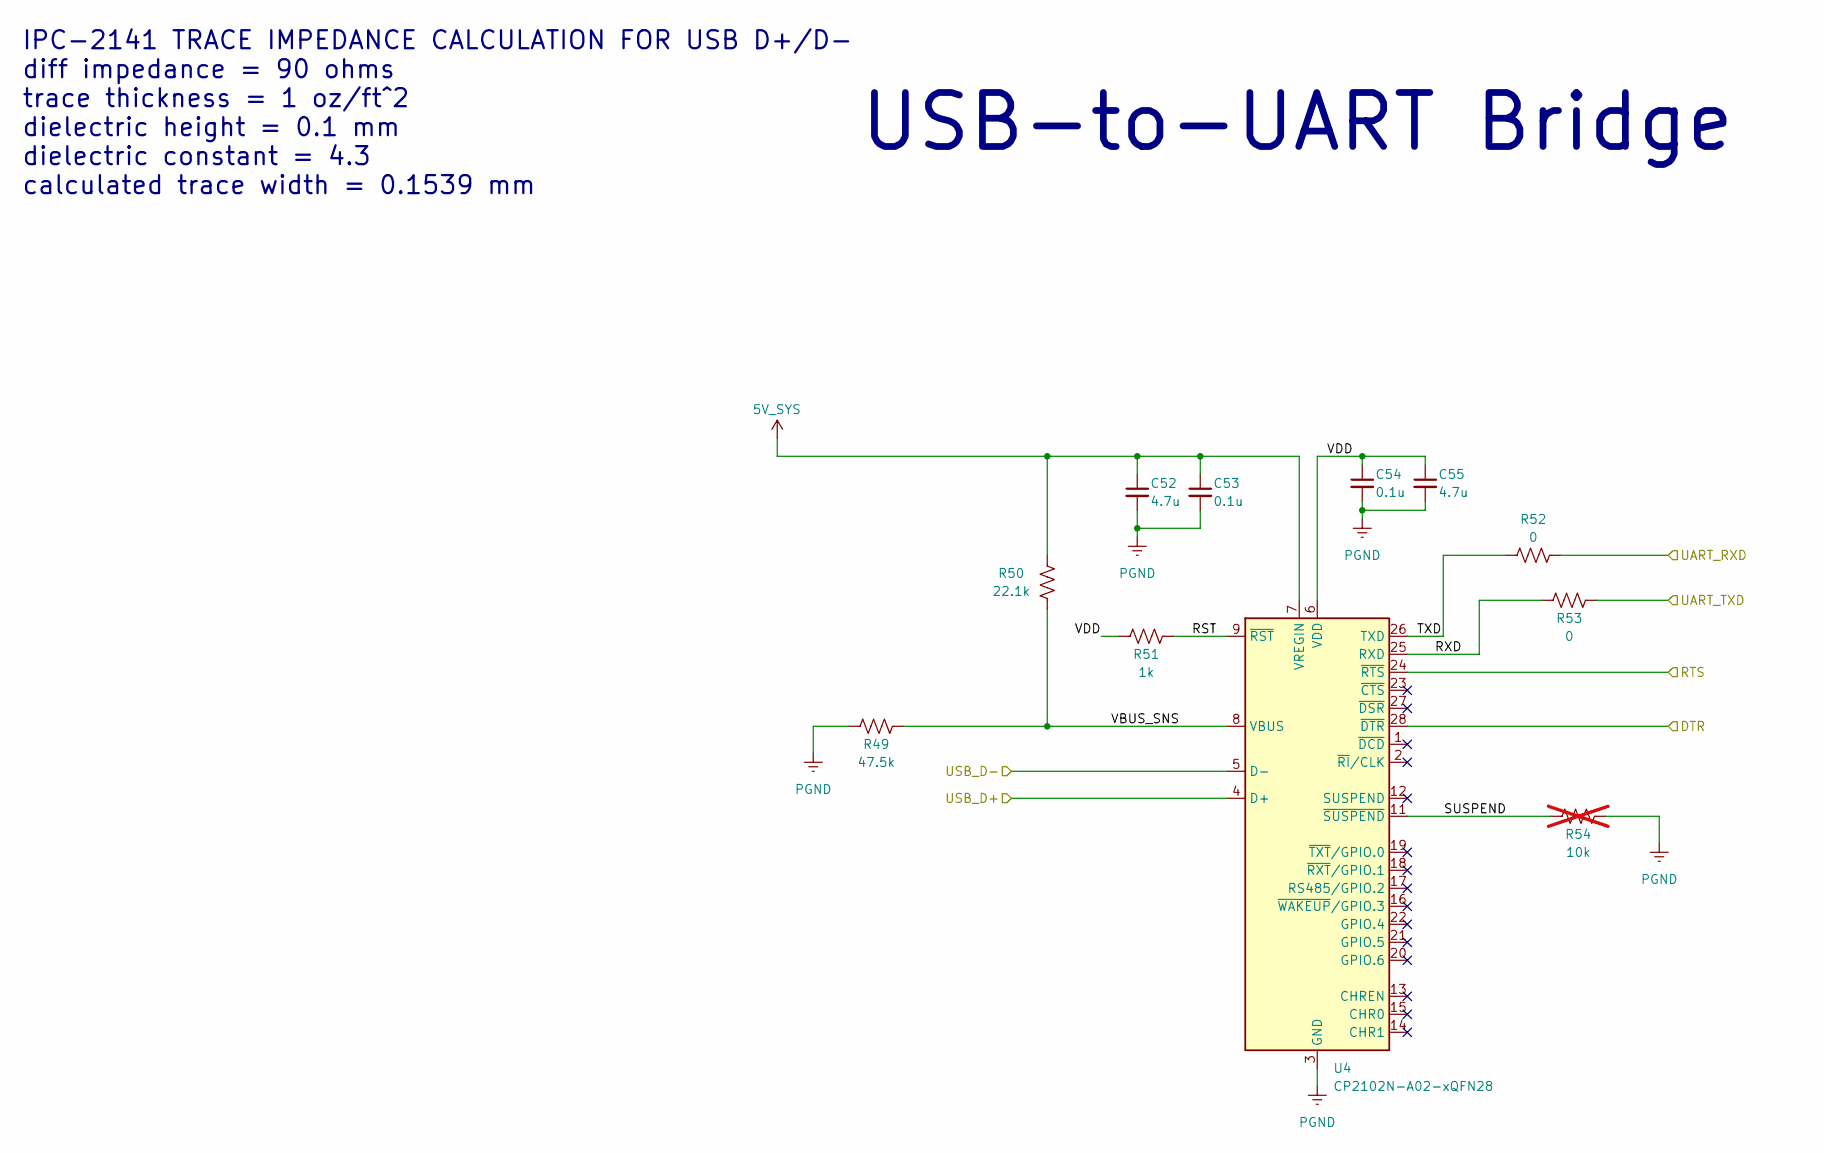
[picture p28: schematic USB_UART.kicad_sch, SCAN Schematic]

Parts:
C52, C55: 4.7u; C_0603_1608Metric; MFR_PN GRM188R61C475KAAJD; JLCPCB Part Number C86016
C53, C54: 0.1u; C_0402_1005Metric; MFR_PN GRM155R71A104KA01D; JLCPCB Part Number C71687
R49: 47.5k; R_0402_1005Metric; MFR_PN RC0402FR-0747K5L; JLCPCB Part Number C137974
R50: 22.1k; R_0402_1005Metric; MFR_PN RC0402FR-0722K1L; JLCPCB Part Number C163478
R51: 1k; R_0402_1005Metric; MFR_PN RC0402JR-071KL; JLCPCB Part Number C105637
R52, R53: 0; R_0805_2012Metric; MFR_PN RC0805JR-070RL; JLCPCB Part Number C96345
R54: 10k; R_0805_2012Metric; MFR_PN CRCW080510K0FKEAC; JLCPCB Part Number C844814; not fitted
U4: CP2102N-A02-xQFN28; QFN-28-1EP_5x5mm_P0.5mm_EP3.35x3.35mm; MFR_PN CP2102N-A02-GQFN28; JLCPCB Part Number C1550553

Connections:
5V_SYS: C52.1, C53.1, R50.2, U4.7 (VREGIN); also elsewhere on the board
/Auto Download/DTR: U4.28 (~DTR); also elsewhere on the board
/Auto Download/RTS: U4.24 (~RTS); also elsewhere on the board
/UART_RXD: R52.2; also elsewhere on the board
/UART_TXD: R53.2; also elsewhere on the board
/USB-to-UART Bridge/RST: R51.2, U4.9 (~RST)
/USB-to-UART Bridge/RXD: R53.1, U4.25 (RXD)
/USB-to-UART Bridge/SUSPEND: R54.1, U4.11 (~SUSPEND)
/USB-to-UART Bridge/TXD: R52.1, U4.26 (TXD)
/USB-to-UART Bridge/VBUS_SNS: R49.2, R50.1, U4.8 (VBUS)
/USB-to-UART Bridge/VDD: C54.1, C55.1, R51.1, U4.6 (VDD)
/USB_D+: U4.4 (D+); also elsewhere on the board
/USB_D-: U4.5 (D-); also elsewhere on the board
PGND: C52.2, C53.2, C54.2, C55.2, R49.1, R54.2, U4.3 (GND), U4.29 (GND); also elsewhere on the board

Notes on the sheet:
IPC-2141 TRACE IMPEDANCE CALCULATION FOR USB D+/D- diff impedance = 90 ohms trace thickness = 1 oz/ft^2 dielectric height = 0.1 mm dielectric constant = 4.3 calculated trace width = 0.1539 mm
USB-to-UART Bridge

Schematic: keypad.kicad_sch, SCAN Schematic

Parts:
J8: Keypad; PinHeader_1x08_P2.54mm_Horizontal
R61: 10k; R_0805_2012Metric; MFR_PN CRCW080510K0FKEAC; JLCPCB Part Number C844814
U7: PCF8574; DIP794W45P254L1969H508Q16; MFR_PN PCF8574N; JLCPCB Part Number C2879047

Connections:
3.3V_SYS: R61.1, U7.16 (VDD); also elsewhere on the board
/I2C_SCL: U7.14 (SCL); also elsewhere on the board
/I2C_SDA: U7.15 (SDA); also elsewhere on the board
/KEYPAD_INT: R61.2, U7.13 (~INT); also elsewhere on the board
/Keypad/P0: J8.1, U7.4 (P0)
/Keypad/P1: J8.2, U7.5 (P1)
/Keypad/P2: J8.3, U7.6 (P2)
/Keypad/P3: J8.4, U7.7 (P3)
/Keypad/P4: J8.5, U7.9 (P4)
/Keypad/P5: J8.6, U7.10 (P5)
/Keypad/P6: J8.7, U7.11 (P6)
/Keypad/P7: J8.8, U7.12 (P7)
PGND: U7.1 (A0), U7.2 (A1), U7.3 (A2), U7.8 (VSS); also elsewhere on the board

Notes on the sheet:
Keypad Bus Expander

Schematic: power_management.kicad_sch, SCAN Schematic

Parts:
C4, C5: 1u; C_0805_2012Metric; MFR_PN GRM219R71E105KA88D; JLCPCB Part Number C86035; not fitted
C6: 10u; C_0805_2012Metric; MFR_PN GRM21BR61E106KA73L; JLCPCB Part Number C84416; not fitted
C7, C34, C36, C37: 10u; C_0805_2012Metric_Pad1.18x1.45mm_HandSolder; MFR_PN GRM21BR61E106KA73L; JLCPCB Part Number C84416; not fitted
C8, C9, C23, C24, C26, C27, C29, C30, C32, C35: 10u; C_0805_2012Metric_Pad1.18x1.45mm_HandSolder; MFR_PN GRM21BR61E106KA73L; JLCPCB Part Number C84416
C10, C11, C14, C20, C21: 0.1u; C_0402_1005Metric; MFR_PN GRM155R71H104KE14D; JLCPCB Part Number C77020
C12, C13: 1nF; C_0402_1005Metric; MFR_PN GRM1555C1H102FA01D; JLCPCB Part Number C161523
C15, C16: 0.01u; C_0402_1005Metric; MFR_PN C0402C103J5RACTU; JLCPCB Part Number C2167955; not fitted
C17: 4.7u; C_0603_1608Metric; MFR_PN GRM188R61C475KAAJD; JLCPCB Part Number C86016
C18, C19: 47n; C_0402_1005Metric; MFR_PN GRM155R71E473KA88D; JLCPCB Part Number C77017
C22: 0.1u; C_0402_1005Metric; MFR_PN GRM155R71H104KE14D; JLCPCB Part Number C77020; not fitted
C25, C28: 10u; C_0603_1608Metric; MFR_PN GRT188R61E106ME13D; JLCPCB Part Number C697423
C31: 1n; C_0402_1005Metric; MFR_PN GRM1555C1H102FA01D; JLCPCB Part Number C161523; not fitted
C33: 10u; C_0603_1608Metric; MFR_PN GRT188R61E106ME13D; JLCPCB Part Number C697423; not fitted
C38, C40: 33u; CP_EIA-7343-31_Kemet-D; MFR_PN ECASD41E336M040KA0; JLCPCB Part Number C2161642; not fitted
C39: 33u; CP_EIA-7343-31_Kemet-D; MFR_PN T521D336M035ATE065; JLCPCB Part Number C696815; not fitted
C41: 47nF; C_0402_1005Metric; MFR_PN GRM155R71E473KA88D; JLCPCB Part Number C77017
D1, D2: 12V; D_SOD-523; MFR_PN BZT52C12T-7; JLCPCB Part Number C507911
D3, D4, D6: 40V; D_SOD-523; MFR_PN ZLLS350TA; JLCPCB Part Number C139441; not fitted
D5: GREEN; LED_0603_1608Metric; MFR_PN LTST-C190KGKT; JLCPCB Part Number C125094
D7: 12V; D_SOD-523; MFR_PN BZT52C12T-7; JLCPCB Part Number C507911; not fitted
L1: 1.0u; SPM6530; MFR_PN SPM6530T-1R0M120; JLCPCB Part Number C87572
NT1: NetTie_2; custom_net_tie
Q1, Q2, Q3, Q4: CSD17581Q3A; VSON-8_3.3x3.3mm_P0.65mm_NexFET; MFR_PN CSD17581Q3AT; JLCPCB Part Number C2866708
Q5: CSD17575Q3; VSON-8_3.3x3.3mm_P0.65mm_NexFET; MFR_PN CSD17575Q3T; JLCPCB Part Number C2865030
R5, R6, R21, R22: 0.01; R_2010_5025Metric; MFR_PN WSL2010R0100FEA18; JLCPCB Part Number C844898
R7: 10k; R_0805_2012Metric; MFR_PN CRCW080510K0FKEAC; JLCPCB Part Number C844814
R8, R9, R18: 100k; R_0402_1005Metric; MFR_PN RC0402FR-07100KL; JLCPCB Part Number C60491; not fitted
R10, R11, R19: 0; R_0805_2012Metric; MFR_PN 5106; JLCPCB Part Number C2073530; not fitted
R12: 0; R_0805_2012Metric; MFR_PN RC0805JR-070RL; JLCPCB Part Number C96345
R13, R14: 294; R_0603_1608Metric; MFR_PN RC0603FR-07294RL; JLCPCB Part Number C185345
R15: 18k; R_0603_1608Metric; MFR_PN AC0603FR-0718KL; JLCPCB Part Number C144693
R16: 2.2k; R_0402_1005Metric; MFR_PN RC0402FR-072K21L; JLCPCB Part Number C138019
R17: 0; R_0603_1608Metric; MFR_PN CRCW06030000Z0EA; JLCPCB Part Number C844915
R20: 100; R_0603_1608Metric; MFR_PN RC0603FR-07100RL; JLCPCB Part Number C105588
R23: 5.23k; R_0402_1005Metric; MFR_PN CRCW04025K23FKED; JLCPCB Part Number C2076550
R24: 30.1k; R_0402_1005Metric; MFR_PN RC0402FR-0730K1L; JLCPCB Part Number C138009
RT1: 10k; 103AT2; Mouser Part Number 954-103AT-2
SW1: QON; SW_SPST_PTS647_Sx38; MFR_PN PTS647SM38SMTR2 LFS; DigiKey Part Number PTS647SM38SMTR2LFSCT-ND
U2: BQ25798RQMR; IC_BQ25798RQMR; MFR_PN BQ25798RQMR; JLCPCB Part Number C2876593

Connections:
3.3V_SYS: R7.1, R16.1; also elsewhere on the board
/BAT+: R22.2; also elsewhere on the board
/BQ25798_INT: R7.2, U2.21 (INT_N); also elsewhere on the board
/I2C_SCL: U2.14 (SCL); also elsewhere on the board
/I2C_SDA: U2.15 (SDA); also elsewhere on the board
/PV_IN: R6.1; also elsewhere on the board
/Power Management/ACDRV1: C15.1, D3.1 (K), R13.2, U2.11 (ACDRV1)
/Power Management/ACDRV2: C16.1, D4.1 (K), R14.2, U2.10 (ACDRV2)
/Power Management/BAT: C22.1, C25.1, C28.1, C31.1, C33.1, D7.2 (A), Q5.1 (S), Q5.2 (S), Q5.3 (S), R18.2, R19.1, U2.22 (BAT), U2.23 (BAT)
/Power Management/BATP: C41.1, R20.1, U2.18 (BATP)
/Power Management/BTST1: C18.1, U2.4 (BTST1)
/Power Management/BTST2: C19.1, U2.19 (BTST2)
/Power Management/ILIM_HIZ: R12.1, U2.17 (ILIM_HIZ)
/Power Management/PMID: C20.1, C23.1, C26.1, C30.1, C34.1, C36.1, C38.1, C40.1, U2.29 (PMID)
/Power Management/PROG: R15.2, U2.20 (PROG)
/Power Management/QON: SW1.1, U2.12 (QON_N)
/Power Management/REGN: C17.1, R12.2, R23.1, U2.5 (REGN)
/Power Management/SDRV: D6.1 (K), R17.1, U2.24 (SDRV)
/Power Management/STAT: D5.1 (K), U2.1 (STAT)
/Power Management/SW1: C18.2, L1.1, U2.28 (SW1)
/Power Management/SW2: C19.2, L1.2, U2.26 (SW2)
/Power Management/SYS: C21.1, C24.1, C27.1, C29.1, C32.1, C35.1, C37.1, C39.1, R21.1, U2.25 (SYS)
/Power Management/TS: R23.2, R24.1, RT1.2, U2.16 (TS)
/Power Management/VAC1: C4.1, C11.1, Q1.5 (D), R5.2, R10.1, U2.9 (VAC1)
/Power Management/VAC2: C5.1, C14.1, Q2.5 (D), R6.2, R11.1, U2.8 (VAC2)
/Power Management/VBUS: C6.1, C7.1, C8.1, C9.1, C10.1, Q3.5 (D), Q4.5 (D), R10.2, R11.2, U2.2 (VBUS), U2.3 (VBUS)
/SYSTEM: R21.2; also elsewhere on the board
/VDC: R5.1; also elsewhere on the board
AGND: C11.2, C14.2, C15.2, C16.2, NT1.1, R15.1, R24.2, RT1.1, SW1.2, U2.13 (CE_N)
unnamed: C12.1, D1.2 (A), Q1.1 (S), Q1.2 (S), Q1.3 (S), Q3.1 (S), Q3.2 (S), Q3.3 (S), R8.1
unnamed: C12.2, D1.1 (K), D3.2 (A), Q1.4 (G), Q3.4 (G), R8.2, R13.1
unnamed: C13.1, D2.2 (A), Q2.1 (S), Q2.2 (S), Q2.3 (S), Q4.1 (S), Q4.2 (S), Q4.3 (S), R9.1
unnamed: C13.2, D2.1 (K), D4.2 (A), Q2.4 (G), Q4.4 (G), R9.2, R14.1
unnamed: D5.2 (A), R16.2
unnamed: C31.2, D6.2 (A), D7.1 (K), Q5.4 (G), R17.2, R18.1
unnamed: Q5.5 (D), R19.2, R20.2, R22.1
PGND: C4.2, C5.2, C6.2, C7.2, C8.2, C9.2, C10.2, C17.2, C20.2, C21.2, C22.2, C23.2, C24.2, C25.2, C26.2, C27.2, C28.2, C29.2, C30.2, C32.2, C33.2, C34.2, C35.2, C36.2, C37.2, C38.2, C39.2, C40.2, C41.2, NT1.2, U2.27 (GND); also elsewhere on the board

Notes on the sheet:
At POR and WDT reset... Fsw = 1.5 MHz Battery Cell Count (REG0x0A[7:6]): 4s ICHG (REG0x03/04): 1 A VSYSMIN (REG0x00[5:0]): 12 V VREG (REG0x01/02): 16.8 V VREG Range: 14 V - 18.8 V
Power Management

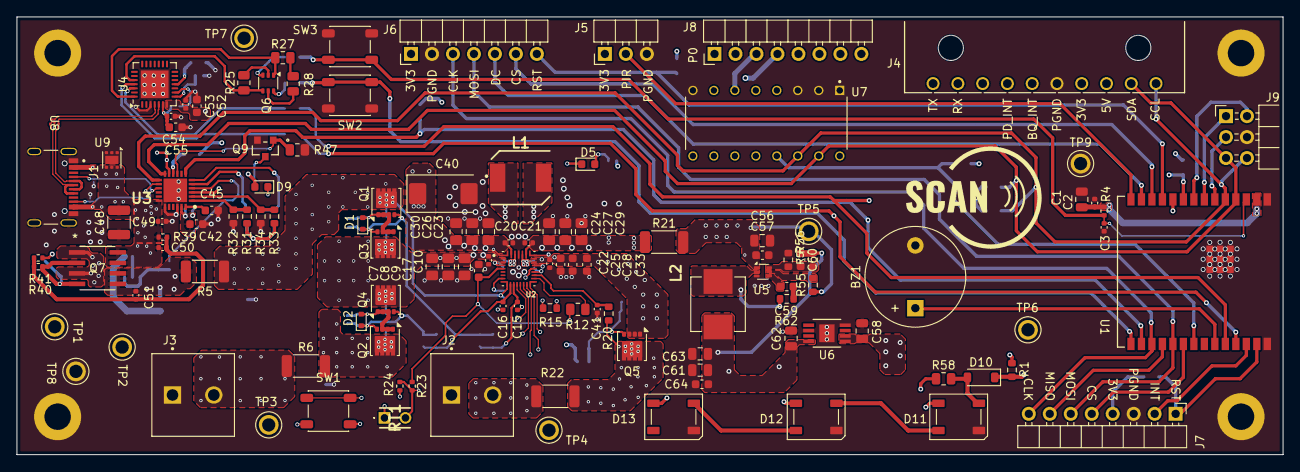
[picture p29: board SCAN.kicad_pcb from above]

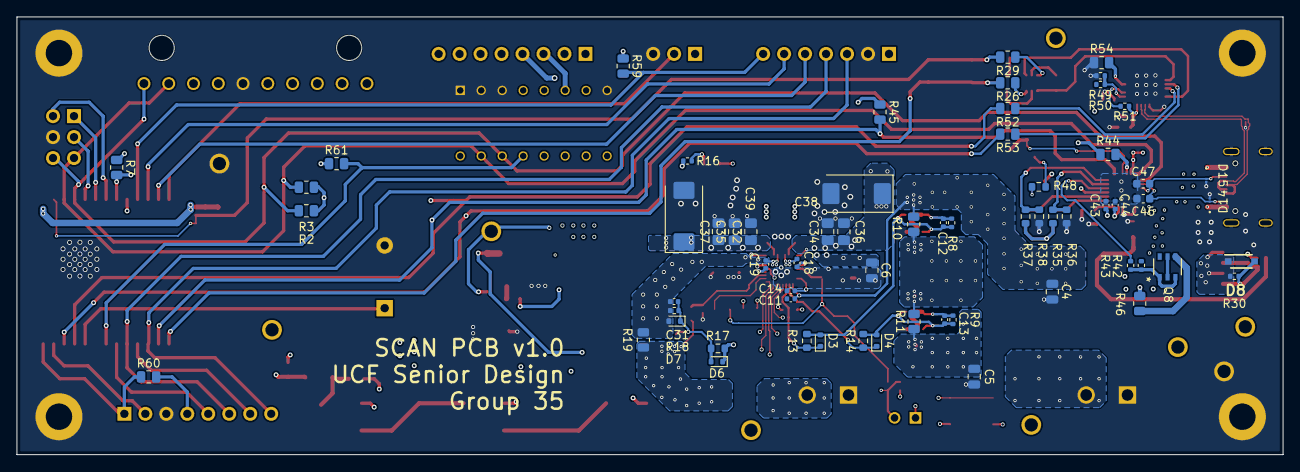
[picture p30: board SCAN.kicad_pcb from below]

Board: 6 copper layers, 153.3 x 53.0 mm, 189 parts (64 on the bottom side), 111 nets.

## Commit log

2025-02-15 finished routing SCAN mainboard. Flagged for Dre review
    [SCAN_mainboard.kicad_pcb]
2025-02-16 final commit before ordering mainboard rev1
    [SCAN_mainboard-B_Cu.gbl, SCAN_mainboard-B_Mask.gbs, SCAN_mainboard-B_Paste.gbp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]
2025-02-21 PCB work. Things to still do: 1. Add breakout pins for I2C/SPI/3V3 2. Connect AGND to PGND under BQ25798 3. Add copper fill for AGND 4. finish routing signals to ESP32 5. Check trace and via clearanc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
    [NFC.kicad_sch, SCAN.kicad_pcb, SCAN.kicad_sch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]
2025-02-24 reorganized schematic for CDR presentation
    [SCAN_mainboard.kicad_pcb, SCAN_mainboard.kicad_sch]
2025-02-25 Fixed peripherals PCB connector pinout Finished routing all but 5V Need to double check 5V regulator and 3.3V LDO layout 16 missing connections on DRC, no violations
    [SCAN.kicad_pcb, SCAN.kicad_sch, usb_power.kicad_sch]
2025-02-25 Changes: 1. Added datasheets and reference designs 2. Cleaned up folder structure
    To do:
    1. Replace USB4110-GF-A_GCT USB-C connector with
    TYPE-C-31-M-12 connector
    2. Fix DRC errors
    3. Add breakout pins for extra ESP32 pins
    4. Confirm buzzer schematic
    5. Connect AGND to PGND
    6. Name header pins on silkscreen
    7. Connect 5V traces
    [NFC.kicad_sch, PCBA_BOM.xlsm, PIR.kicad_sch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]
2025-02-26 more changes
    [NFC.kicad_sch, SCAN.kicad_pcb, SCAN.kicad_sch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]
2025-02-27 hardware changes
    [SCAN.kicad_sch, power_management.kicad_sch]
2025-02-28 Complete: 1. Replaced USB C connector 2. BOM in progress 3. Fixed some errors
    To Do:
    1. Finish BOM
    2. Connect 5V
    3. Double check layout
    4. Remove any violations/errors
    [NFC.kicad_sch, SCAN.kicad_pcb, SCAN.kicad_sch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]
2025-03-01 custom footprint for net tie on inner layer made by using text editor to manually put footprint on In2.Cu layer
    [SCAN.kicad_pcb, power_management.kicad_sch]
2025-03-02 Completed: 1. BOM progress 2. rerouted 5V buck converter and 3V3 LDO 3. Fixed some DRC violations
    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
    [NFC.kicad_sch, SCAN.kicad_pcb, SCAN.kicad_sch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]
2025-03-03 BOM finished, need to fix a few violations and then ready to order
    [NFC.kicad_sch, SCAN.kicad_pcb, SCAN.kicad_sch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]
2025-03-05 weird schematic error fixed
2025-03-05 trying to fix again
    [SCAN.kicad_pcb]
2025-03-05 trying to fix file error again
    [SCAN.kicad_sch]
2025-03-08 kicad_project changes
    [SCAN.kicad_sch, protection.kicad_sch]
2025-03-08 new commit because hardware design diverged as I switched branches
    [NFC.kicad_sch, SCAN.kicad_sch, SCAN_PCB_BOM_Rev_1.0.csv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]
2025-03-10 removing software files
    [partition.csv]
2025-03-13 second revision of SCAN_PCB
    [BOM_MASTER.xlsx, NFC.kicad_sch, PCBA_BOM.xlsm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]
